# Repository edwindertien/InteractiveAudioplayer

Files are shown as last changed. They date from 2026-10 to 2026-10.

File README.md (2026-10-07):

# Interactive Audio Player
### Seven wearable players · Teensy 4.1 · 7.1 multichannel audio · NFC hand units · haptics

An embedded system for immersive, location-and-encounter based experiences. Each of up to
seven wearers carries a **hand unit** (NFC reader, distance sensor, vibration motor, LED strip).
Touching a hand unit to an **NFC tag** — another person's tag, a narrator tag, an overlay tag
or the start tag — changes what that wearer hears: the audio, a narration layer, overlays,
sound effects and a haptic channel that is felt through the body. The audio itself is a single
8-channel WAV file on an SD card inside each player.

This README is in two parts.

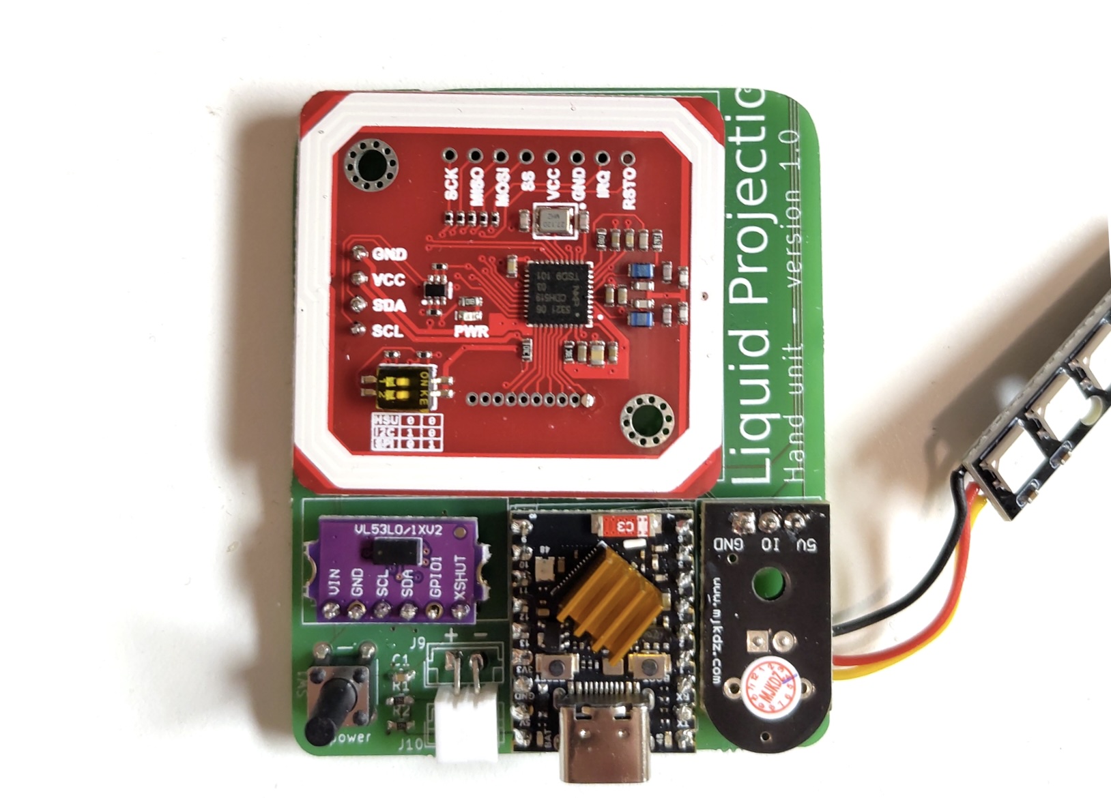
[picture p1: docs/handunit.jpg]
hand unit


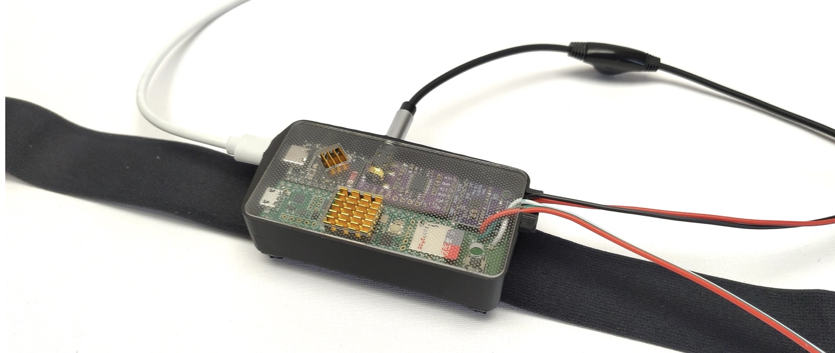
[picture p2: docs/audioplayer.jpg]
audio player


* **Part I — Operation manual:** preparing audio, the SD card and the configuration files,
  pairing the units, and running a show. Everything here needs no programming.
* **Part II — Building and programming:** hardware, setting up VS Code and PlatformIO, flashing
  the three devices, the project structure, and how the software works.

Background on design decisions, dead ends and open issues lives in [Context.md](Context.md).

> **Figures.** Every figure is a PNG; click it for the zoomable SVG. They are generated by
> `tools/make_docs.py` (see [section 17](#17-regenerating-the-figures)).

## Contents

**Part I — Operation manual**
1. [The system at a glance](#1-the-system-at-a-glance)
2. [The workflow in one picture](#2-the-workflow-in-one-picture)
3. [Preparing the audio](#3-preparing-the-audio)
4. [Preparing the SD card](#4-preparing-the-sd-card)
5. [Tags and the configuration files](#5-tags-and-the-configuration-files)
6. [Pairing hand units and body bridges](#6-pairing-hand-units-and-body-bridges)
7. [Running a show](#7-running-a-show)
8. [Changing files without removing the card (USB mode)](#8-changing-files-without-removing-the-card-usb-mode)
9. [Command reference](#9-command-reference)
10. [Troubleshooting](#10-troubleshooting)

**Part II — Building and programming**

11. [Hardware](#11-hardware)
12. [Setting up the development environment](#12-setting-up-the-development-environment)
13. [Building and flashing](#13-building-and-flashing)
14. [Project structure](#14-project-structure)
15. [How it works](#15-how-it-works)
16. [Tools reference](#16-tools-reference)
17. [Regenerating the figures](#17-regenerating-the-figures)

---

# Part I — Operation manual

## 1. The system at a glance

Each player is a set of three devices plus the wearer's tags:

| Device | What it is | What it does |
|---|---|---|
| **Hand unit** | ESP32-S3 SuperMini + PN532 NFC + VL53L0X distance sensor + vibration motor + 5-LED strip + LiPo | Reads tags, feels the distance to a hand, gives instant feedback (vibration, light) and reports to the body bridge |
| **Body bridge** | ESP32-S3 SuperMini | Receives the hand unit's wireless data (ESP-NOW) and passes it to the Teensy over a two-wire serial link; sends a heartbeat back |
| **Player** | Teensy 4.1 + SD card + PCM5102A (headphones) + MAX98357A (haptics) + LED ring | Plays the experience, decides what a tag means, drives headphones and the haptic transducer |

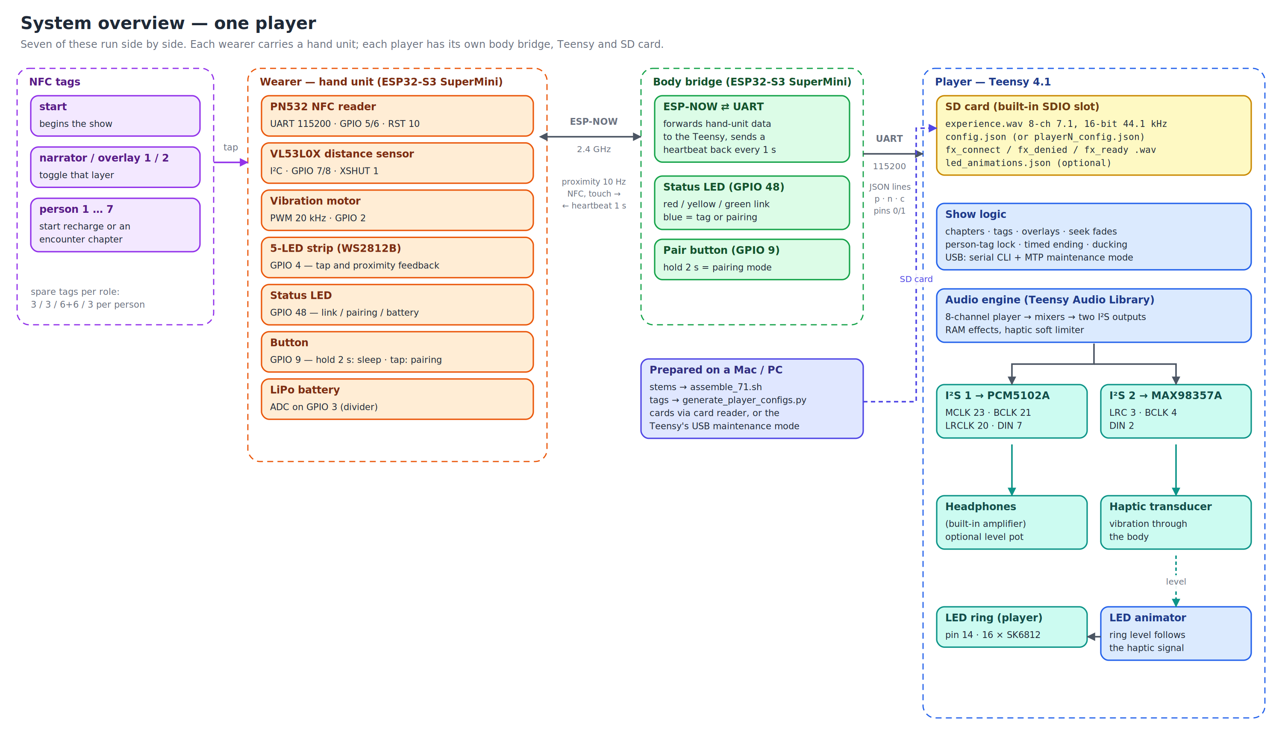
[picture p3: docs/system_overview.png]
System overview


*Seven players run side by side, each with its own hand unit, body bridge, Teensy and SD card.
The pairs are independent: a hand unit talks to exactly one body bridge.*

## 2. The workflow in one picture

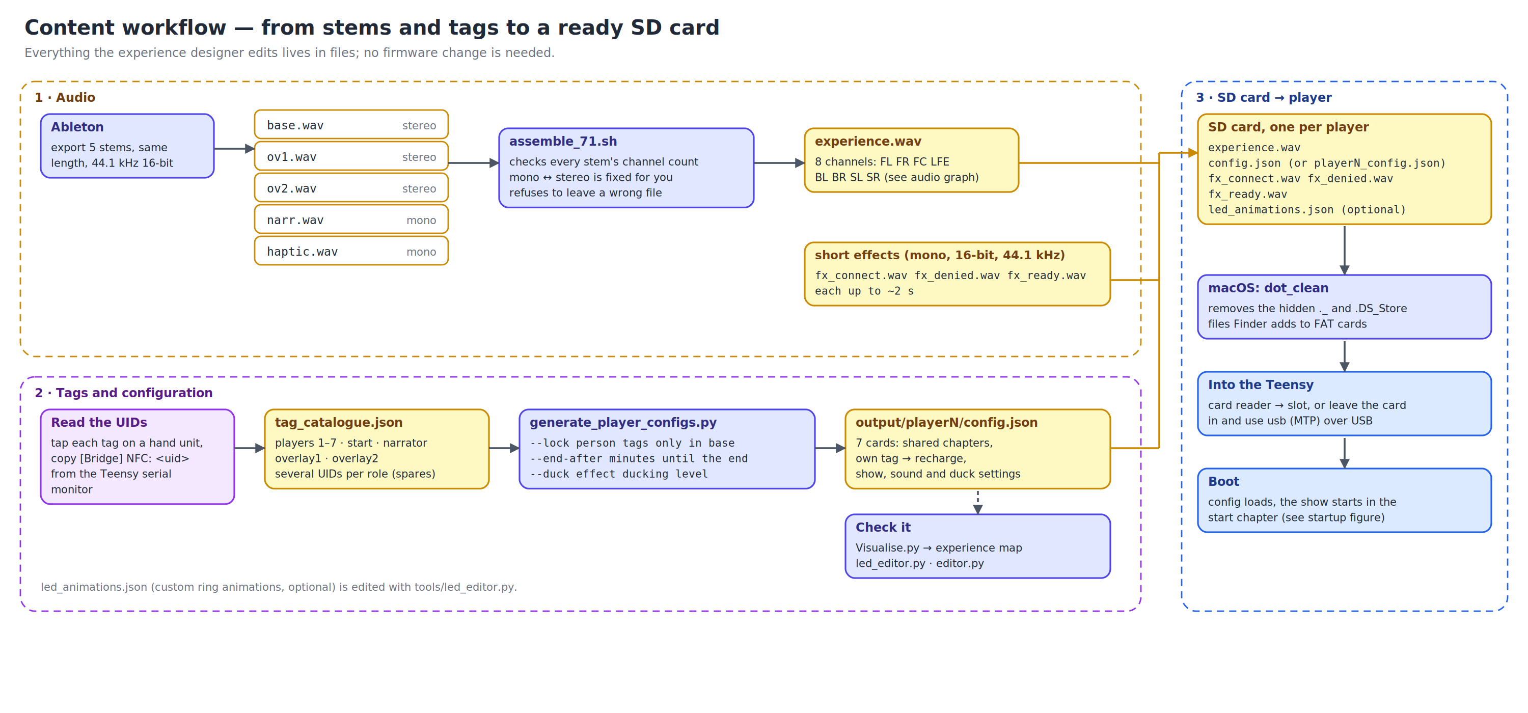
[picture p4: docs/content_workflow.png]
Content workflow


Everything the experience designer edits is a **file**. Nothing in this manual needs a firmware
change. The short version:

1. Export five stems from Ableton and run `assemble_71.sh` → `experience.wav`.  → [section 3](#3-preparing-the-audio)
2. Format the SD cards and copy the files; clean the hidden macOS files.  → [section 4](#4-preparing-the-sd-card)
3. Read the tag UIDs, fill in `tag_catalogue.json`, run `generate_player_configs.py` → seven `config.json`.  → [section 5](#5-tags-and-the-configuration-files)
4. Pair each hand unit with its body bridge.  → [section 6](#6-pairing-hand-units-and-body-bridges)
5. Power everything up and run the show.  → [section 7](#7-running-a-show)

**Tools you need on the Mac/PC:** Python 3, `ffmpeg` (`brew install ffmpeg`), and a serial
monitor (VS Code with PlatformIO, see [section 12](#12-setting-up-the-development-environment),
or any terminal program at 115200 baud).

---

## 3. Preparing the audio

### 3.1 Export the stems from Ableton

Export five files — all **the same length**, on the same tempo grid, **44100 Hz, 16-bit**:

| File | Channels | Content |
|---|---|---|
| `base.wav` | stereo | The main music bed |
| `narr.wav` | **mono** | Narration / operator cues |
| `ov1.wav` | stereo | Overlay stem 1 |
| `ov2.wav` | stereo | Overlay stem 2 |
| `haptic.wav` | **mono** | Low-frequency content that is felt, not heard (the LFE channel) |

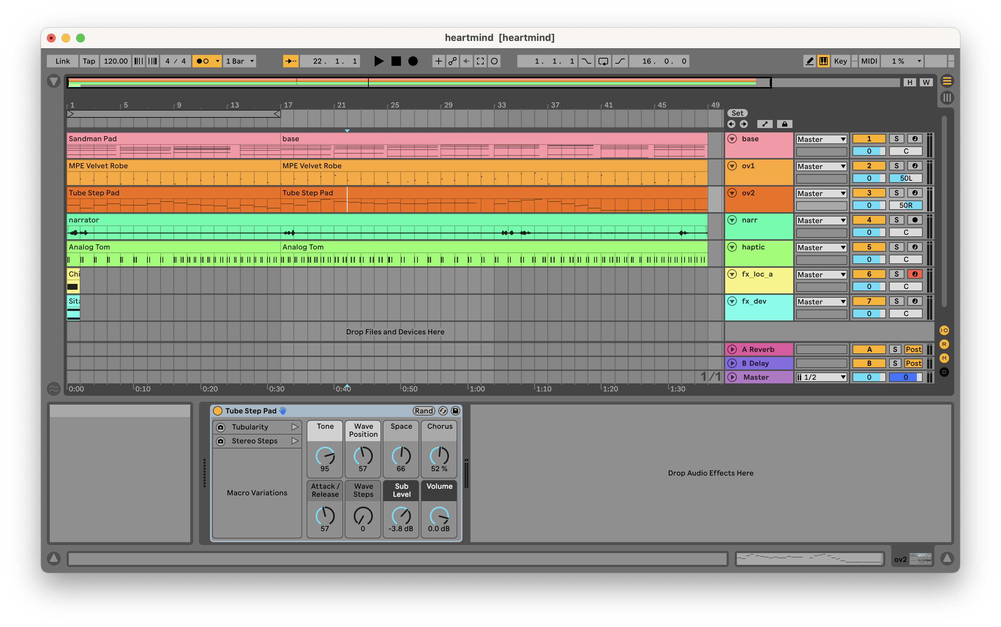
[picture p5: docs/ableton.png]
Ableton arrangement view showing the stem tracks


*The Ableton arrangement: base, narration, two overlays and the haptic stem exported separately.*

> **Mono export in Ableton:** *File → Export Audio/Video* → tick **Convert to Mono**.

### 3.2 Assemble the 8-channel file

```bash
chmod +x experience/assemble_71.sh
./experience/assemble_71.sh base.wav narr.wav ov1.wav ov2.wav haptic.wav experience.wav
```

The script checks every stem's channel count before merging, so a wrong export can no longer
silently shift every later channel:

* `narr.wav` / `haptic.wav` exported as **stereo** → reduced to mono (`(L+R)/2`; set
  `MONO_MODE=left` to take the left channel only). A dual-mono file keeps its exact level.
* `base.wav` / `ov1.wav` / `ov2.wav` exported as **mono** → duplicated to both channels.
* Anything with more than 2 channels, or a file that is not audio → refused with a message.
* The finished file must be **8 channels at 44100 Hz**; if not, it is deleted and the script
  fails. An existing `experience.wav` is left alone if the script fails before writing.
* **Different stem lengths:** the output is cut to the *shortest* stem. The script prints a
  warning with the shortest and longest length — fix the export, otherwise the end of the
  longer stems is silently lost.

Channel order of `experience.wav` (standard 7.1):

| Index | Name | Content | Goes to |
|---|---|---|---|
| 0 | FL | base L | headphones L (always on) |
| 1 | FR | base R | headphones R (always on) |
| 2 | FC | narration | both ears, fades in/out when toggled |
| 3 | LFE | haptic | MAX98357A → haptic transducer, and the player's LED ring |
| 4 | BL | overlay 1 L | headphones L, fades in/out when toggled |
| 5 | BR | overlay 1 R | headphones R, fades in/out when toggled |
| 6 | SL | overlay 2 L | headphones L, fades in/out when toggled |
| 7 | SR | overlay 2 R | headphones R, fades in/out when toggled |

A 7.5-minute experience is about **317 MB** (450 s × 44 100 × 2 bytes × 8 channels).

### 3.3 The sound effects

Three short effects give feedback for tag events. They are loaded into RAM at boot and played
without touching the SD card.

| File | Played when | Slot |
|---|---|---|
| `fx_connect.wav` | a person tag was accepted (a new chapter starts) | 4 |
| `fx_denied.wav` | a person tag was refused (lock on and not in base, or the show is ending) | 5 |
| `fx_ready.wav` | an encounter has ended and you are back in base, ready for the next | 6 |

**Format requirement: 16-bit PCM, mono, 44.1 kHz, up to about 2 seconds.** The player labels
every effect as mono 44.1 kHz and does not resample, so a stereo or 48 kHz file plays at the
wrong speed. The boot log prints one line per effect, e.g.
`slot 4: fx_connect.wav loaded (1ch 420ms … bytes RAM)` — `1ch` confirms a mono file.

Four older slots (`fx_dev.wav`, `fx_loc_a.wav`, `fx_loc_b.wav`, `fx_boot.wav`, slots 0–3) are
still loaded if present and can be triggered by `"do": "fx"` actions or `on_enter_fx`. If the
files are absent you will see four harmless `cannot open` lines at boot.

While any effect plays, the general audio is **ducked** (lowered) so the effect can be heard —
see `duck_level` in [section 5.4](#54-the-configuration-file-reference).

---

## 4. Preparing the SD card

Use a **SanDisk Ultra or Extreme (A1/A2, UHS-I)** card. A generic Class-4 card produced
audible glitches in testing. 16–32 GB is plenty. The Teensy's **built-in slot** (underside of
the board) is used, not a shield's slot.

### 4.1 What goes on the card

```
/ (SD card root)
├── experience.wav          the 8-channel audio (same file on every card)
├── config.json             this player's configuration (differs per card)
├── fx_connect.wav          effect: a person tag was accepted
├── fx_denied.wav           effect: a person tag was refused
├── fx_ready.wav            effect: back in base, ready for the next encounter
└── led_animations.json     optional: custom LED ring animations
```

`config.json` may also be called `playerN_config.json` (for example `player3_config.json`) so
the card is easy to recognise. The player opens **`/config.json`** if it exists; otherwise it
uses the **one** file in the card root whose name ends in `_config.json`. If there are several
such files it refuses to guess and loads nothing — keep exactly one. Hidden macOS `._…` files and
folders are ignored.

### 4.2 Formatting (macOS)

1. Insert the card, open **Disk Utility**, choose *View → Show All Devices*.
2. Select the **card itself** (the top-level device, not the volume below it).
3. Click **Erase** and set:
   * **Name:** something recognisable, e.g. `PLAYER3`
   * **Format:** **MS-DOS (FAT)** (this is FAT32)
   * **Scheme:** **Master Boot Record**
4. Erase. On Windows use the SD Association's *SD Memory Card Formatter* (FAT32).

### 4.3 Copying the files and cleaning up (macOS)

macOS silently writes hidden files to every FAT volume — `._filename` resource-fork files next to
each file you copy, plus `.DS_Store`, `.Spotlight-V100`, `.fseventsd` and `.Trashes`. They clutter
the directory the Teensy reads, so **always clean the card after copying**:

```bash
cp experience.wav            /Volumes/PLAYER3/
cp output/player3/config.json /Volumes/PLAYER3/
cp fx_connect.wav fx_denied.wav fx_ready.wav /Volumes/PLAYER3/

dot_clean /Volumes/PLAYER3/                      # merge/remove the ._ files
rm -rf /Volumes/PLAYER3/.Spotlight-V100 /Volumes/PLAYER3/.fseventsd /Volumes/PLAYER3/.Trashes
ls -la /Volumes/PLAYER3/                         # should list only your files
diskutil eject /Volumes/PLAYER3
```

Copying from the terminal with `cp` avoids most of the clutter; dragging in Finder creates the most.
**Run `dot_clean` again every time you change something on the card.**

### 4.4 Checking a card

Insert it, power the Teensy and open the serial monitor (115200 baud). A healthy boot shows,
in this order: `[SD] mounted OK`, `[Config] Loaded: 10 chapters, 11 tags (39 uids)…`, one line
per effect, `[Boot] Auto-starting -> 'start_arrival'`, `[Audio] Experience started`. The
complete startup order is in [section 15.5](#155-startup-sequences).

If the **onboard LED on the Teensy blinks fast forever**, the SD card could not be mounted
(wrong format, damaged card, or not inserted).

---

## 5. Tags and the configuration files

### 5.1 Tag roles

| Role | Tag type | What touching it does | Spares | Cooldown |
|---|---|---|---|---|
| **start** | `start` | jump to `base` **and start the show clock** (restarts the show if seen again) | 3 | 2 s |
| **person 1…7** | `person` | start a chapter: your **own** person's tag → `recharge`; the other six → `enc_play`, `enc_suspense`, `enc_loneliness`, `enc_nurture`, `enc_pressure`, `enc_shift` (ascending player number, skipping your own) | 3 per person | 4 s |
| **narrator** | `location` | toggle the narration layer | 3 | 1 s |
| **overlay 1** | `location` | toggle overlay 1 | 6 | 1 s |
| **overlay 2** | `location` | toggle overlay 2 | 6 | 1 s |

*Spares* are additional physical tags for the same role: any of them does the same thing and
they share one cooldown. You can program spares without touching any firmware.

> Overlays reset at every chapter change, because the generated chapters use
> `"overlay_mode": "fresh"`. Change a chapter to `"keep"` if an overlay should survive the change.

### 5.2 Reading a tag's UID

1. Open the Teensy's serial monitor at **115200 baud**.
2. Touch the tag to a paired hand unit.
3. Every detection is logged: `[Bridge] NFC: DE0CC698`. Copy the UID.
4. A tag that is not in the config additionally prints
   `[Bridge] Unknown tag: DE0CC698 -- add to config.json` when it is *confirmed*.

To check which role a UID already has: type `tag DE0CC698` in the Teensy serial monitor.

### 5.3 Generating the seven configs

All seven players share the same chapter timeline; only the `tags` section differs. Both the
timeline and the tag logic are generated by a script from one catalogue file.

1. Fill in **`configs/tag_catalogue.json`** — every physical tag, by role. Empty strings are spare
   slots that are not programmed yet (up to 8 tags per role):

   ```json
   {
     "players":  { "1": ["5040DABE", "", ""], "2": ["1033D9BE", "", ""], "...": [] },
     "start":    ["302FD9BE", "", ""],
     "narrator": ["805ADABE", "", ""],
     "overlay1": ["7034DABE", "", "", "", "", ""],
     "overlay2": ["", "", "", "", "", ""]
   }
   ```

2. Run the generator:

   ```bash
   python3 configs/generate_player_configs.py                 # testing build
   python3 configs/generate_player_configs.py --lock          # show build
   python3 configs/generate_player_configs.py --end-after 12 --duck 0.3
   ```

   | Option | Meaning | Default |
   |---|---|---|
   | `--lock` | person tags are only accepted while `base` is playing | off (switch at any time — for testing) |
   | `--end-after MIN` | minutes after the start tag until the ending begins; `0` = never | 10 |
   | `--duck LEVEL` | general-audio level while an effect plays, 0–1; `1` = no ducking | 0.4 |
   | `--catalogue`, `--out` | other input / output location | `configs/tag_catalogue.json`, `output/` |

3. The result is `output/player1/config.json` … `output/player7/config.json`. The generator
   prints how many tags each role still needs, refuses duplicate, malformed or over-limit UIDs
   (and writes nothing in that case), and warns about roles that have no tags yet.

4. **Re-run it and re-copy the configs to the cards whenever you change the catalogue.**

### 5.4 The configuration file reference

You normally never edit a generated config by hand, but you can: it is plain JSON, and changing
a card needs no reflash. Top level:

```json
{
  "device_id":      "PLAYER_1",
  "start_chapter":  "start_arrival",
  "led_brightness": 120,
  "idle":           { "led": { "animation": "breathe", "color": "0x000066", "intensity": 0.35, "speed": 0.2 } },

  "encounter_lock": false,
  "base_chapter":   "base",
  "sounds":         { "connect": 4, "denied": 5, "ready": 6 },
  "end_after_min":  10,
  "end_chapter":    "end_reflection",
  "duck_level":     0.4,

  "chapters": [ … ],
  "tags":     [ … ]
}
```

| Field | Meaning | If absent |
|---|---|---|
| `device_id` | name shown in the boot log | `UNIT_01` |
| `start_chapter` | chapter that plays from power-on (the waiting room) | `intro` |
| `led_brightness` | global LED brightness, 0–255 | 160 |
| `idle.led` | ring pattern when nothing is playing | — |
| `encounter_lock` | `true`: person tags only accepted in `base_chapter` | `false` |
| `base_chapter` | the hub chapter the lock refers to | `base` |
| `sounds` | RAM effect slot per event; `-1` = silent | all `-1` |
| `end_after_min` | minutes after the start tag until the ending begins (e.g. `0.5`); `0` = never | `0` |
| `end_chapter` | chapter that plays last; when it ends, sound and LEDs go off | `end_reflection` |
| `duck_level` | general audio is lowered to this fraction while an effect plays; `1` = off | `1` (off) |

#### Chapters

```json
{
  "id": "enc_play", "label": "Encounter — Play",
  "start_ms": 135000, "loop_end_ms": 180000,
  "loop": false, "returns_to": "base",
  "on_enter_fx": -1, "overlay_mode": "fresh",
  "overlays": { "ov1": false, "ov2": false, "narr": false },
  "led_background": { "animation": "level", "color": "0xCC4400", "intensity": 0.6, "speed": 0.3 },
  "led_enter":      { "animation": "flash", "color": "0xFFFFFF", "intensity": 0.6, "speed": 0.6, "duration_ms": 600 }
}
```

| Field | Description |
|---|---|
| `id` | unique name, used by tags, `start_chapter`, `returns_to`, `end_chapter` |
| `label` | human-readable name (serial debug and the map) |
| `start_ms` / `loop_end_ms` | the region of `experience.wav` this chapter plays |
| `loop` | `true`: loops between the two times · `false`: plays once |
| `returns_to` | for a non-looping chapter: the chapter to continue with when it ends; empty = go idle |
| `on_enter_fx` | RAM effect slot played on entry, `-1` = none |
| `overlay_mode` | `"fresh"`: apply `overlays` on entry · `"keep"`: inherit the current state |
| `overlays` | default state of `ov1`, `ov2`, `narr` (used when `fresh`) |
| `led_background` | the ring's persistent pattern in this chapter |
| `led_enter` | a one-shot flash when the chapter starts |

The generated timeline is ten 45-second chapters (7:30 in all):

| Chapter | Time | Plays | After it ends |
|---|---|---|---|
| `start_arrival` | 0:00 – 0:45 | loops | — (the waiting room) |
| `base` | 0:45 – 1:30 | loops | — (the hub) |
| `recharge` | 1:30 – 2:15 | once | `base` |
| `enc_play` | 2:15 – 3:00 | once | `base` |
| `enc_suspense` | 3:00 – 3:45 | once | `base` |
| `enc_loneliness` | 3:45 – 4:30 | once | `base` |
| `enc_nurture` | 4:30 – 5:15 | once | `base` |
| `enc_pressure` | 5:15 – 6:00 | once | `base` |
| `enc_shift` | 6:00 – 6:45 | once | `base` |
| `end_reflection` | 6:45 – 7:30 | once | sound and LEDs off |

To change the chapter times or LED colours for all seven cards, edit the `CHAPTERS` list in
`configs/generate_player_configs.py` and regenerate.

#### Tags and actions

```json
{
  "label": "Meet player 2 -> enc_play",
  "type": "person",
  "cooldown_ms": 4000,
  "uids": ["1033D9BE", "1033000A", "1033000B"],
  "actions": [ { "do": "chapter", "target": "enc_play" } ]
}
```

| Field | Description |
|---|---|
| `uid` and/or `uids` | one UID, or a list of spares (up to 8), upper-case hex; lower case is accepted and converted. A UID listed under two roles gives a warning; the first entry wins |
| `label` | description, shown in logs |
| `type` | `person`, `start`, `location` or the legacy `device`. Only `person` is affected by the lock and the ending; only `start` starts the clock |
| `cooldown_ms` | minimum time between two accepted touches of this role |
| `actions` | what to do (below) |

| `"do"` | Parameters | Effect |
|---|---|---|
| `"chapter"` | `"target": "id"` | jump to a chapter with a crossfade |
| `"overlay"` | `"target": "ov1"/"ov2"/"narr"`, `"value": "on"/"off"/"toggle"` | fade a layer in or out |
| `"fx"` | `"slot": 0-7` | play a RAM effect |
| `"led"` | `animation`, `color`, `intensity`, `speed`, `duration_ms` | a one-shot ring event |

A card holds at most **32 tag entries**; because spares share an entry, the full catalogue
(39 physical tags per card) needs only 11.

#### LED animations

Parameters: `color` = `"0xRRGGBB"` · `intensity` = 0–1 · `speed` = 0–1 · `duration_ms` (one-shots only).

| Name | Uses colour | Description |
|---|---|---|
| `level` | ✓ | **haptic sync** — the live envelope of the LFE channel |
| `heartbeat` | ✓ | **haptic sync** — a lub-dub shape |
| `breathe` | ✓ | smooth pulse between 25 % and 100 % |
| `solid` | ✓ | constant colour |
| `sparkle` | tint | dim base with random sparks |
| `fire` · `ocean` · `rainbow` | — | own palettes |
| `pulse_ring` | ✓ | ring expanding from the centre |
| `spin` | ✓ | an arc rotating around the ring |
| `flash` | ✓ | three quick flashes, then a dim hold |
| `confetti` | tint | random colour bursts |
| `comet` | ✓ | a dot racing with a trail |
| `off` | — | dark |

Custom animations are drawn with `tools/led_editor.py` and saved as `led_animations.json`
on the card; use the animation's `id` in any `animation` field. The animator checks custom ids
*before* the built-in names, so give custom animations distinct names.

### 5.5 Looking at a configuration

`experience/Visualise.py` draws a configuration: chapters on a timeline, overlay defaults, LED
colours, where every chapter goes when it ends, the start and end chapter, and which tag does what.

```bash
python3 experience/Visualise.py output/player1/config.json map.html --svg map.svg --png map.png
```

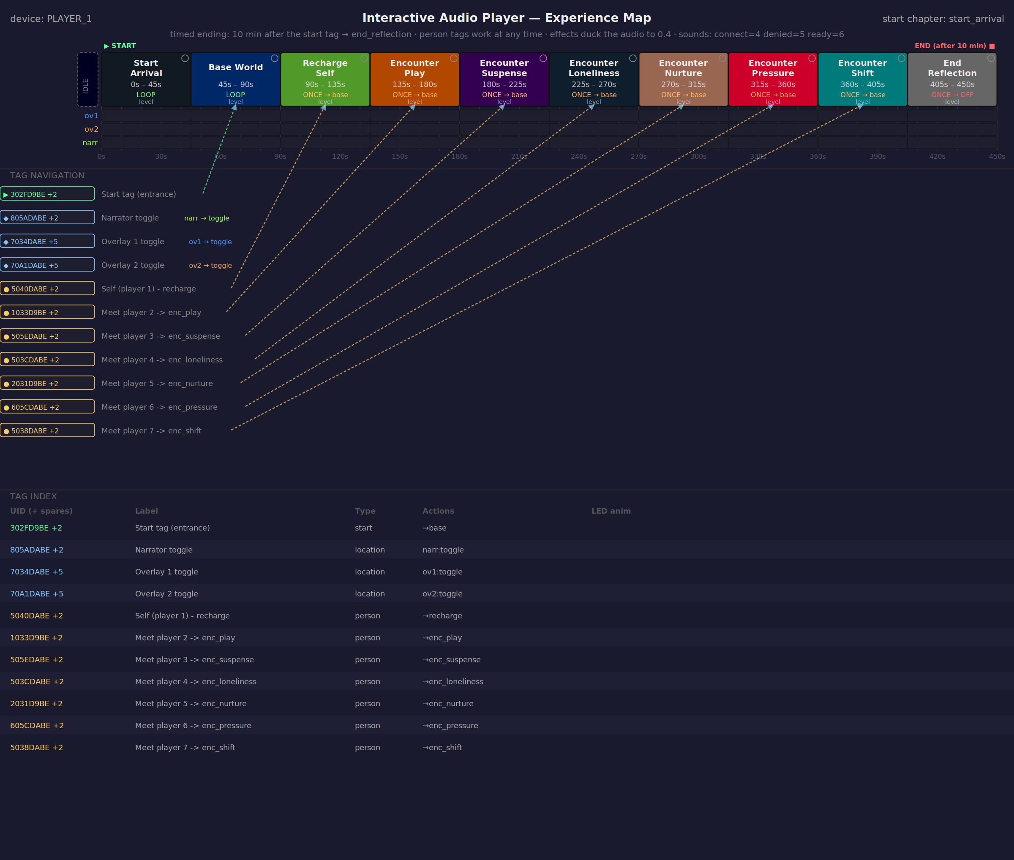
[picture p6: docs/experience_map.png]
Experience map of an example card


*Player 1's card. The tag rows show the first UID of each role and `+N` for its spares. Open
`docs/experience_map.html` for the same map in a browser.*

### 5.6 Editing tools and their limits

| Tool | Use it for | Limits |
|---|---|---|
| `configs/generate_player_configs.py` | **the normal way**: tags, timeline, show settings for all seven cards | chapter list is in the script |
| `tools/led_editor.py` | designing custom ring animations (`led_animations.json`) and previewing the built-ins | — |
| `tools/editor.py` | a web editor (http://localhost:8080) for one `config.json`: chapters, LEDs, overlays | shows only a single `uid` box and the old `location`/`device` types; it does **not** edit `uids` lists, `person`/`start` types or the newer top-level settings. It keeps them when it saves (it writes the whole object back), but edit those in a text editor |

Keep the generator's output as the master: if you hand-edit one card, remember that regenerating
overwrites it.

---

## 6. Pairing hand units and body bridges

A hand unit and a body bridge must be **paired** once; each stores the other's MAC address in
flash, so the pairing survives reboots and sleep. Pairing needs both units powered, close together,
and the hand unit **awake** — see the power notes in [section 7.1](#71-switching-on-and-off).

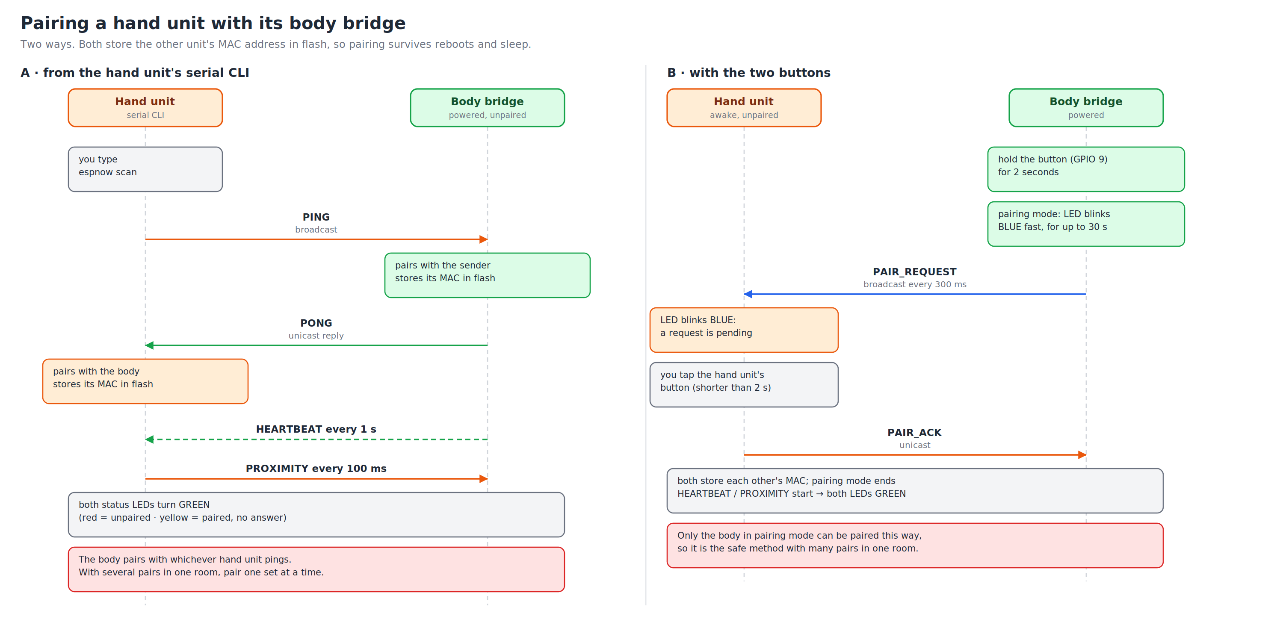
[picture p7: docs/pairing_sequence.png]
Pairing sequence


### Method A — from the hand unit's serial CLI (verified)

1. Power the body bridge. Connect the hand unit to the computer, wake it (press its button) and
   open its serial monitor (115200 baud).
2. Type `espnow scan`. The hand unit broadcasts a PING, the body bridge pairs with the sender and
   answers; the hand unit pairs on the answer.
3. Both status LEDs turn **green**. In the hand unit's monitor you see `Paired: <MAC>` and then a
   `rx type=0x12` line every second (the heartbeat).

The body bridge pairs with **whichever hand unit pings**. With several pairs in one room, pair one
set at a time (power the others off) or use method B.

### Method B — with the two buttons

1. On the **body bridge**, hold the button (GPIO 9) for 2 seconds. Its status LED blinks **blue**
   fast: pairing mode, for up to 30 seconds. It broadcasts a pairing request every 300 ms.
2. The hand unit's status LED starts blinking **blue**: a request is pending.
3. **Tap the hand unit's button** (shorter than 2 seconds — a longer press puts it to sleep).
4. Both LEDs turn **green** and pairing mode ends.

Only the body bridge in pairing mode can be paired this way, so it is the safe method for several
pairs in one room. *Status: implemented and part of the firmware; this procedure had not been
confirmed end to end when this manual was written — if it fails, use method A and see
[Context.md](Context.md).*

### Checking and clearing

| | Hand unit | Body bridge |
|---|---|---|
| Show the pairing | `espnow` | `status` |
| Forget the pairing | `espnow clear` | `clear` |
| Set a peer by hand | `espnow bind <MAC>` | — |
| This unit's MAC | printed at boot (`[ESPNOW] MAC: …`) | `mac` |

`espnow bind <MAC>` sets only the **hand unit's** side of the pairing. The body bridge ignores data from a hand unit it has not
paired with (by `espnow scan` or the buttons), so `bind` alone is not a way to pair. *(Read from the code; not tested.)*

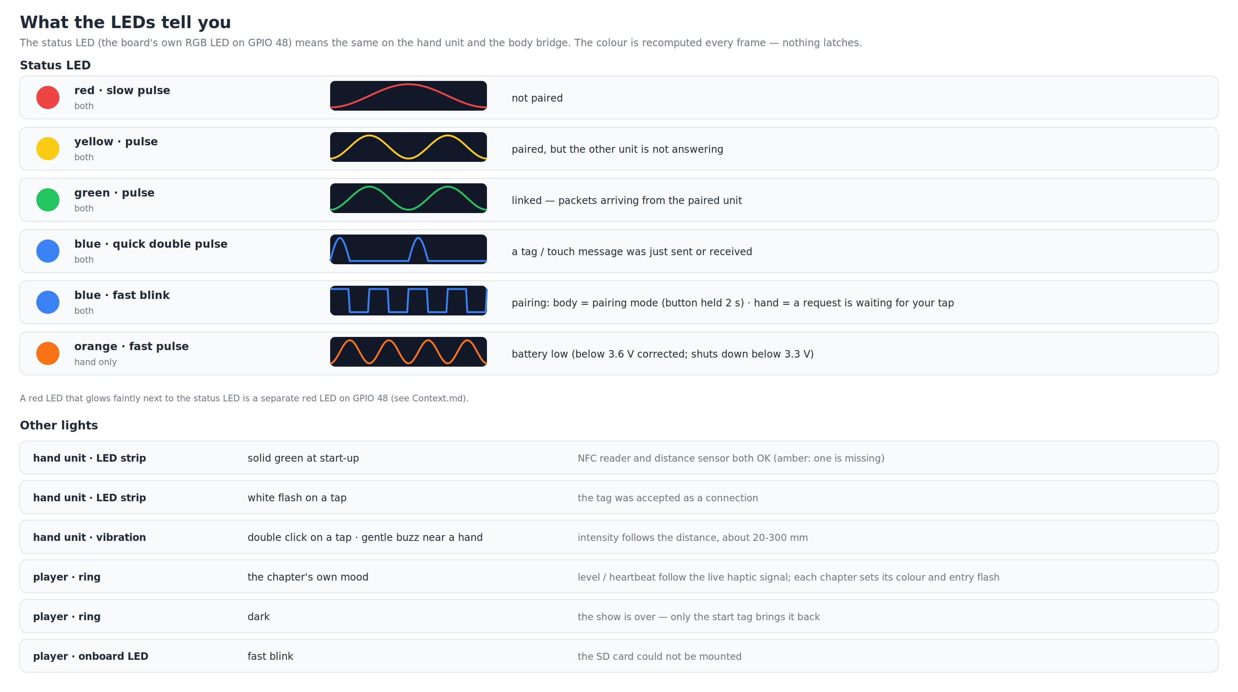
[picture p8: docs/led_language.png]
LED language


*What the status LEDs mean on the hand unit and the body bridge.*

Label each pair (a sticker with the player number on both) — the units are otherwise identical.

---

## 7. Running a show

### 7.1 Switching on and off

* **Hand unit.** Connecting the battery or pressing reset makes the unit go **straight back to
  sleep**; **press the button** to start it. Once it is running, **hold the button for 2 seconds** to
  put it to sleep (the status LED flashes orange to confirm); press it again to wake. At start-up
  the LED strip lights **green** (NFC reader and distance sensor both found) or **amber** (one is
  missing), with two short vibration pulses.
* **Body bridge.** Powered whenever its supply is on; it has no sleep mode.
* **Player (Teensy).** Starts playing the waiting room as soon as it is powered — no tag needed.

The battery is monitored every 10 s: **orange fast pulse** on the status LED below 3.6 V, automatic
sleep below 3.3 V. On USB the battery cannot be measured and the unit says so
(`USB powered … battery not measurable`). See [section 9.2](#92-hand-unit-serial-monitor-115200-baud) for calibration.

### 7.2 A show

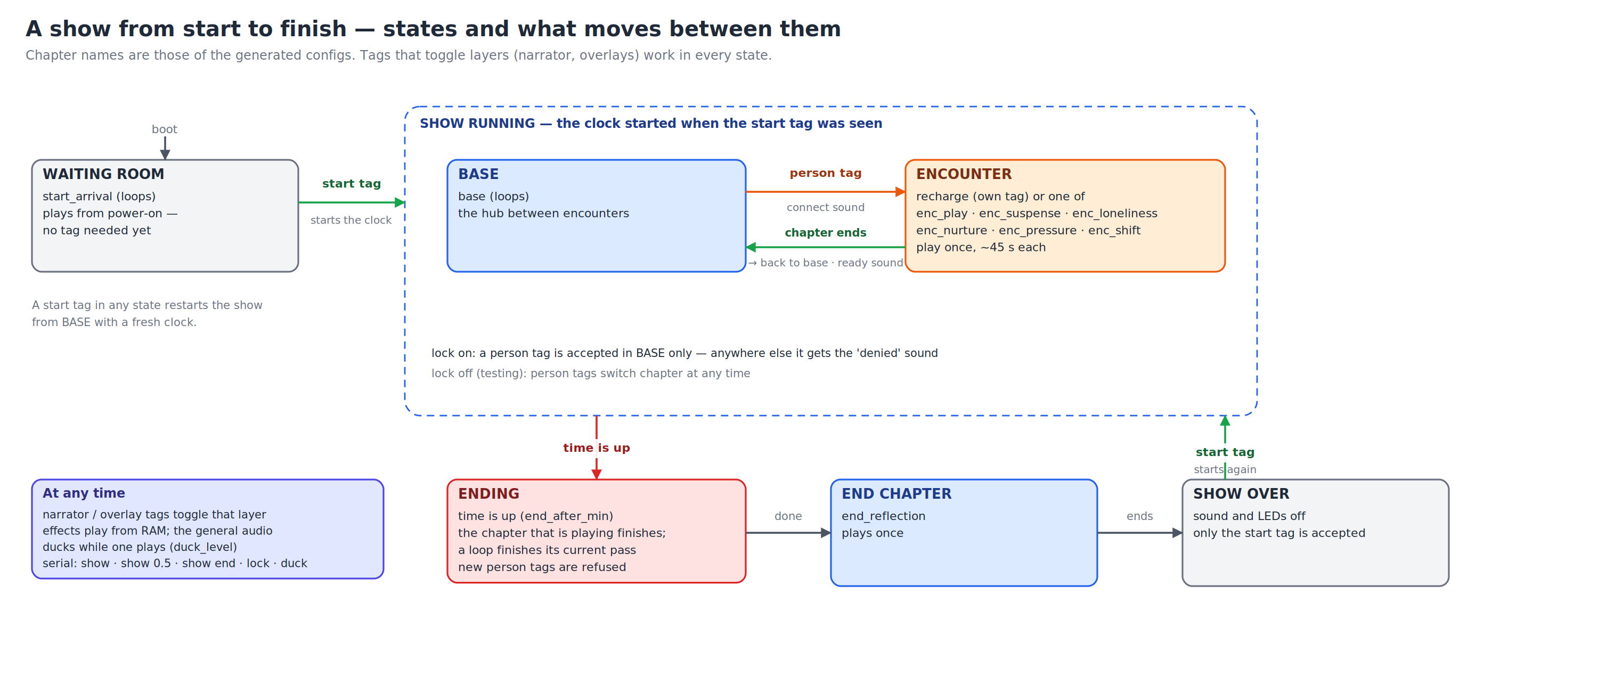
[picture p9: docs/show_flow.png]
A show from start to finish


1. **Waiting room.** `start_arrival` loops from power-on.
2. **Start tag.** The wearer touches the start tag: `base` starts and the show clock begins.
3. **Encounters.** Touching another person's tag starts that encounter chapter (about 45 s) with the
   *connect* sound. Touching your own tag starts `recharge`. When the chapter ends you are back in
   `base` with the *ready* sound. With `--lock` (show build) a person tag is only accepted in `base`;
   anywhere else it gets the *denied* sound. Without it (testing build) person tags switch at any time.
4. **Layers.** Narrator and overlay tags toggle that layer in every state. Effects play from RAM and the
   general audio ducks while one plays.
5. **The ending.** `end_after_min` after the start tag the show wraps up: the chapter that is playing
   finishes (a looping chapter such as `base` finishes its current pass), new person tags are refused,
   then `end_reflection` plays.
6. **Over.** When `end_reflection` ends, the player's **sound and LED ring go off**. Hand units and body
   bridges keep running. Only the **start tag** is accepted now; it begins a new show from `base`.
   Rebooting the player also restarts everything.

Testing without waiting: `show 0.5` on the Teensy sets the ending to 30 seconds, `show end`
forces it now, `show start` does what the start tag does, `show` prints the state.

### 7.3 Before the doors open — checklist

- [ ] Every card has `experience.wav`, one `config.json`, the three effects; `dot_clean` was run
- [ ] Show build of the configs (`--lock`, the right `--end-after`)
- [ ] Hand units charged; each paired (green status LED) and labelled with its player number
- [ ] The Teensy log shows `[Config] Loaded …`, three effects loaded, no `Unknown tag` for any tag you hand out
- [ ] Each tag works: touch it, see the right chapter/overlay change in the Teensy log
- [ ] Headphones plugged in, volume pot where you want it, haptic transducer felt
- [ ] A last full run with `show 1` to hear the ending and the switch-off

---

## 8. Changing files without removing the card (USB mode)

The SD card sits under the Teensy and is awkward to remove. **USB maintenance mode** shares the card
with the computer over the Teensy's USB cable while the board stays in its case.

1. Connect the Teensy by USB and open the serial monitor (115200 baud).
2. Type **`usb`**. Playback stops, the LED ring spins **cyan**, and the card is shared over **MTP** as
   `SD Card`.
3. Open an **MTP client** on the computer. macOS has no built-in MTP support; use a third-party client
   (OpenMTP is one). Copy `config.json`, `experience.wav` or effects across.
4. Type **`reboot`**. The player restarts and reloads everything.

While in USB mode the player ignores tags and every command except `reboot` — the card belongs to the
computer. Large files (`experience.wav` is ~300 MB) take a while. If you also used Finder on the card,
run `dot_clean` once it is back in a reader.

---

## 9. Command reference

All three devices have a serial console at **115200 baud**. Commands are typed in the
monitor and confirmed with Enter.

### 9.1 Teensy player

| Command | Effect |
|---|---|
| `chapters` | list the chapters: times, loop or once, effect, LED, where they go next |
| `tags` | list the tag entries: first UID, number of UIDs, type, label, actions |
| `tag <uid>` | which role does this UID have? |
| `go <id>` | jump to a chapter (starts the audio if it is not running) |
| `seek <ms>` | seek to a raw time |
| `narr` · `ov1` · `ov2` | toggle that layer |
| `fx <n>` | play RAM effect slot *n* (`fx 4`, `fx 5`, `fx 6` test the three feedback sounds) |
| `bridge` | state of the link to the body bridge: alive, age of the last message, distance, touch |
| `show` | the show state: waiting, running (minutes elapsed), ending, over |
| `show <minutes>` | set the time until the ending (`show 0.5`); `show 0` = never. Not saved |
| `show start` / `show end` | do what the start tag does / force the ending now |
| `lock [on\|off]` | person tags only accepted in `base` / at any time. Not saved |
| `duck [0-1]` | show or set the ducking level (`duck 0.3`; `1` = off). Not saved |
| `haptic` · `haptic reset` | haptic settings and the loudest haptic peak seen · clear that peak |
| `hdrive <k>` | haptic soft-limiter drive, 0 = bypass … 8 (the default is 0.5) |
| `hgain <g>` | haptic mixer gain 0–4 (above 1 the mixer hard-clips — use `hdrive` for loudness) |
| `usb` | enter USB maintenance mode ([section 8](#8-changing-files-without-removing-the-card-usb-mode)) |
| `reboot` | restart the player |

Values set from the console are not saved; put the final value in the configuration (or the
`#define` at the top of `main.cpp`).

### 9.2 Hand unit (serial monitor, 115200 baud)

| Command | Effect |
|---|---|
| `help` | the command list |
| `status` · `debug` | all sensor readings · dump all state |
| `stream` | toggle a live distance stream |
| `scan` | I²C scan |
| `rainbow` · `solid <r> <g> <b>` · `bright <0-255>` · `off` · `idle` | LED test modes |
| `motor <pulses>` | trigger a vibration burst |
| `nfc` | re-run NFC init and poll for 3 s |
| `sleep` | go to deep sleep |
| `espnow` · `espnow scan` · `espnow bind <MAC>` · `espnow clear` · `espnow test` | pairing and link ([section 6](#6-pairing-hand-units-and-body-bridges)) |
| `battery` | battery level, rail voltage, divider-pin voltage, offset |
| `battery cal <batV> <pinV>` | set this unit's offset from two multimeter readings taken **on battery**: the voltage at the battery terminals and at GPIO 3, e.g. `battery cal 3.80 1.74` |
| `battery offset <mV>` · `battery clear` | set the offset directly · back to the default |
| `tof` | distance-sensor diagnostics: settings, counters, status codes seen |
| `tof raw` | toggle: print every measurement with its status, signal rate and SPAD count |
| `tof rate <mcps>` · `tof budget <ms>` · `tof period <ms>` · `tof long on\|off` | sensor tuning |
| `tof min <mm>` · `tof max <mm>` | the window of readings that count |
| `tof defaults` · `tof save` · `tof clear` · `tof reset` | defaults · store/erase this unit's settings in flash · clear counters |

**Battery:** the voltage divider on this board hangs on the board's 5 V rail behind a Schottky diode,
so on battery the reading is the cell voltage minus about 0.3 V. The firmware adds a per-unit offset
(default 320 mV) and treats any rail above 4.3 V as USB power ("battery not measurable").

### 9.3 Body bridge

| Command | Effect |
|---|---|
| `status` | pairing, last packet, counters for the paired hand, uptime, foreign traffic |
| `mac` | this unit's MAC address |
| `stream` | toggle a continuous proximity stream |
| `clear` | forget the paired hand unit |
| `help` · `?` | the list |

---

## 10. Troubleshooting

| Symptom | Likely cause | What to do |
|---|---|---|
| Teensy's onboard LED blinks fast forever | SD card not mounted | reformat FAT32 ([4.2](#42-formatting-macos)); check the card is seated |
| `[Config] ERROR: cannot open /config.json` | no `config.json`, or it is named something else | name it `config.json`, or keep exactly one `*_config.json` ([4.1](#41-what-goes-on-the-card)) |
| `[Config] ERROR: … files match *_config.json` | several `*_config.json` on the card | remove all but one |
| No headphone sound, haptics fine | PCM5102A muted: its `H3L` (XSMT) jumper is not bridged to **HIGH** | bridge `H3L` to H; `H1L`, `H2L`, `H4L` to L |
| No haptics, headphones fine | MAX98357A in shutdown: its SD pin must be tied to VIN | check the wiring ([11.3](#113-the-audio-boards)) |
| No audio and `[Audio] ERROR: experience.wav not found` | file missing or misnamed | check the card; run `dot_clean` |
| Stuttering / clicking audio | slow card, or hidden macOS files | SanDisk A1/A2 card; `dot_clean` |
| Hand unit "does nothing" after connecting power | it goes to sleep after a reset | press the button once |
| Start-up LEDs are **amber**, or `nfc` finds no reader | the PN532 is not in UART mode, is miswired, or its reset line is wrong | DIP switches SEL0 = SEL1 = LOW; wiring GPIO 5 / 6 / 10 ([11.2](#112-pinouts)); the init sequence is in [Context.md](Context.md) |
| Status LED **red** | not paired | pair ([6](#6-pairing-hand-units-and-body-bridges)) |
| Status LED **yellow** | paired, but the other unit is not answering | is the other unit on? in range? same pair? |
| LED colours swapped (red shows green) | a **v0.0.2** SuperMini board (RGB order); the standard board is GRB | use the standard board, or build with `-DSTATUS_LED_ORDER=RGB` |
| Touching a tag does nothing | the UID is not in the config (`Unknown tag` in the log); or the tag's cooldown has not elapsed; or the show is over / ending / locked | check the log: it says why (`ignored`, `refused`, `cooling down`) |
| After the show nothing responds | the show is over | touch the **start tag**, or reboot the player |
| A person tag gets the *denied* sound | the lock is on and you are not in `base`, or the show is ending | finish the chapter first; `lock off` for testing |
| Effects are inaudible | the general audio is too loud | set `duck_level` lower ([5.4](#54-the-configuration-file-reference)); try `duck 0.3` live |
| An effect plays too slowly / too long | file is stereo or not 44.1 kHz | re-export mono 16-bit 44.1 kHz |
| `assemble_71.sh` reports a channel count problem | a stem has the wrong number of channels | re-export; the message names the file |
| Output shorter than the stems | stems have different lengths; the output is cut to the shortest | re-export all stems with the same length |
| Hand-unit battery shows 4.8 V | the unit is on USB: the rail is USB power | run on battery; calibrate with `battery cal` |
| Orange low-battery pulse at a real 3.8 V | missing diode correction | `battery cal <batV> <pinV>` |
| Distance sensor only reacts when very close | weak return signal, or the signal-rate limit | run `tof raw` and read the status codes and signal rate; compare with a good unit ([Context.md](Context.md)) |
| Build error `'FS' has not been declared` / `redefinition of 'class MTPStorage'` (Teensy) | FastLED 3.10.2/3.10.3 with the MTP USB type, or the external MTP library added | keep FastLED at 3.10.1; do not add the MTP_Teensy library ([12.3](#123-library-and-platform-pins)) |
| ESP32 build error about ESP-NOW callback signatures | wrong Arduino core (3.x) | pin `platformio/espressif32@6.13.0` ([12.3](#123-library-and-platform-pins)) |

---

# Part II — Building and programming

## 11. Hardware

### 11.1 Parts

| Part | Notes |
|---|---|
| Teensy 4.1 | 600 MHz Cortex-M7; built-in SDIO SD slot; USB serial + MTP |
| PCM5102A DAC module | headphone audio on I²S 1; solder-jumper settings below |
| MAX98357A amplifier module | haptic transducer on I²S 2 |
| Headphones with built-in amplifier | an analog potentiometer reduces the level |
| 16-LED ring (SK6812 / WS2812) | on the player, pin 14 |
| 2 × ESP32-S3 SuperMini | one for the hand unit, one for the body bridge. Use the **standard** boards, not v0.0.2 (different LED colour order and USB wiring) |
| PN532 NFC module | hand unit; DIP switches **SEL0 = LOW, SEL1 = LOW** (UART / HSU mode) |
| VL53L0X time-of-flight module | hand unit; distance to a hand |
| Vibration motor | hand unit; switched by an N-channel MOSFET from a PWM pin |
| 5-LED WS2812B strip | hand unit; an 8-LED strip cut down to 5 (the player has its own 16-LED ring) |
| LiPo battery (1S, 3.0–4.2 V) | hand unit; charged through the SuperMini's TP4054 |
| Push buttons | hand unit (GPIO 9), body bridge (GPIO 9) |
| SanDisk Ultra / Extreme A1 or A2 SD card | one per player |

### 11.2 Pinouts

**Teensy 4.1**

| Function | Pins |
|---|---|
| I²S 1 → PCM5102A | MCLK 23 · BCLK 21 · LRCLK 20 · DIN 7 |
| I²S 2 → MAX98357A | LRC 3 · BCLK 4 · DIN 2 |
| Body-bridge UART (Serial1, 115200) | pin 0 (RX1) ← bridge GPIO 43 (TX) · pin 1 (TX1) → bridge GPIO 44 (RX) · common GND |
| LED ring (16 × SK6812) | pin 14, 5 V and GND (an external 5 V supply is recommended) |
| SD card | built-in SDIO slot |
| Onboard LED | pin 13: fast blink = SD mount failed |

**Hand unit — ESP32-S3 SuperMini**

| Function | GPIO |
|---|---|
| LED strip (WS2812B, 5 LEDs, GRB) | 4 |
| Vibration motor (PWM 20 kHz, 8 bit) | 2 |
| VL53L0X: SDA / SCL / XSHUT | 7 / 8 / 1 |
| PN532 (UART 115200): TX / RX / RST | 6 / 5 / 10 |
| Status LED (onboard RGB) | 48 |
| Button (to GND, internal pull-up) | 9 |
| Battery divider (1:2, equal resistors) | 3 |

**Battery divider.** Two equal resistors (100 kΩ each according to `Config.h`; a comment in `PowerManager.h` says 220 kΩ — measure
your board), mid-point to GPIO 3. The original design notes show a 100 nF capacitor from GPIO 3 to ground. The top of the divider is on
the SuperMini's **5 V rail**, not directly on the cell — see [Context.md](Context.md) and [section 9.2](#92-hand-unit-serial-monitor-115200-baud).

**Hand-unit LED strip.** The hand unit's ring was replaced by a strip of **5 WS2812B LEDs**, an 8-LED strip cut down to size. Cut it at the
strip's marked cut line (between two LEDs) and keep the end with the data-in arrow towards the ESP32 — as with any WS2812 strip, only the
first LED's data-in is wired (to GPIO 4, with 5 V and GND). Then set `LED_COUNT` in `ESP32handUnit/src/Config.h` to **5** and reflash.
The firmware depends on the count only through `LED_COUNT` (the array, the driver setup, and the spacing of the idle wave and of the
`rainbow` test, which is `256 / LED_COUNT`). The 16-LED ring described for the **player** (Teensy pin 14) is a different part and is unchanged.

**Body bridge — ESP32-S3 SuperMini**

| Function | GPIO |
|---|---|
| Teensy UART (Serial1, 115200): TX / RX | 43 / 44 |
| Status LED (onboard RGB) | 48 |
| Pair button (to GND, internal pull-up) | 9 |

### 11.3 The audio boards

* **PCM5102A:** its four solder jumpers set the filter, de-emphasis, soft-mute and format. Bridge
  `H1L` (FLT) to L, `H2L` (DEMP) to L, **`H3L` (XSMT) to H**, `H4L` (FMT, I²S) to L. The factory
  default leaves `H3L` low, which keeps the output muted. The module's `SCK` pin is grounded
  (its internal PLL generates the clock).
* **MAX98357A:** tie **SD to VIN** (it has an internal pull-down, so a floating SD pin means
  shutdown). GAIN floating gives 9 dB; GAIN to GND 12 dB; GAIN through 100 kΩ to GND 15 dB (per the
  datasheet).
* The haptic signal is mono and is sent to both I²S 2 channels.

### 11.4 PCBs

Two boards were designed for this project. Schematics and board layouts are exported as PNG (shown
here) and PDF. *The files in `docs/` are placeholders until the real exports are dropped in under the
same names.*

**Player PCB** — Teensy 4.1 carrier with the PCM5102A, the MAX98357A, the LED-ring connector and the
bridge UART.

| Schematic | Board layout |
|---|---|
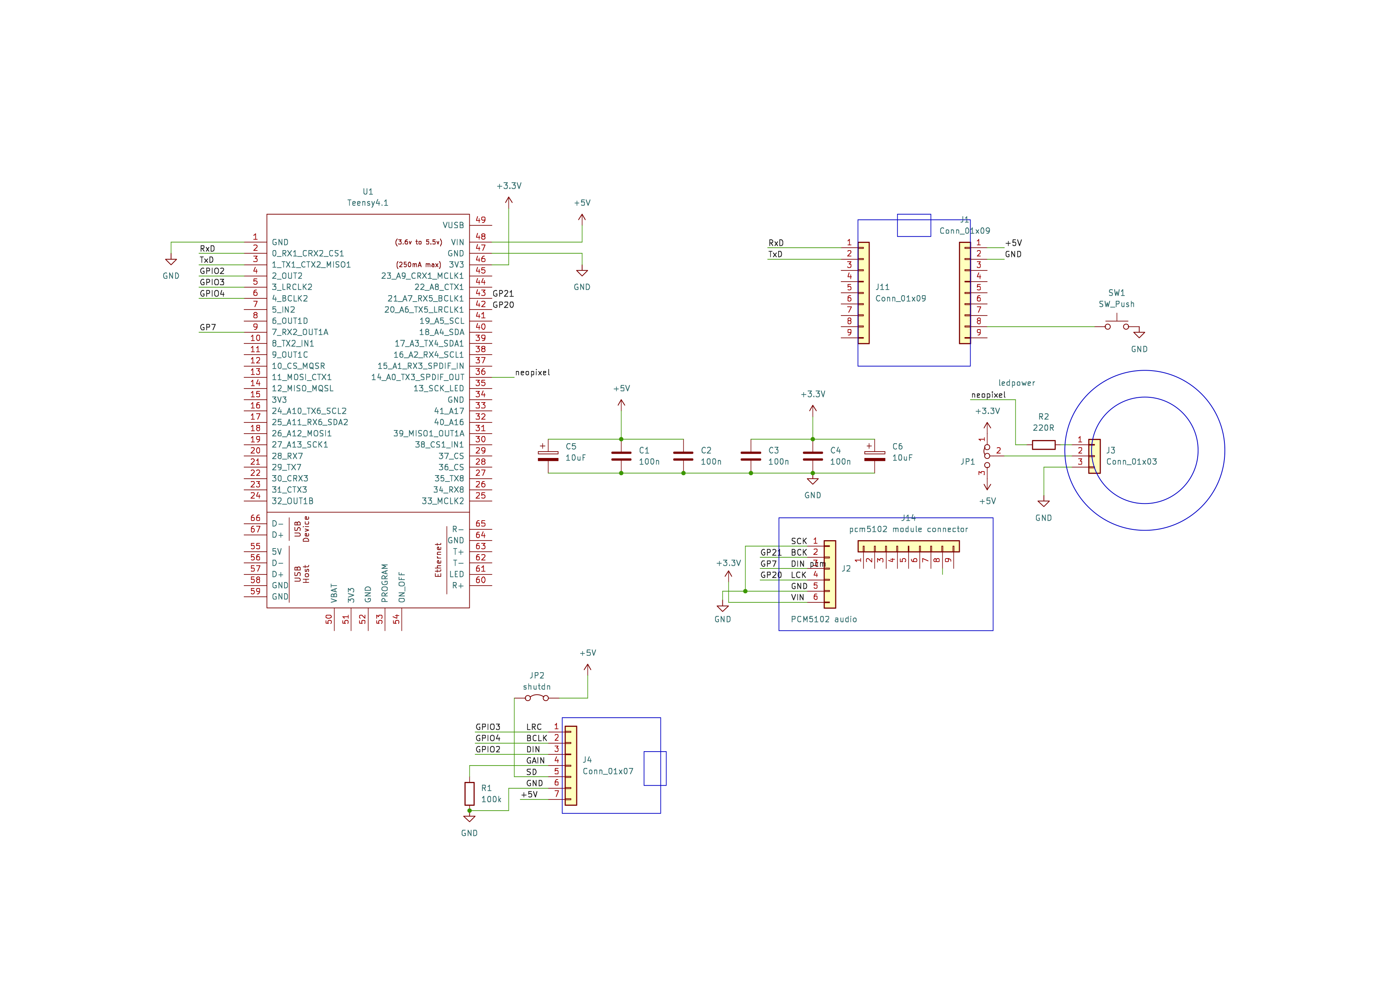
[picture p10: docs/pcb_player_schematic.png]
Player schematic
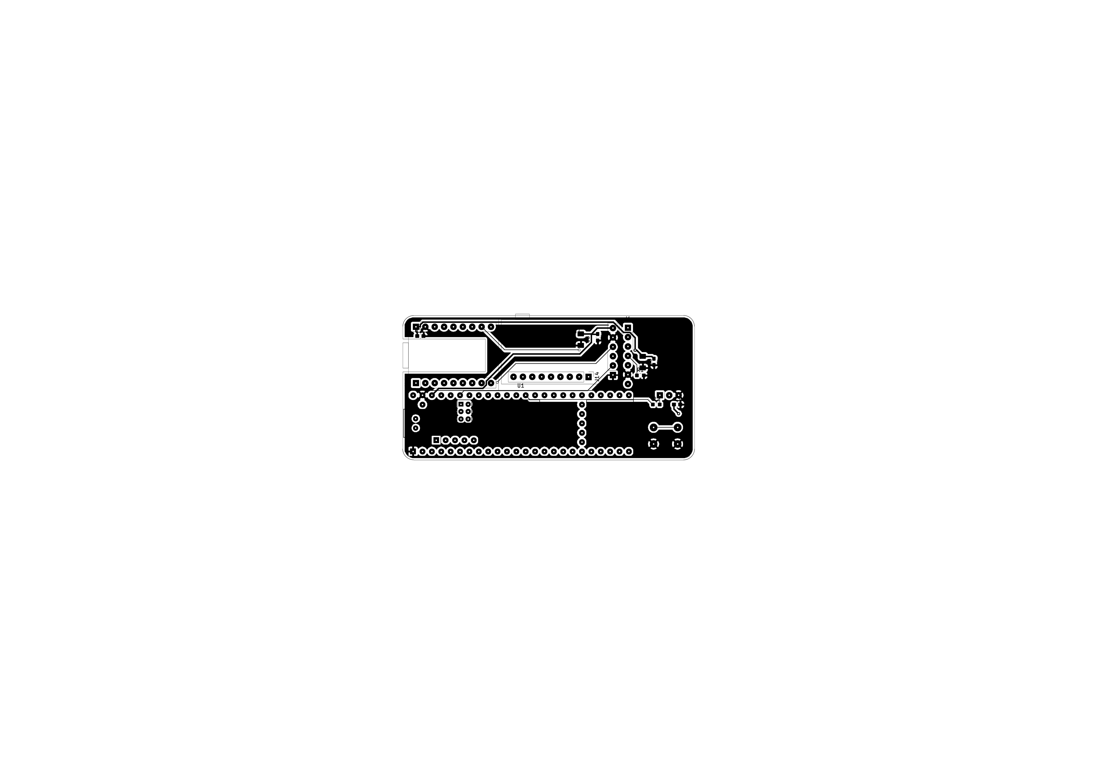
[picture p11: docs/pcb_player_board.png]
Player board
|  |  |
| [PDF](docs/pcb_player_schematic.pdf) | [PDF](docs/pcb_player_board.pdf) |

**Hand unit PCB** — ESP32-S3 SuperMini, PN532, VL53L0X, motor driver, LED strip and battery.

| Schematic | Board layout |
|---|---|
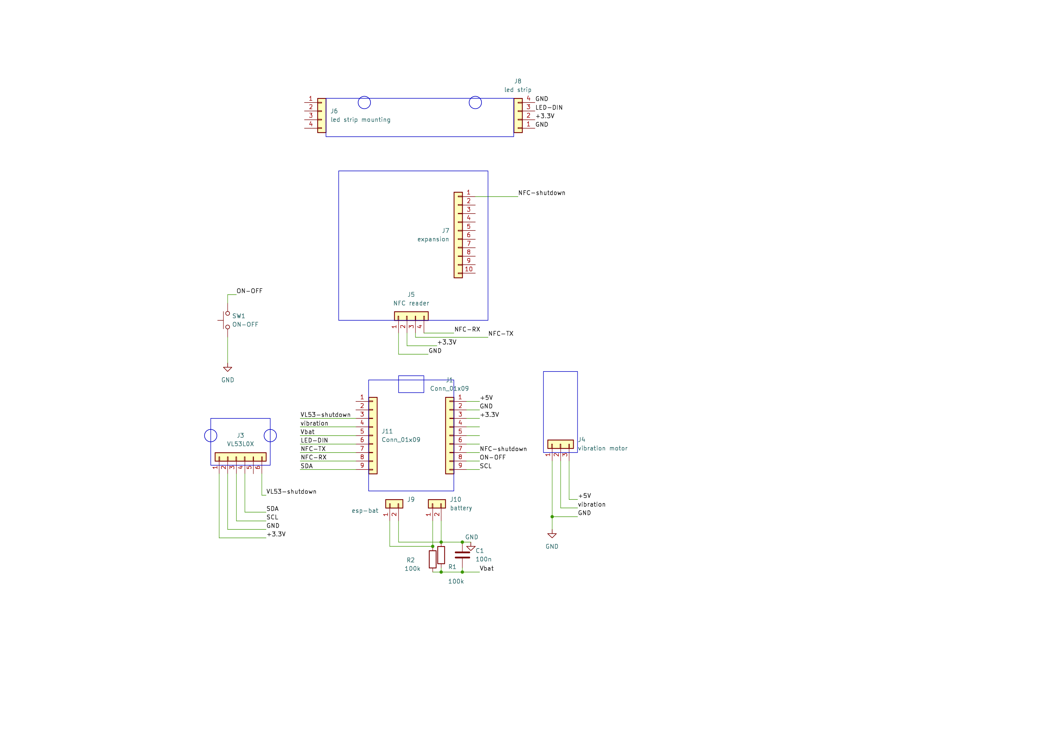
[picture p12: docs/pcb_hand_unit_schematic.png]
Hand unit schematic
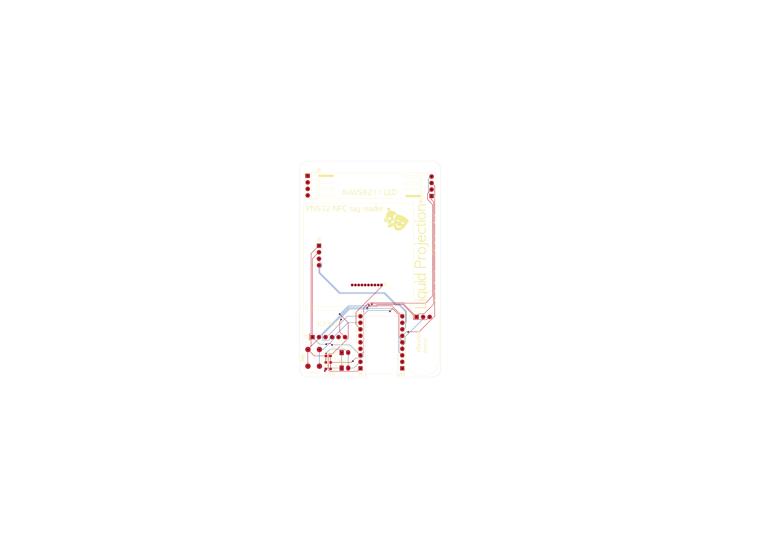
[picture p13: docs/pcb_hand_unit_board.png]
Hand unit board
|  |  |
| [PDF](docs/pcb_hand_unit_schematic.pdf) | [PDF](docs/pcb_hand_unit_board.pdf) |

---

## 12. Setting up the development environment

### 12.1 Install

1. **VS Code** — <https://code.visualstudio.com>.
2. In VS Code, install the **PlatformIO IDE** extension (it installs its own Python and the `pio`
   command). Restart VS Code when asked.
3. **Python 3** and **ffmpeg** for the tools: `brew install python ffmpeg` on macOS. The Python tools were
   tested with Python 3.9 (the version macOS ships), 3.11 and 3.12; check yours with `python3 --version`.
4. For the documentation figures only: `pip install cairosvg pillow`.
5. Clone the repository and open each device's folder in VS Code (below).

The repository holds **three PlatformIO projects**; open each as its own workspace (or add them
as a multi-root workspace):

| Folder | Device | Environment |
|---|---|---|
| repository root (`platformio.ini`) | Teensy player | `teensy41` |
| `ESP32handUnit/` | hand unit | `hand_unit` |
| `ESP32bodyBridge/` | body bridge | `body_bridge` |

PlatformIO downloads the platforms and libraries on the first build.

### 12.2 Serial ports

On macOS the boards appear as `/dev/cu.usbmodem…`. List them with `pio device list`. With several
boards connected, select the port explicitly (`--port` for the monitor, `--upload-port` for uploads).
The Teensy's port changes when its USB type changes (it is *Serial + MTP* here).

### 12.3 Library and platform pins

These versions were tested together. **Do not float them** — the toolchain moved underneath this
project several times (details in [Context.md](Context.md)).

| Project | Pin | Why |
|---|---|---|
| ESP32 (both) | `platform = platformio/espressif32@6.13.0` | the official platform; Arduino core 2.0.17. Core 3.x changes the ESP-NOW callback signatures and the LEDC (PWM) API; the community **pioarduino** platform was abandoned (its bundled esptool 5.4.0 crashed on upload) |
| ESP32 (both) | `board = esp32-s3-devkitc-1`, flags `-DARDUINO_USB_CDC_ON_BOOT=1 -DCORE_DEBUG_LEVEL=0` | the SuperMini's USB serial; quiet logs |
| ESP32 hand unit | `fastled/FastLED @ ^3.6.0`, `pololu/VL53L0X @ ^1.3.1`, Seeed `PN532` (git) | |
| Teensy | `platform = teensy`, `board = teensy41` (core Teensyduino 1.60) | the core already contains MTP |
| Teensy | `-DAUDIO_BLOCK_SAMPLES=128`, `-DUSB_MTPDISK_SERIAL` | the Audio Library's fixed block size; USB serial **plus** MTP |
| Teensy | `fastled/FastLED @ 3.10.1` | 3.10.2 / 3.10.3 compile an SD-card file that breaks the MTP headers on case-insensitive filesystems |
| Teensy | `bblanchon/ArduinoJson @ ^7.0.0` | config and bridge parsing |
| Teensy | do **not** add the `MTP_Teensy` library | Teensyduino 1.60 bundles it; adding it redefines the same classes |

To confirm an ESP32 build uses the right platform, look for these lines in the build output:

```
PLATFORM: Espressif 32 (6.13.0) > Espressif ESP32-S3-DevKitC-1-N8 …
 - framework-arduinoespressif32 @ 3.20017.241212+sha.dcc1105b      (= Arduino core 2.0.17)
```

---

## 13. Building and flashing

```bash
# Teensy player (repository root)
pio run                       # build
pio run -t upload             # build + flash (the Teensy Loader opens)
pio device monitor -b 115200

# Hand unit / body bridge
cd ESP32handUnit   && pio run -t upload && pio device monitor -b 115200
cd ESP32bodyBridge && pio run -t upload && pio device monitor -b 115200

pio run -t clean              # clean build
```

* **Teensy:** if the Teensy Loader waits for the board, press the small program button on the Teensy.
* **ESP32-S3 SuperMini:** if an upload cannot find the board, put it in download mode — **hold BOOT,
  tap RESET, release BOOT** — and upload again. A new board usually needs this for its first flash.
* **Wrong LED colours** on a board: it is probably a v0.0.2 variant; add
  `-DSTATUS_LED_ORDER=RGB` to that project's `build_flags`, or use a standard board.
* The hand unit's configuration constants (pins, timings, thresholds, `POWER_MANAGEMENT`,
  `NFC_UART`) are in `ESP32handUnit/src/Config.h`; the body bridge's in `ESP32bodyBridge/src/Config.h`.
  The Teensy's tunables (`HAPTIC_DRIVE_DEFAULT`, `DUCK_ATTACK_MS`, …) are `#define`s at the top of
  `src/main.cpp`.

---

## 14. Project structure

```
.
├── README.md  Context.md
├── platformio.ini                  Teensy project
├── src/                            Teensy firmware
│   ├── main.cpp                    setup / loop / state machine / CLI
│   ├── AudioPlaySdWavMulti.h       custom 8-channel WAV player with deferred seek
│   ├── EspBridge.h                 UART JSON line reader (body bridge link)
│   ├── ConfigLoader.h              config.json → typed structs (multi-UID tags, show settings)
│   ├── LedAnimator.h               non-blocking ring animations
│   ├── RamPlayer.h                 short effects held in RAM
│   └── UsbMaintenance.h            USB MTP maintenance mode
├── ESP32handUnit/                  hand-unit firmware (own platformio.ini)
│   └── src/
│       ├── main.cpp                setup() + loop()
│       ├── Config.h                pins and parameters
│       ├── Motor.h                 esp_timer-driven bursts + proximity vibration
│       ├── Proximity.h             VL53L0X, non-blocking, `tof` diagnostics
│       ├── TouchManager.h          connection state machine (IDLE / RELEASED)
│       ├── LedRing.h               ring animations
│       ├── NfcTask.h               PN532 over UART: a FreeRTOS task on core 0 + a queue
│       ├── EspNow.h                ESP-NOW pairing and send functions
│       ├── Statusled.h             GPIO 48 status indicator
│       ├── PowerManager.h          deep sleep, button, battery
│       └── Cli.h                   serial command handler
├── ESP32bodyBridge/                body-bridge firmware (own platformio.ini)
│   └── src/  main.cpp Config.h EspNow.h PairButton.h Statusled.h Cli.h
├── configs/
│   ├── tag_catalogue.json          every physical tag, by role
│   ├── generate_player_configs.py  catalogue + chapter timeline → playerN config.json
│   └── …                           (generated output goes to output/)
├── experience/
│   ├── assemble_71.sh              stems → 8-channel experience.wav
│   └── Visualise.py                config → experience map (HTML / SVG / PNG)
├── tools/
│   ├── editor.py                   web config editor
│   ├── led_editor.py               LED animation editor
│   └── make_docs.py                regenerates the figures in docs/
├── led_animations.json             example custom animation
└── docs/                           figures (SVG + PNG), PCB schematics and boards
```

---

## 15. How it works

### 15.1 The audio engine

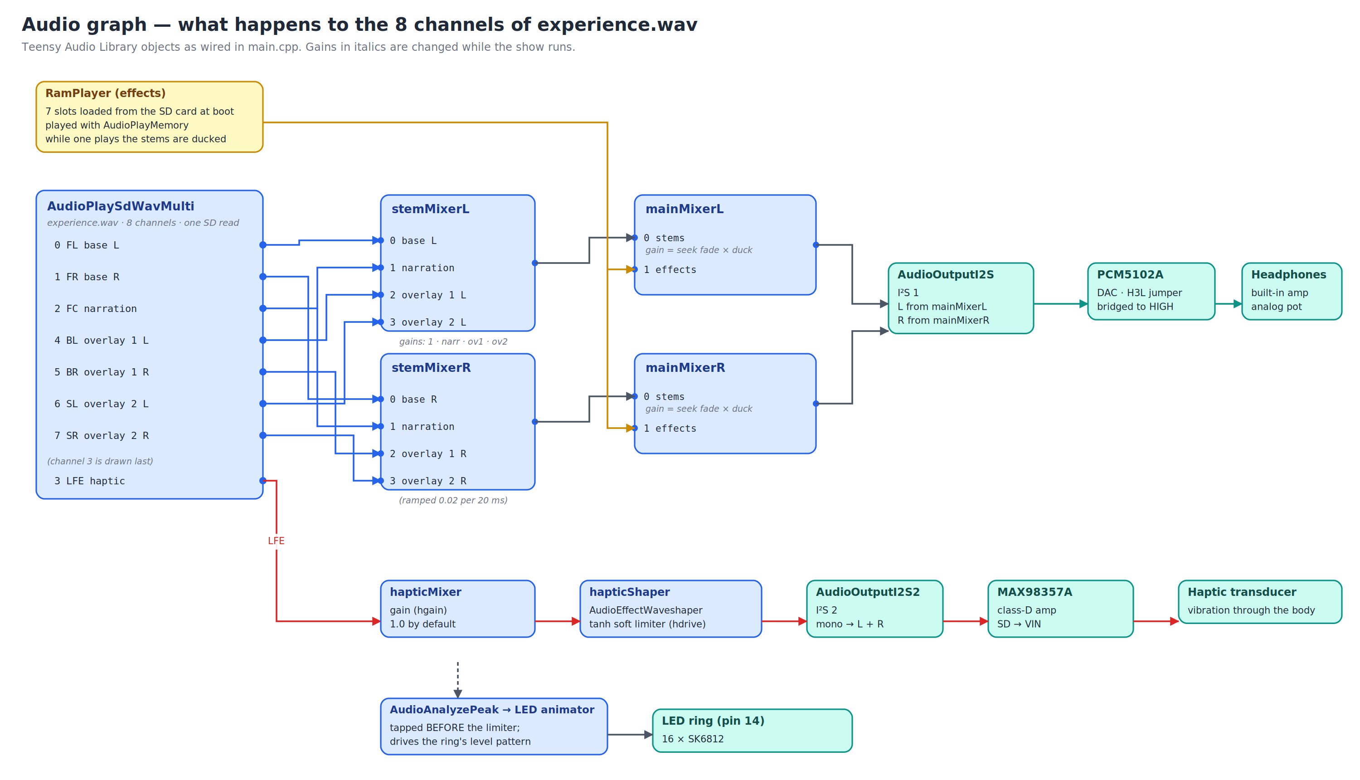
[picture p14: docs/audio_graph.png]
Audio graph


* **One file, one SD read.** Reading several WAV files at once made the SD bus serialise and the CPU
  spike; a single 8-channel interleaved file costs about 4 % CPU. The custom player
  (`AudioPlaySdWavMulti`) also does its seeks **inside the audio interrupt** (a pending-seek flag),
  because a seek from `loop()` raced with the interrupt and silently stopped the player.
* **Chapter changes** crossfade: the stems fade out (0.05 per 20 ms ≈ 0.4 s), the player seeks, they fade
  back in. Overlays and narration fade at 0.02 per 20 ms (≈ 1 s).
* **Ducking.** While a RAM effect plays, `mainMixer` channel 0 is multiplied by a ducking envelope —
  down in 40 ms, back up in 400 ms — on top of the seek fade.
* **Haptics.** The LFE channel goes through a **soft limiter** (a `tanh` waveshaper; `hdrive` sets its
  strength) into the MAX98357A. The LED ring's `level` pattern is tapped *before* the limiter.
* **Headphones.** Mixer output goes straight to the PCM5102A; there is no master gain stage (the
  headphones have their own amplifier).

### 15.2 The show logic

The experience map

A tag arrives from the body bridge as a *confirmed connection* (`"t":"c"`). `main.cpp` looks the UID up
(`ConfigLoader::findTagIndex`, which searches every spare), checks the per-tag cooldown, and then:

1. **Show over?** Only a `start` tag is accepted.
2. **Person tag?** Refused while the show is ending, or when the lock is on and the current chapter is
   not the base chapter (→ *denied* sound). Otherwise accepted (→ *connect* sound after its actions).
3. Runs the tag's **actions** (chapter jump with crossfade, overlay change, effect, LED event).
4. A `start` tag also **starts the show clock** (`beginShow()`).

The loop checks the clock every pass: when `end_after_min` has elapsed it sets the *ending* flag; a
looping chapter is released (switched to play-once so it stops at its loop end). When a chapter that plays
once ends: the end chapter → `endShow()` (player stopped, ring `off`); otherwise, during the ending →
the end chapter; otherwise `returns_to` (with the *ready* sound when it is `base`); otherwise idle.

### 15.3 The wireless link and the protocols

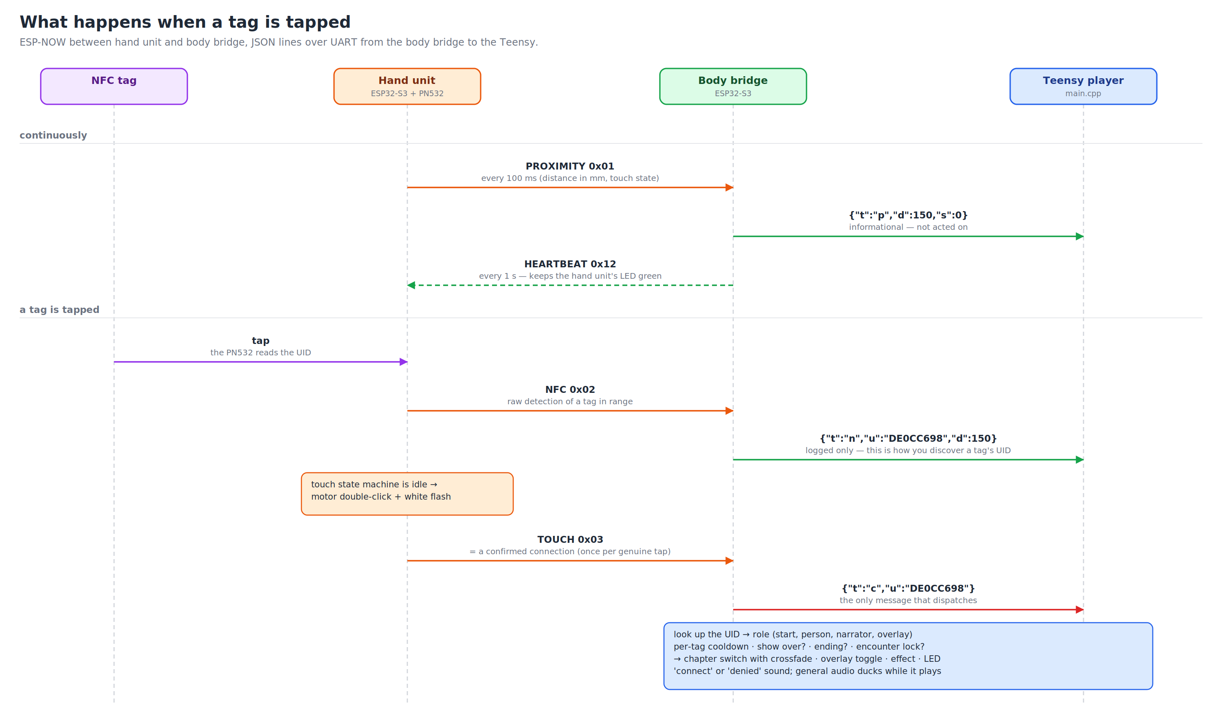
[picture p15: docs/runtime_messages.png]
What happens when a tag is tapped


**ESP-NOW** (hand unit ⇄ body bridge, 2.4 GHz, unicast between the paired units):

| Type | Code | Direction | Meaning |
|---|---|---|---|
| `MSG_PROXIMITY` | `0x01` | hand → body | distance + touch state, every 100 ms |
| `MSG_NFC` | `0x02` | hand → body | raw tag detection |
| `MSG_TOUCH` | `0x03` | hand → body | confirmed connection |
| `MSG_PING` / `MSG_PONG` | `0x10` / `0x11` | hand ↔ body | `espnow scan` pairing |
| `MSG_HEARTBEAT` | `0x12` | body → hand | every 1 s |
| `MSG_PAIR_REQUEST` | `0x20` | body → all (broadcast) | button pairing mode |
| `MSG_PAIR_ACK` | `0x21` | hand → body | the hand unit's tap |

The body bridge accepts data **only from the paired hand**; everything else is counted as "foreign" and
ignored. A link is considered up while packets keep arriving (2 s on the body, 3.5 s on the hand).

**Packets.** All ESP-NOW payloads are packed structs:

| Struct | Layout | Used by |
|---|---|---|
| `HandPacket` | `type` (1 byte) · `distMm` (2 bytes) · `touchState` (1 byte) · `nfcUid` (20-byte text) = 24 bytes | `MSG_PROXIMITY` (distance, touch state) · `MSG_NFC` (+ UID) · `MSG_TOUCH` (touch state 1 + UID) |
| `PingPacket` | `type` (1 byte) · `deviceId` (16-byte text) = 17 bytes | `MSG_PING` / `MSG_PONG` |
| heartbeat | `type` only (1 byte) | `MSG_HEARTBEAT` |

The pairing is stored in flash by each unit: the hand unit under the preferences namespace `handunit`, the body bridge under
`bodybridge`, key `handMac` (6 bytes).

**Body bridge → Teensy**, newline-terminated JSON at 115200 baud:

```json
{"t":"p","d":150,"s":0}                  proximity (informational)
{"t":"n","u":"DE0CC698","d":150}         raw NFC detection (logged; shows the UID)
{"t":"c","u":"DE0CC698"}                 confirmed connection — the only one that dispatches
```

The hand unit's own touch state machine debounces and enforces a silence period after a connection, so
`c` fires once per genuine tap; the per-tag cooldown on the Teensy is a second safety net.

### 15.4 Pairing

See the figure in [section 6](#6-pairing-hand-units-and-body-bridges). Both methods store the partner's MAC
in flash (`Preferences`). Pairing by `espnow scan` is by broadcast; by buttons it is by an explicit
request/acknowledge.

### 15.5 Startup sequences

**Teensy player**

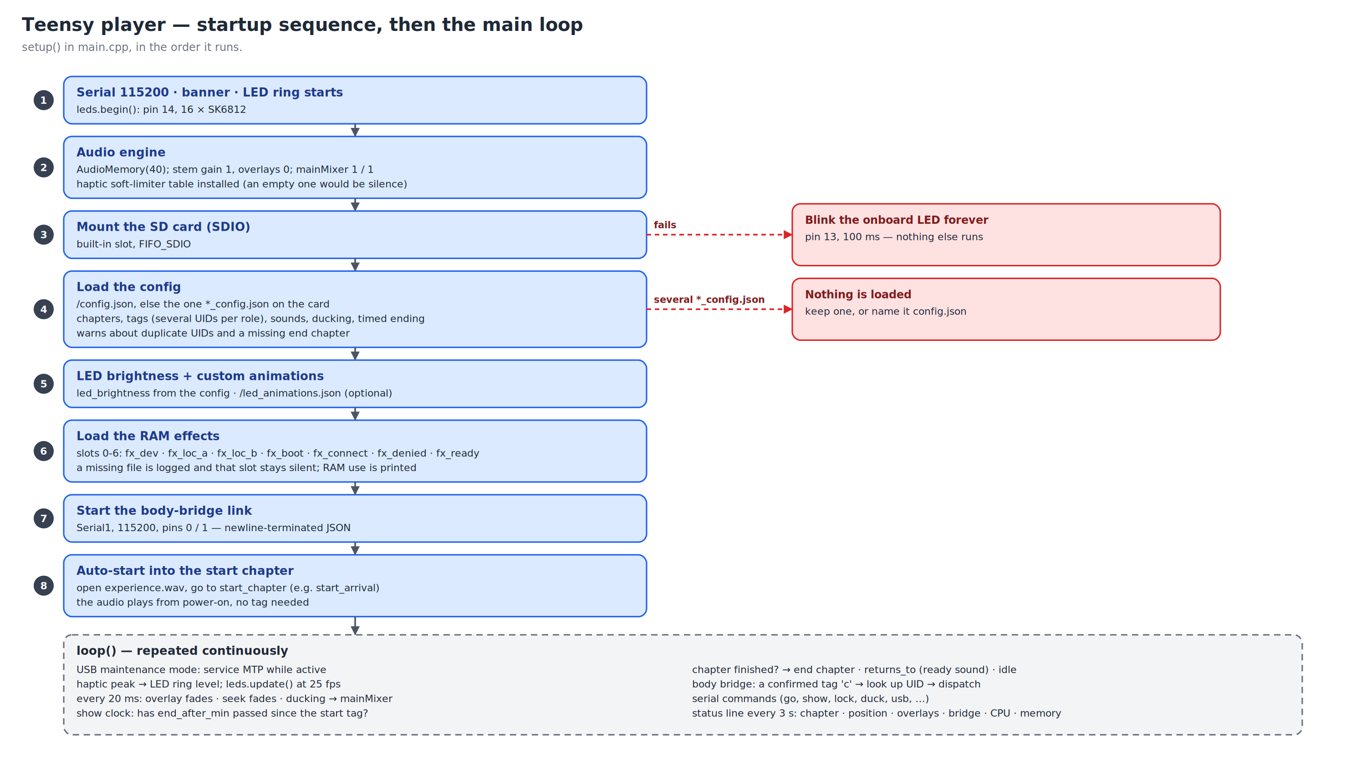
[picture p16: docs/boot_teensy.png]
Teensy startup


**Hand unit**

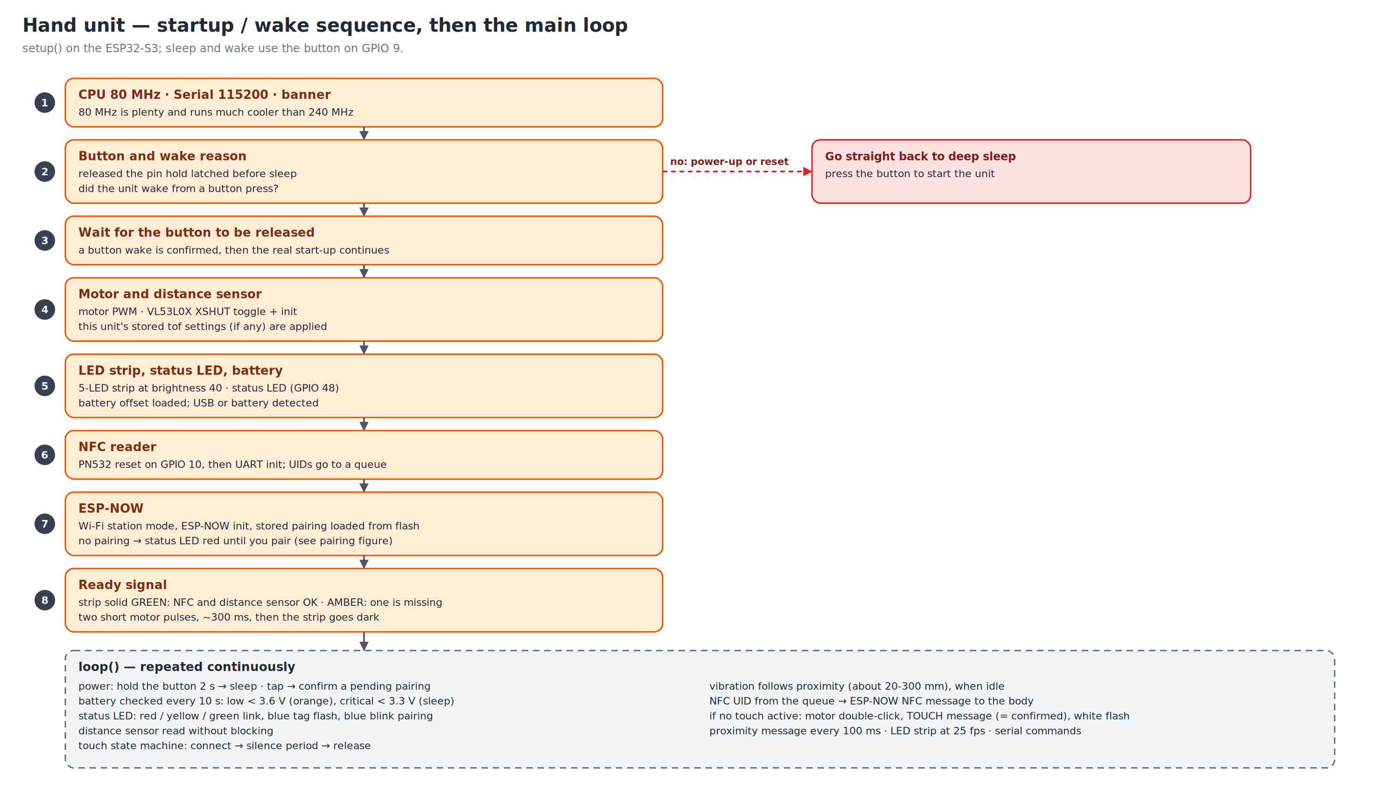
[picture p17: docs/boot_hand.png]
Hand unit startup


**Body bridge**

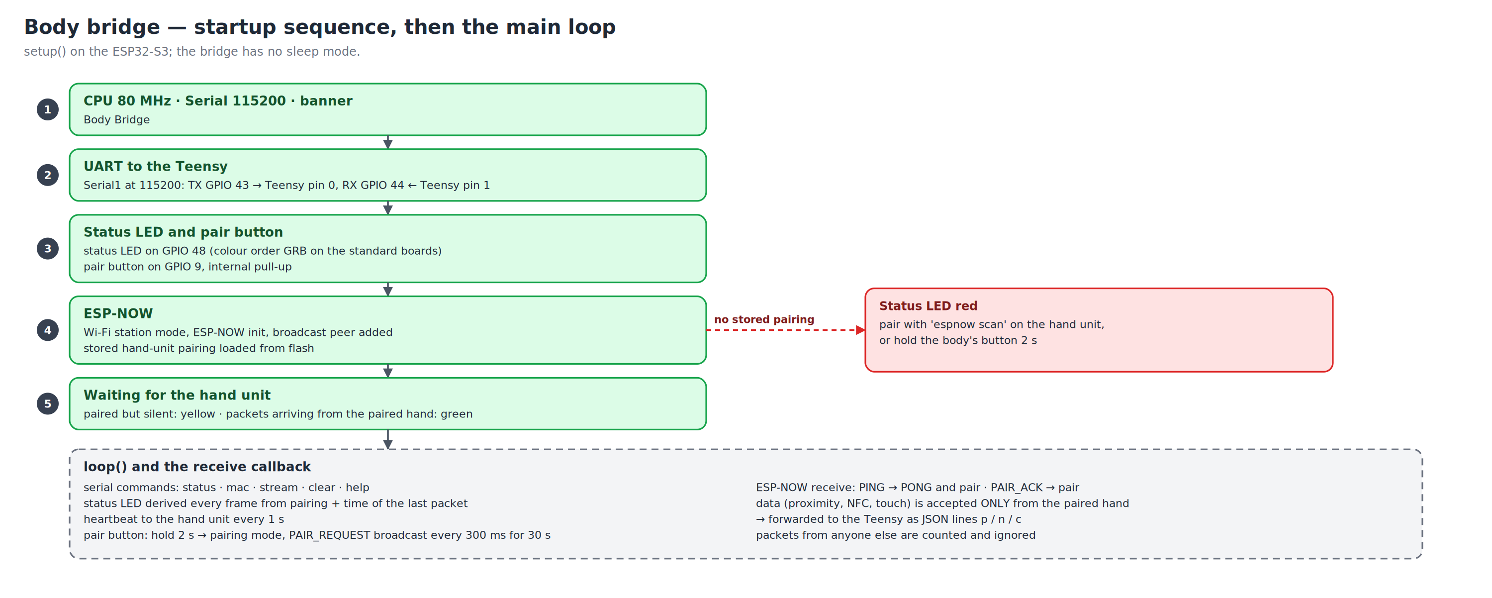
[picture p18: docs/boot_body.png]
Body bridge startup


### 15.6 Power management (hand unit)

The unit runs at 80 MHz (240 MHz ran hot). A reset or power-up goes to deep sleep; the button (GPIO 9) wakes
it. Before sleeping the motor, LEDs and radio are stopped, and the PN532 reset and button lines are held so
they do not float. In sleep the PN532 is held in reset (GPIO 10 low, latched) and the VL53L0X in hardware standby (XSHUT low, latched). The original
design notes estimate the sleep current at about 20 µA (ESP32) + 5 µA (PN532) + 5 µA (VL53L0X); those are estimates from the
development notes, not measurements made for this documentation, and the onboard WS2812 and the battery divider add their own drain.
`NFC_SLEEP_MS = 0` keeps the PN532 always on: letting it power down between polls would save about 75 mA but needs a wake-up preamble
after every sleep, so it is deferred. The battery monitor is explained in [section 9.2](#92-hand-unit-serial-monitor-115200-baud).

### 15.7 The distance sensor

The VL53L0X is read without blocking. A reading counts when it lies between `tof min` (default 50 mm — below
that is crosstalk) and `tof max` (2000 mm) and the sensor accepted it. Vibration follows proximity between
about 20 and 300 mm. `tof raw` shows, per measurement, the device status code, the return signal rate, the
ambient rate and the SPAD count, which is how a weak unit is diagnosed.

### 15.8 Hand unit: touch, vibration and light

| Situation | LED strip | Vibration |
|---|---|---|
| Start-up | solid **green** (NFC and distance sensor found) or **amber** (one missing), for 300 ms | two pulses (duty 160, 60 ms on / 40 ms off) |
| Idle, nothing nearby | **teal**, a travelling sine wave, one full cycle spread over the strip; a cycle takes 3.84 s (an integer `sin8` lookup — see Context.md for why) | off |
| A hand approaches (valid reading between `PROX_NEAR_MM` 20 and `PROX_FAR_MM` 300 mm) | colour shifts from teal (0, 140, 200) towards warm red (220, 40, 0) with proximity | ramps up **quadratically**: `t² × MOTOR_MAX`, where *t* is 1 at 20 mm and 0 at 300 mm (`MOTOR_MAX` 200 of 255) |
| A tag is read while no touch is active | **white flash**, 80 ms (the loop pauses for those 80 ms) | **double click**: 2 pulses, duty 230, 40 ms on / 30 ms off |
| Silence period after a connection (`SILENCE_MS`, 3 s) | stays teal, no colour shift | off, whatever the distance; further tags are ignored (`[Touch] Ignored — still in silence`) |
| Release | back to idle only when **both** the silence has elapsed **and** the sensor no longer sees a valid distance (`[Touch] Ready — new connection possible`) | — |

### 15.9 Hand unit: tasks and cores

* **Core 0:** `nfcTask`, a FreeRTOS task (stack 4096, priority 1). It polls the PN532 over UART with a 50 ms timeout and posts UIDs to a queue.
* **Core 1:** the Arduino `loop()` — distance sensor, LED ring, motor, ESP-NOW, serial commands and the touch state machine.
* **`esp_timer`:** times the motor bursts independently of both cores, so a burst is precise even while an NFC poll blocks.
* **One I²C bus** (`Wire`, GPIO 7/8) carries the VL53L0X only; the PN532 is on UART1 (GPIO 5 RX, 6 TX), which avoids I²C conflicts.
* All modules are header-only files included from `main.cpp`.

### 15.10 Hand unit: tunables

In `ESP32handUnit/src/Config.h` unless noted. Change them in the source and reflash.

| Define | Default | Meaning |
|---|---|---|
| `POWER_MANAGEMENT` | `1` | `0` = always on (debugging), `1` = full sleep / wake |
| `NFC_SLEEP_MS` | `0` | PN532 power-down between polls: `0` = always on, `200` ≈ 8 mA average (deferred, see 15.6) |
| `SILENCE_MS` (`TouchManager.h`) | `3000` | motor silence and blocked new connections after a connection |
| `PROX_FAR_MM` / `PROX_NEAR_MM` | `300` / `20` | vibration starts at the far value and reaches its maximum at the near value |
| `MOTOR_FREQ` / `MOTOR_MAX` | `20000` / `200` | PWM frequency (20 kHz is inaudible) / maximum duty, 0–255 |
| `LED_COUNT` | `5` | LEDs on the hand unit's strip — must equal the real count (the source default was `16`, for the old ring) |
| `USE_LONG_PRESS` | `1` | `1` = hold the button `POWER_HOLD_MS` (2000) to sleep, `0` = two taps within `DOUBLE_PRESS_MS` (500) |
| `VBAT_LOW_MV` / `VBAT_CRIT_MV` | `3600` / `3300` | low-battery pulse / automatic sleep, on the **corrected** cell voltage |
| `VBAT_OFFSET_MV` / `VBAT_USB_MV` (`PowerManager.h`) | `320` / `4300` | diode correction added to the rail reading / above this the rail is USB |

---

## 16. Tools reference

| Tool | Run | Purpose |
|---|---|---|
| `experience/assemble_71.sh` | `./assemble_71.sh base.wav narr.wav ov1.wav ov2.wav haptic.wav experience.wav` | stems → 8-channel WAV (with channel checks) |
| `configs/generate_player_configs.py` | `python3 configs/generate_player_configs.py [--lock] [--end-after MIN] [--duck L]` | the seven player configs |
| `experience/Visualise.py` | `python3 experience/Visualise.py cfg.json out.html [--svg f.svg] [--png f.png]` | draw a configuration |
| `tools/editor.py` | `python3 tools/editor.py path/to/config.json` | web editor on http://localhost:8080 |
| `tools/led_editor.py` | `python3 tools/led_editor.py /Volumes/PLAYER3/` | LED animation editor |
| `tools/make_docs.py` | `python3 tools/make_docs.py` | the figures and placeholders in `docs/` |

---

## 17. Regenerating the figures

```bash
pip install cairosvg pillow
python3 tools/make_docs.py                 # everything
python3 tools/make_docs.py audio_graph     # only figures whose name contains this
```

The script writes each figure as `docs/<name>.svg` and `.png`. The experience map is produced by
`experience/Visualise.py` from an example card built with `configs/generate_player_configs.py`, so it follows
the current config schema. The PCB placeholders are created only if the files do not exist — real exports
under the same names are never overwritten. If you change the firmware or the protocol, update the matching
function in `make_docs.py` (they are plain Python drawing code, one function per figure).

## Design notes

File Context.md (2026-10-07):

# Engineering Context & Lessons Learned

What didn't work, why, and what was chosen instead — plus how the system got to its current
shape, what has been verified on hardware, and what is still open. Useful for future
development, porting and debugging. The user-facing manual is [README.md](README.md).

Legend: ❌ tried and abandoned · ✅ works and is kept · ⚠️ open / unresolved · 📜 historical (superseded)

## Contents

1. [Where the design stands](#1-where-the-design-stands)
2. [Audio](#2-audio)
3. [SD card, files and USB maintenance mode](#3-sd-card-files-and-usb-maintenance-mode)
4. [Configuration and show logic](#4-configuration-and-show-logic)
5. [LED](#5-led)
6. [ESP32 firmware and toolchain](#6-esp32-firmware-and-toolchain)
7. [How changes were verified](#7-how-changes-were-verified)
8. [Platform considerations](#8-platform-considerations)
9. [Open issues and next steps](#9-open-issues-and-next-steps)
10. [Housekeeping](#10-housekeeping)

---

## 1. Where the design stands

* **Player:** Teensy 4.1. Headphone audio from a PCM5102A on I²S 1, haptics from a MAX98357A on I²S 2.
  One 8-channel WAV on the built-in SD slot; short effects in RAM; one LED ring that follows the haptic
  signal. USB gives a serial console and an MTP maintenance mode.
* **Wearer:** an ESP32-S3 hand unit (PN532 NFC, VL53L0X distance, vibration motor, a 5-LED strip, LiPo).
* **Link:** hand unit ⇄ body bridge (ESP32-S3) over ESP-NOW; body bridge → Teensy over UART as JSON lines.
* **Experience:** ten 45-second chapters; tags have roles (start, person, narrator, overlay) with spares;
  a timed ending wraps the show up and switches the player off.
* **Content pipeline:** stems → `assemble_71.sh` → `experience.wav`; tag UIDs → `tag_catalogue.json` →
  `generate_player_configs.py` → seven `config.json`.

The figures in `docs/` (system overview, audio graph, show flow, startup sequences, …) are the quickest
way into the structure; see the README.

---

## 2. Audio

### ✅ One interleaved 7.1 file instead of several players

**Tried:** three `AudioPlaySdWav` objects at once (base + 2 overlays), one WAV each.

**Happened:** CPU rose from ~1 % to ~30 % per extra player (37 % with two overlays). `AudioProcessorUsage()`
counts time inside the audio interrupt *including SD wait states*; with concurrent readers the SDIO bus
serialises the reads and the wait shows up as CPU. Enough players caused glitches and crashes.

**Root cause:** at the time (Teensyduino 1.60) the Teensy 4.1 SDIO driver does not do concurrent reads
efficiently — each `AudioPlaySdWav::update()` blocks until its read completes.

**Solution:** a single 7.1 interleaved WAV read by `AudioPlaySdWavMulti`: one SD read per interrupt feeds
all eight channels. CPU is ~4 %.

### ✅ Keep `AUDIO_BLOCK_SAMPLES = 128`

Doubling it to 256 (to halve SD read frequency) made the audio severely degraded — bit-crushed, almost
unrecognisable. The I²S driver and the audio library are calibrated for 128-sample blocks. Treat it as fixed.

### ✅ Seeks happen inside the audio interrupt

**Tried:** calling `multiPlayer.seekMs()` from `loop()` in the seek crossfade state machine.

**Happened:** after several tag interactions the player silently stopped (`pos:0`, `CPU:0.0%`, `mem:0`);
effects from RAM still worked.

**Root cause:** a race. `seekMs()` called `_file.seek()` from `loop()` while `update()` in the interrupt also
used `_file`.

**Solution:** *deferred seek*. `seekMs()` only sets `_seekPending` / `_seekTargetMs` (`volatile`); the real
`_file.seek()` happens in `update()`, single-threaded. A second bug in the same area: when a once-chapter
ended naturally (`_playing = false`) a later seek request was dropped because `update()` returned before
checking the flag. The pending seek is now processed first, and a seek sets `_playing = true`.

### ✅ Edge-detect `isPlaying()` (no restart loop)

`isPlaying()` is false for a few milliseconds after a file ends while the last buffer drains. A naive
`if (!player.isPlaying()) player.play(FILE)` in `loop()` called `play()` thousands of times, corrupting state
and opening the file repeatedly (a loud click on every loop restart). Track the previous state and act on the
falling edge only.

### ✅ `AudioPlayMemory` header format

Effects played as a ~1 ms click regardless of length when the header carried a block count. `update()`
decrements `length` by `AUDIO_BLOCK_SAMPLES` per tick and stops below 128, so `length` is in **samples**.
Header: `(0x81 << 24) | (numSamples & 0x00FFFFFF)`; bits 31–24 = type (0x81 = 16-bit PCM 44.1 kHz), two
`uint16_t` words in little-endian order.

**Consequence for effect files:** `RamPlayer` always writes type 0x81 (mono, 44.1 kHz) and does not resample.
A stereo file plays at half pitch and double length; a 48 kHz file plays slowly. Effects must be 16-bit mono
44.1 kHz, and are clamped to 180 000 bytes (~2 s).

### 📜 Haptic output through PWM, DAC and MQS

The first haptic output was a PWM hack; it is **replaced by a MAX98357A on I²S 2**. Kept as history:

* `AudioOutputAnalog` — the Teensy 4.1 has **no DAC**; on 4.x that class is PWM. `AudioOutputPWM` is the right class.
* `AudioOutputPWM` on pins 3 + 4 with a 1 kΩ + 270 kΩ resistor network and an RC filter: only the LSB pin
  reliably fired its DMA; pin 3 did not. The library had to be patched to `begin(2, 4)` (and `begin()` is
  private). Output sounded bit-crushed — fine for a haptic transducer, not for audio.
* `AudioOutputMQS` — fixed pins 10 and 12 collide with the SPI pins the (since removed) Audio Shield used.
* PWM output was also sensitive to `FastLED.show()` timing — see [LED](#5-led).

### ✅ Dual I²S: PCM5102A (headphones) + MAX98357A (haptics)

The Audio Shield (SGTL5000) was replaced by two small modules; no codec object or I²C is needed.

* **PCM5102A** — I²S 1: MCLK 23, BCLK 21, LRCLK 20, DIN 7; SCK grounded. The module's four solder jumpers
  matter: the factory default bridges `H3L` (XSMT, soft-mute) to **LOW = muted**. Bridge it to **HIGH**.
  `H4L` (FMT) must stay LOW (I²S). `H1L` (FLT) and `H2L` (DEMP) to L. The symptom of a wrong `H3L` is *no
  sound at all* with a perfectly healthy software chain.
* **MAX98357A** — I²S 2 (`AudioOutputI2S2`): LRC 3, BCLK 4, DIN 2. Tie **SD to VIN**; the pin has an
  internal pull-down, so a floating SD means shutdown. GAIN floating = 9 dB. The mono haptic signal is
  duplicated to both channels.

### ✅ Haptic soft limiter (waveshaper)

The haptic output felt softer after the move from the PWM path + amp. Instead of raising the mixer gain
(which hard-clips at 16 bit) a soft limiter sits between `hapticMixer` and the I²S 2 output.

* `AudioEffectWaveshaper` with the curve `y = tanh(k·x) / tanh(k)`: full scale in is full scale out, quiet
  parts get louder (small-signal gain `k / tanh(k)`; k = 2.5 gives +8.1 dB), peaks round off.
  `hdrive 0` is a straight line (bypass). Default `HAPTIC_DRIVE_DEFAULT = 0.5` — the value that was chosen
  by ear on the hardware.
* **An `AudioEffectWaveshaper` with no table outputs silence.** `setup()` must install a table before audio
  is expected.
* **`shape()` frees and reallocates the table the audio interrupt reads**, so a change at runtime has to be
  wrapped in `AudioNoInterrupts()` / `AudioInterrupts()`.
* The library requires a table length of 2ⁿ + 1; 1025 points are used.
* The LED ring's `level` pattern is tapped from the mixer **before** the limiter, so changing `hdrive`
  does not change the light.

### ✅ Ducking: effects over the general audio

Effects played from RAM were hard to hear over the stems. While an effect plays, the stems are lowered.

* The ducking envelope multiplies **`mainMixer` channel 0** (stems), next to the seek fade:
  `gain = stemGain × duck`, written every 20 ms tick. (Previously channel 0 was written only during fades.)
  It is a separate factor so the seek crossfade is undisturbed.
* Attack 40 ms, release 400 ms (`DUCK_ATTACK_MS`, `DUCK_RELEASE_MS`); detection is `ramFx.isPlaying()`, so
  every effect — feedback sounds, chapter-entry and tag-triggered ones — ducks automatically.
* `duck_level` (config) or `duck <0-1>` (CLI). `1` = off, which is exactly the old behaviour.
* The haptic path is not ducked.

### ❌ A headphone gain stage (tried, reverted)

**Asked:** more headphone volume. **Built:** a second soft limiter pair after `mainMixer` with a tunable gain
(`hp <gain>`), plus a peak monitor. It was placed *after* the mixer because the seek fades overwrite
`mainMixer`'s own gain on every chapter change, so a master volume there would be lost.

**Measured** (1 kHz sine through the real transfer curve): at +3.5 dB the output stays clean (0.01 % THD) up
to a peak of −5.5 dBFS, then rises (≈ 7 % at −2 dBFS, ≈ 15 % at 0 dBFS); at +6 dB it is clean up to −8 dBFS.

**Outcome:** reverted — the headphones turned out to have a built-in amplifier. If more level is ever needed,
the cleaner route is a hotter, properly limited master of the stems; a static soft limiter cannot do what a
look-ahead limiter does.

---

## 3. SD card, files and USB maintenance mode

### ✅ macOS hidden files on FAT32

Finder writes `._filename` next to every copied file, plus `.DS_Store`, `.Spotlight-V100`, `.fseventsd`.
They fill the FAT directory table, slow lookups and can confuse the SD library. Always run
`dot_clean /Volumes/CARD/` after copying (or copy with `cp`). The config loader also ignores any name that
starts with a dot, so a `._player2_config.json` is never mistaken for a config.

### ✅ Slow SD cards

A generic Class-4 card gave irregular vinyl-like clicks even with one player. Class 4 (4 MB/s minimum) is not
enough for real-time streaming plus directory lookups. Use SanDisk Ultra or Extreme (A1/A2, UHS-I) — random-read
IOPS matter, not only sequential speed.

### ✅ WAVE_FORMAT_EXTENSIBLE (65534) must be accepted

ffmpeg writes multi-channel WAVs with format tag 65534, not 1. The parser accepts both (the samples are
16-bit signed PCM either way).

### ✅ `amerge`, not `join`

`join` is meant for upmixing and may mix inputs (haptic content bled into the overlays). `amerge=inputs=N`
interleaves strictly in the order given.

### ✅ `assemble_71.sh` is defensive

Two stereo files where mono was expected used to produce a **10-channel** file that still reported "Done".
The script now probes each stem, converts mono ↔ stereo where that is safe, refuses more than 2 channels,
verifies the result is 8 channels at 44.1 kHz and deletes it otherwise, and never touches an existing output
if it fails before writing. Two details worth knowing:

* **`amerge` cuts the output to the shortest input.** A 452 s stem next to 450 s stems silently loses 2 s.
  The script now warns when lengths differ by more than 0.1 s.
* It runs under macOS's default **bash 3.2**: no `${var,,}`, associative arrays or `mapfile`.

### ✅ The config file can be named `*_config.json`

The loader opens `/config.json`; if that does not exist it uses the single `*_config.json` in the card root
(case-insensitive; folders and dot-files ignored). Several candidates → it refuses to guess. This lets a
card be labelled `player3_config.json`.

### ✅ USB maintenance mode (MTP)

The SD card is hard to remove from the Teensy. The `usb` command stops playback (closing `experience.wav` — the
only file the player keeps open), starts MTP and shares the card; `reboot` leaves the mode and reloads the config.

* USB type `USB_MTPDISK_SERIAL` gives a real CDC serial port **and** MTP. PlatformIO's Teensy platform 5.1.0
  knows this flag (so it does not also add `-DUSB_SERIAL`).
* ❌ **Do not add KurtE's `MTP_Teensy` library.** The **Teensyduino 1.60 core already contains MTP**
  (`cores/teensy4/MTP_Teensy.h`, pulled in by `Arduino.h`). The library redefines `MTPStorage` and `MTP_class`
  → "redefinition" errors. The earlier release notes ("you also need the MTP_Teensy library") describe the
  1.57 era.
* ❌ **FastLED 3.10.2 / 3.10.3 break the build with the MTP USB type.** Their SD-card source includes the core's
  `fs.h` *before* `Arduino.h`; with MTP enabled, `fs.h → Arduino.h → MTP headers → needs FS`, which is not yet
  declared. It only triggers on a case-insensitive filesystem (FastLED probes `<fs.h>`, the core's file is
  `FS.h`), i.e. macOS. Reproduced with the real core headers: fs.h-first + MTP gives exactly the error seen;
  Arduino.h-first, or MTP off, compiles. **Pinned to FastLED 3.10.1**, which never compiles that file.
  (Forcing `-include Arduino.h` also fixes it in the reproduction but would hit every C and assembler file.)
* The MTP class has no `end()`, so leaving the mode is a reboot.
* PJRC labels MTP as experimental and notes that simultaneous access by the PC and the Teensy is limited — hence
  the dedicated mode that stops playback first. macOS has no native MTP support.

---

## 4. Configuration and show logic

### ✅ NFC and the tap ring moved off the Teensy

The local reader (`NfcReader.h`) and its 24-LED tap ring are gone. Tags are read by the wearer's ESP32-S3 hand
unit and forwarded (ESP-NOW → body bridge → UART JSON, `EspBridge.h`). Feedback — LED flash, vibration
double-click — happens on the hand unit, at the point of contact. This also removed the second I²C consumer
from the Teensy and freed pins.

**Dispatch semantics.** The hand unit sends `p` (proximity, 10 Hz, informational), `n` (raw detection, logged
for UID discovery only) and `c` (confirmed connection). Only `c` dispatches. The hand unit's touch state machine
already debounces and enforces a post-connection silence, so `c` fires once per genuine tap; the Teensy's
per-tag `cooldown_ms` is a second, optional safety net. `EspBridge.h` parses lines with ArduinoJson (already a
dependency); a torn line returns an error instead of being misread.

### ✅ LED config schema simplified; `led_brightness` fixed

Chapters once had three LED parameter sets (`led_background`, `led_enter` for the removed tap ring, `led_beat`).
They became two: `led_background` (the one ring's persistent pattern, usually `level` or `heartbeat`) and
`led_enter` (a one-shot on entry). A tag's `"do": "led"` action still works. In passing, a bug was fixed:
`led_brightness` was parsed but never applied — `leds.setGlobalBrightness(cfg.ledBrightness)` is now called
after the config loads.

### ✅ Several UIDs per tag role (spares)

The catalogue calls for **39 physical tags per card** (3 per person × 7, 3 start, 3 narrator, 6 + 6 overlay), but
the loader holds 32 tag entries. A tag entry can now list several UIDs (`"uids"`, up to 8), so a card needs
11 entries; the old single `"uid"` still works and the two merge. UIDs are stored upper-case; the same UID
under two roles gives a warning and the first entry wins.

`tag_catalogue.json` is the single source for every UID; `generate_player_configs.py` validates it (4- or
7-byte hex, no duplicates across roles, at most 8 per role, no unknown keys) and writes nothing if anything is
wrong. Empty strings are unprogrammed spare slots.

### ✅ Tag types, the person-tag lock and the sound roles

`type` is `person`, `start`, `location` or the legacy `device` (descriptive before; now it drives behaviour).

* **`person`** tags start a chapter. With `encounter_lock` they are accepted only while the base chapter plays;
  otherwise they are refused with the *denied* sound. The generator's default is the testing behaviour (switch
  at any time); `--lock` builds the show version. Narrator, overlay and start tags are never locked.
* **Three feedback sounds**, slots configured under `sounds`: *connect* (a person tag accepted), *denied* (refused),
  *ready* (an encounter ended and it returned to base). A slot of `-1` is silent.

### ✅ Start tag and the timed ending

The **start** tag begins the show clock. `end_after_min` later the show wraps up. Design choices:

* **Finish the current chapter first.** A once-chapter simply plays on. A *looping* chapter (`base`) has no end
  of its own, so it is **released**: `setPlayOnce(start, loopEnd)` with the chapter's own times flips the player's
  stop-at-end flag mid-play, and it stops cleanly at its loop end. The finish detection treats a released loop
  like a once-chapter.
* **No new encounters while ending** (person tags are refused with the *denied* sound); otherwise taps could
  extend the show indefinitely. Narrator and overlay tags still work.
* **End chapter, then "show over".** When `end_reflection` finishes (however it was reached) the player stops,
  overlays are cleared and the LED ring is set to `off`. Only the start tag is accepted; it restarts the show
  from `base` with a fresh clock. A start tag during the ending also restarts. No "ready" sound when going to the
  end chapter.
* **A missing end chapter** (typo) would otherwise retry every loop iteration; instead the show ends cleanly
  without it, and the boot log warns.
* The clock runs from the **start tag**, not from boot (tested: a unit booted 20 minutes earlier still gets its
  full 10 minutes).
* Scope: it switches off the **Teensy's** sound and ring. Hand units and body bridges keep running.

---

## 5. LED

### ✅ `FastLED.show()` must be rate-limited

Un-throttled `show()` calls from `loop()` made the PWM haptic output stutter in time with LED frames (the PWM DMA
was more sensitive than I²S, which has a hardware FIFO). Hard cap at 25 fps (`LED_FRAME_MS = 40`) and `yield()`
after each `show()`. The haptic output is now on I²S 2, but the throttle was kept.

### ✅ Very low intensities look like "off"

`breathe` at `intensity: 0.12` fell below the LED's visual threshold for ~10 s per cycle. Fixes: a 25 % floor in
the breathe range (`0.25 + t × 0.75`), an absolute floor in the colour helper (`0.05 + b × 0.95`), idle intensity 0.35.

### ✅ Don't reset an animation's phase when only its parameters change

Calling `setBackground()` on every chapter entry restarted the running animation (a visible brightness jump).
Phase and step now reset only when the animation *type* changes.

### ℹ️ `led_animations.json`

Custom animations are loaded at boot and checked **before** the built-in names. The shipped file defines one
(`clockwise_chase`) that no config references; it costs a small SD read and some reserved RAM. It can be deleted
from the cards safely (the boot log says custom animations are unavailable).

---

## 6. ESP32 firmware and toolchain

### ✅ Pin the ESP32 platform: `platformio/espressif32@6.13.0`

The toolchain moved under this project several times in a few months:

1. **Arduino-ESP32 core 3.0 (ESP-IDF 5.x)** is a major version. It changed the **ESP-NOW callback signatures**
   (receive *and* send, not in lockstep — one intermediate pioarduino release had the new receive signature and
   the old send signature) and replaced the **LEDC (PWM) API** (`ledcSetup/ledcAttachPin` → `ledcAttach`). Both are
   in Espressif's 2.x→3.0 migration guide. The code carries compile-time switches (`ESPNOW_OLD_API`, a
   `MOTOR_LEDC_NEW_API` auto-detect) for both generations.
2. PlatformIO's *official* platform lagged on 3.x support, which is why the community **pioarduino** fork exists.
   Adopting it brought its own problems: a bundled **esptool 5.4.0 that crashed on upload**, a stray `pioarduino`
   PyPI package conflicting with `platformio` in the same venv, and PIO Home showing the wrong branding (fixed
   by reinstalling the `platformio` package). pioarduino was dropped.
3. `platformio/espressif32@6.13.0` (the **official** platform) compiles and flashes. Its numbering is PlatformIO's,
   not Arduino's: the build log shows `framework-arduinoespressif32 @ 3.20017.241212` = **Arduino core 2.0.17**
   (ESP-IDF 4.4), with esptool 4.11.
4. ❌ **An unpinned `platform = espressif32` does not reproduce an old environment.** "Latest" moves with the
   registry; in practice PlatformIO re-used the cached 6.13.0, so removing the pin changed nothing.

Version-tied lessons: rule out toolchain changes by reading the build log's `PLATFORM:` and `framework-…` lines
before theorising about firmware.

### ✅ ESP32-S3 SuperMini variants: use the standard board, not v0.0.2

Two board versions are in circulation. The **v0.0.2** (supposedly corrected USB OTG) behaves differently — notably a
different **status-LED colour order**. The default in the firmware is **GRB** (standard board); a v0.0.2 needs
`-DSTATUS_LED_ORDER=RGB`. Mixed boards on the bench explained a long stretch of wrong LED colours (red/green swapped)
and was suspected in the next item.

### ✅ One-directional ESP-NOW failure — gone with standard boards (mechanism not isolated)

**Symptom:** hand → body worked (broadcast and unicast reached the body), body → hand failed: every body unicast
logged `send callback: FAIL`, even at boot to a stale stored peer. PONGs and heartbeats never reached the hand unit,
so it stayed unpaired.

**Ruled out (no change):** platform version, CPU frequency (80 vs 240 MHz), `peer.channel = 0` vs the Wi-Fi
channel, forcing a common channel with `esp_wifi_set_channel`, removing the explicit `WiFi.setSleep(false)`,
and un-pinning the platform (it resolved to the same cached 6.13.0). The `git` history of the project showed the
original working code was simply `WiFi.mode(WIFI_STA); WiFi.disconnect();` then `esp_now_init()`.

**What changed it:** swapping boards — a **v0.0.2 board had ended up on the test bench** next to standard ones. Once the
test units were standard boards, pairing with `espnow scan`, PONG, heartbeat and tag messages all worked in both
directions.

**Honest status:** the exact failing mechanism was not isolated. A web search turned up reports that some
SuperMini boards ship with the ceramic antenna mounted backwards (the feed trace lands on the unconnected pad), which
would fit a transmit-only failure, but that was never confirmed on these boards. If it ever returns, inspect the
antenna orientation and test with a different board before touching software.

### ✅ ESP-NOW behaviours to remember

* Unicast needs a peer; broadcasts work without one. The hand unit falls back to broadcast for NFC/touch while it
  considers itself unpaired.
* **A body bridge must reject data until it is paired**, and only from its paired MAC. It once accepted tag and
  proximity packets from any hand unit while "not paired" (the filter was `handPaired && mismatch`, which is a no-op
  when unpaired); the check is now `!handPaired || mismatch`. `lastRxMs` (link liveness) is only updated by the
  paired hand, otherwise foreign traffic would keep the LED green.
* Pairing: `espnow scan` (PING broadcast → PONG, both store the MAC) and a button method (body long-press 2 s →
  PAIR_REQUEST broadcast every 300 ms for 30 s → the hand's tap → PAIR_ACK).

### ✅ PN532 over UART (Seeed library): the initialisation that works

Pins: ESP32 TX **GPIO 6** → PN532 RXD, ESP32 RX **GPIO 5** ← PN532 TXD, RST **GPIO 10** (GPIO 21 is not populated on the SuperMini).
DIP switches SEL0 = SEL1 = LOW.

```cpp
#define NFC_INTERFACE_HSU
#include <PN532_HSU.h>
#include <PN532_HSU.cpp>   // include the .cpp directly — build flags do not reliably reach library sources
#include <PN532.h>

HardwareSerial MySerial(1);
PN532_HSU pn532hsu(MySerial);   // NO rx/tx arguments in the constructor
PN532     nfc(pn532hsu);

gpio_hold_dis((gpio_num_t)NFC_RST_PIN);        // release the sleep hold first
gpio_hold_dis((gpio_num_t)NFC_TX_PIN);
pinMode(NFC_RST_PIN, OUTPUT); digitalWrite(NFC_RST_PIN, LOW);   // 100 ms, without delay()
pinMode(NFC_RST_PIN, INPUT);                   // high-Z: the module's own pull-up brings RST high
// wait ~50 ms for the PN532 to boot
MySerial.begin(NFC_BAUD, SERIAL_8N1, NFC_RX_PIN, NFC_TX_PIN);
nfc.begin();                                   // AFTER MySerial.begin — it keeps our pins
uint32_t ver = nfc.getFirmwareVersion();
```

* **Why `INPUT` and not `digitalWrite(HIGH)`:** after deep sleep with the hold on RST, releasing the hold and then `pinMode(OUTPUT)` +
  `digitalWrite(HIGH)` sometimes fails (an output-latch race). High-Z lets the module's pull-up do it reliably.
* **Why include `PN532_HSU.cpp`:** the Seeed library wraps its implementation in `#ifdef NFC_INTERFACE_HSU`, and a `-D` build flag does
  not reliably reach the library's own `.cpp`.
* **Why `nfc.begin()` last:** `PN532_HSU::begin()` calls `_serial->begin(115200)` with no pins, which on ESP32 means "keep the current
  pins". Set the pins with `MySerial.begin(...)` first, then `nfc.begin()`.
* The re-init used by the `nfc` command and by recovery (`nfcReinit()`) simply pulses RST low then high with `digitalWrite`; the
  high-Z release is the boot path after a sleep.
* **Not needed:** the 16 × `0x55` wake-up preamble, as long as RST is wired — after a clean reset pulse the PN532 boots into a known state.
* **`NFC_SLEEP_MS > 0`** (PN532 power-down between polls) would save about 75 mA but needs that preamble after every sleep; a flag
  (`inPowerDown`) in `nfcTask` would avoid sending it to an awake chip. Deferred; it is 0 (always on) for reliability.

### ✅ No double-precision maths next to the NFC task

A ring animation that used `sinf()` with `TWO_PI` (a **double** constant) made the NFC task on core 0 fail: the ESP32-S3's FPU is
single-precision only, so the double arithmetic ran in software and disturbed task scheduling. Replacing the per-LED `sinf()` by
FastLED's `sin8()` (an integer lookup table) fixed it:

```cpp
uint8_t s = sin8(phaseBase + i * (256 / LED_COUNT));
```

### ✅ Order matters: clear the LEDs before stopping Wi-Fi

`FastLED.show()` uses the RMT peripheral, and `esp_wifi_stop()` resets RMT. Always blank and show the LEDs *before* stopping Wi-Fi when
going to sleep, never after.

### ✅ Motor: 20 kHz, and bursts beat proximity

25 kHz does not work on this board; 20 kHz is inaudible and works. Bursts are timed by an `esp_timer` ISR, independent of `loop()` and of
NFC polling. `motorProxSet()` (continuous proximity vibration) is ignored while a burst is active.

### ✅ ESP-NOW "send success" is not delivery

The `onSent` callback with `ESP_NOW_SEND_SUCCESS` only says the frame was *transmitted*, not received. True link state comes from the
body bridge's heartbeat (every 1 s): the hand unit's status LED is green while heartbeats arrive and reverts to yellow after
`LINK_TIMEOUT` (**3.5 s** in the current code; the old notes said 2 s).

### ✅ Battery ADC: use `analogReadMilliVolts()`

It applies the eFuse-calibrated reference. At 11 dB attenuation the ADC saturates near 3.1 V, not 3.3 V, so the raw formula
`analogRead() × 3300 / 4095` overestimates by about 7 %. (An older note says the reading was still ~10 % high even then; that was before
the real cause — the divider is on the 5 V rail — was found.)

### ✅ One I²C bus

The VL53L0X uses the global `Wire` (the Pololu library cannot be pointed at another bus); the PN532 is on UART precisely to avoid I²C
contention. An earlier attempt with two buses (`Wire` + `Wire1`) made the PN532 unreliable on `Wire1` under concurrent access.

### ✅ Heat reduction (hand unit and body bridge)

The ESP32-S3 ran hot at the default 240 MHz. Applied to both devices: `setCpuFrequencyMhz(80)` as the first line of `setup()`, and
`vTaskDelay(pdMS_TO_TICKS(1))` as the last line of `loop()` so the idle task can light-sleep the CPU. The peripherals (UART, I²C, RMT,
LEDC, `esp_timer`, ADC) use their own clocks and are unaffected; 10 ESP-NOW packets a second is trivial at 80 MHz.

**Wi-Fi modem sleep — do not copy the old advice.** The first notes said to add `WiFi.setSleep(true)` after `WiFi.disconnect()`. The
code that shipped had `WiFi.setSleep(false)` with a leftover comment still saying "modem sleeps", i.e. it had been reversed at some
point; the current file sets nothing at all. Re-enabling modem sleep needs a heartbeat-reliability test first.

### ✅ Hand-unit LED: a strip of 5, not a ring

The hand unit's ring (16 LEDs in the source default, 8 in the first notes) was replaced by a strip of 5 WS2812B LEDs cut from an 8-LED strip.
The firmware depends on the count only through `LED_COUNT`: the array, `addLeds`, `fill_solid`, the idle wave spacing `256 / LED_COUNT`
and the rainbow test. With 5 LEDs the spacing is 51 phase units, so the strip shows one full cycle of the travelling wave. Nothing else
is hard-coded. The player's 16-LED ring (Teensy pin 14) is unchanged. `LED_COUNT` has to be set to 5 in `Config.h` and reflashed — the
README's tunables table says so.

### ✅ Hand-unit power management

* A reset or power-up goes to deep sleep; the button (GPIO 9, ext1 wake) starts it. A tap < 2 s is a "short press"
  (confirms a pending pairing); ≥ 2 s sleeps.
* Pins that must hold their level through sleep (button, PN532 reset / TX, VL53L0X XSHUT) are latched with
  `gpio_hold_en`, and every hold must be released with `gpio_hold_dis` after wake before `pinMode`/`digitalWrite`
  work again.
* The PN532 needs its reset line (GPIO 10) to recover a stuck TX line; `NFC_SLEEP_MS = 0` keeps it always on.
* The CPU runs at 80 MHz — 240 MHz ran hot.

### ✅ Battery measurement: the divider is on the 5 V rail

**Symptom:** the hand unit logged `[BAT] 4772 … 4882 mV` — above anything a 1S LiPo reaches (4.2 V) — and the log
only exists on USB.

**Cause:** the divider on GPIO 3 hangs on the board's **5 V rail**, which is the USB 5 V when plugged in, or the cell
voltage **minus a Schottky diode** (about 0.3 V) when on battery. Measured on one unit: cell 3.80 V, pin 1.74 V →
rail 3.48 V → offset 320 mV.

**Fix in firmware:** estimated cell voltage = rail + a per-unit offset (default 320 mV, `battery cal <batV> <pinV>`,
stored in flash); a rail above 4.3 V means USB, reported as "battery not measurable" and never triggers LOW or
CRITICAL. Thresholds (3600 mV low, 3300 mV critical → sleep) apply to the corrected cell voltage. Caveats: a fixed
offset is good to about ±0.1 V because the diode drop varies with load; there is no charge indication on USB.

**The proper hardware fix** is to move the divider's top to the BAT+ pad (true cell on USB and battery). The hand-unit design notes show
a **100 nF capacitor from GPIO 3 to ground** — check that it is really fitted: a 50–110 kΩ divider reads a little low on the ESP32's ADC
without it (not checked against Espressif's guidance). The notes and `Config.h` say 100 kΩ + 100 kΩ, a comment in `PowerManager.h` says
220 kΩ — measure your board.

### ⚠️ VL53L0X: one unit still not working properly

**Symptom:** some hand units reacted only at very short range.

**Library facts (Pololu VL53L0X):** `init()` follows ST's sequence (factory reference SPADs, tuning table, VHV and phase
calibration) but not offset or crosstalk calibration (the library says reference-SPAD management is done by ST and
"should work well enough unless a cover glass is added"). The default signal-rate limit is 0.25 MCPS; this project used
0.5, and ignores readings under 50 mm as crosstalk.

**Diagnostics added** (`tof …`): per measurement the device status code (ST's names: 4 MSRC no target, 6 range phase
check, 9 phase consistency, 11 range complete, …), the return signal rate, the ambient rate and the SPAD count; the
window, rate limit, timing budget, period and long-range mode are tunable and storable per unit.

**What the data showed** (empty room, then a hand waved at 10–15 cm):

| | good unit | bad unit |
|---|---|---|
| ambient rate | ≈ 0.4 MCPS | 12–15 MCPS (about 30×) |
| idle SPAD count | 194 | 181 |
| return signal with a hand | 20–28 MCPS peaks, 10–12 valid readings per wave | ≤ 4.7 MCPS, almost no valid readings |
| empty room | clean | a few false "valid" readings (0 mm, 154–591 mm) |

The ambient rate and SPAD count are measurements, not settings; no register value is known that fixes them. The bad
module was replaced; **one unit is still not working completely** (to do). Next checks: reboot several times and note
the ambient each time, swap modules between a good and a bad unit, test with the ring off and the motor idle.

### ⚠️ GPIO 48: a second (red) LED shares the pin with the RGB LED

On the SuperMini schematic the onboard WS2812 (`LE1`) *and* a separate red LED (`LED1`, via a 1 kΩ `R1` to GND) are
on GPIO 48. On two of seven hand units the red LED glows faintly when the unit should be off. All seven run the same
sleep code (which never drives or holds GPIO 48 — the pin floats), so the cause is probably the board: the schematic
shows an **optional 10 kΩ pull-up `WSR1` (marked NC)** from 3 V3 to the data line, and a fitted one would push roughly
0.1 mA through the red LED. **Test not yet done:** hold the chip in reset and see if the glow stays (hardware) or goes
(firmware pin state). Fixes: remove `WSR1` / `LED1` / `R1`; driving the pin low and holding it during sleep also works
but wastes ~0.3 mA through a fitted pull-up.

---

## 7. How changes were verified

This project is developed with an AI assistant in an environment that **cannot flash hardware or compile for the
Teensy/ESP32 targets**. Verification therefore has two tiers, and this document records which is which.

* **On hardware (by the user):** reported working.
* **Simulated:** the real source text is compiled on a host against mocks — the config loader with the real ArduinoJson
  and every generated card; the real `ramp`/finish-detection/tag-dispatch/CLI code sliced out of `main.cpp`; the
  waveshaper tables run through the Audio library's own `shape()`/`update()` code on all 65 536 sample values. Several
  suites were also checked with deliberate breakage ("mutation checks") to prove the tests can fail — one test
  harness passed vacuously on its first version and was rewritten.

| Feature | Status |
|---|---|
| ESP-NOW pairing by `espnow scan`, heartbeat, tag dispatch | confirmed on hardware |
| Haptic soft limiter (drive 0.5) | confirmed on hardware |
| Timed ending, show over, restart by start tag | confirmed on hardware ("works in one go") |
| `tof` diagnostics | used on hardware (readings captured) |
| USB maintenance mode (MTP) | builds and flashes; use not reported |
| Spare tags (`uids`), tag catalogue and generator | simulated against all seven generated cards; not reported |
| Person-tag lock, three feedback sounds | simulated; not reported |
| Ducking | simulated; not reported |
| Battery correction + `battery cal` | simulated; not reported |
| Config name `*_config.json` | simulated; not reported |
| `assemble_71.sh` channel handling | tested with synthetic stems incl. the 10-channel accident; not reported |
| **Button pairing** (body long press + hand tap) | implemented; **not confirmed end to end** |

---

## 8. Platform considerations

### Raspberry Pi Pico 2W — evaluated, not chosen

* No Teensy Audio Library equivalent — no `AudioMixer4`, `AudioPlaySdWav`, patch-bay model; everything would be rewritten.
* `BackgroundAudio` (the best Pico audio library) cannot read from SD inside the audio interrupt — it needs main-loop
  feeding, which makes the SD-read-per-interrupt design impossible.
* No audio-shield equivalent — an external I²S DAC is needed.
* 520 KB RAM versus 1 MB — tighter for RAM effects.

The Teensy 4.1 (600 MHz Cortex-M7, 1 MB RAM, mature Audio Library) is much better suited. If a Pico 2W were ever
needed, its built-in Wi-Fi would allow device-to-device sync over UDP — a cleaner basis for a duet mechanic than NFC
proximity.

---

## 9. Open issues and next steps

| # | Item | State |
|---|---|---|
| 1 | One hand unit's VL53L0X still misbehaves | ⚠️ open — see section 6 ("VL53L0X: one unit still not working properly") |
| 2 | Faint red LED glow on GPIO 48 on two hand units | ⚠️ open — reset test not yet run |
| 3 | Button pairing confirmed end to end | ⚠️ open |
| 4 | Move the hand unit's battery divider to BAT+ (and confirm the 100 nF capacitor is fitted) | optional hardware fix; firmware correction is in |
| 5 | Calibrate `battery cal` on every hand unit (needs a multimeter and an unplugged unit) | to do |
| 6 | Real PCB schematic / board exports into `docs/` (placeholders are in place) | to do |
| 7 | Generate show builds (`--lock`, final `--end-after`), program the spare tags | to do before a show |
| 8 | `tools/editor.py` does not know `uids`, the new tag types or the show settings | known limitation; the generator is the master |

---

## 10. Housekeeping

* `configs/gnerate_player_configs.py` (typo in the name) is a stale duplicate of `generate_player_configs.py` — delete it.
* `ESP32handUnit/Readme.md` and `context.md` have been merged into this README (sections 11, 15.6, 15.8–15.10, troubleshooting) and this
  file (section 6) and can be deleted. What was **not** carried over because it is outdated: the 8-LED ring (the source default was 16, and the units now carry a 5-LED strip), `PROX_NEAR_MM 40`
  (now 20), the old status-LED colour table (replaced by the current language), the 2 s heartbeat timeout, `WiFi.setSleep(true)`, the
  note that the body-bridge → Teensy UART was only stubbed (it is implemented), and the early development sequence. Its UWB / Bitcraze
  remark belongs to a different project.
* `tools/card_log.csv` contains only a header line (`timestamp,uid_hex,tag_type`) — probably left over from the removed
  local reader; delete it if nothing uses it.
* `docs/experiencemap.png` is the old figure; the README now uses `docs/experience_map.*`, generated by
  `tools/make_docs.py`.
* The figures are code: change the protocol or the firmware flow, then update the matching function in
  `tools/make_docs.py` and re-run it. Real PCB exports under the placeholder names are never overwritten.

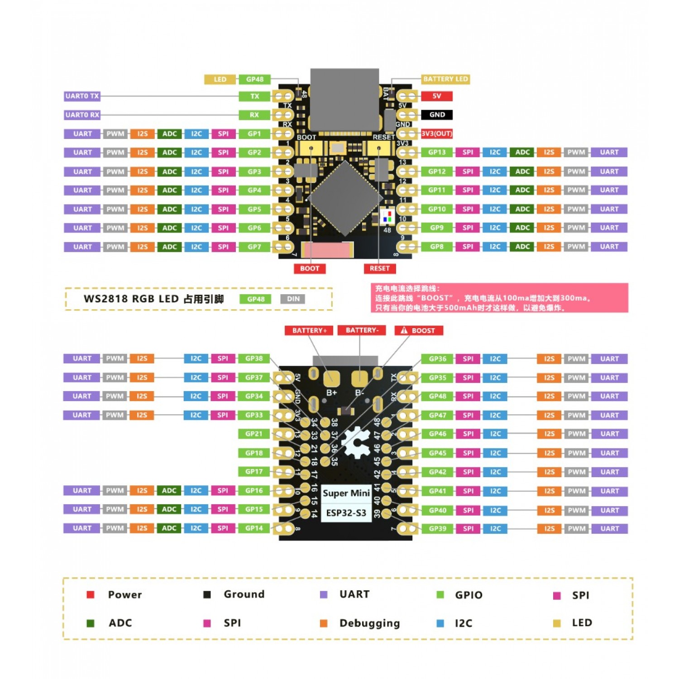
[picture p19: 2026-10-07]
docs/esp32-s3-supermini.jpg

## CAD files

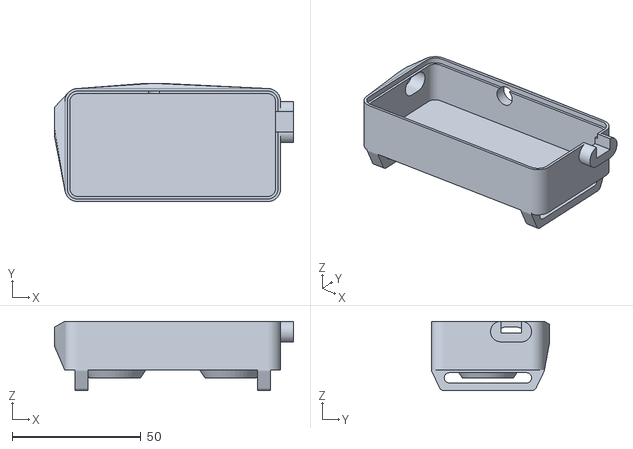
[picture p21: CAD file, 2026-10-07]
design/box.stl
93.0 x 46.0 x 27.0

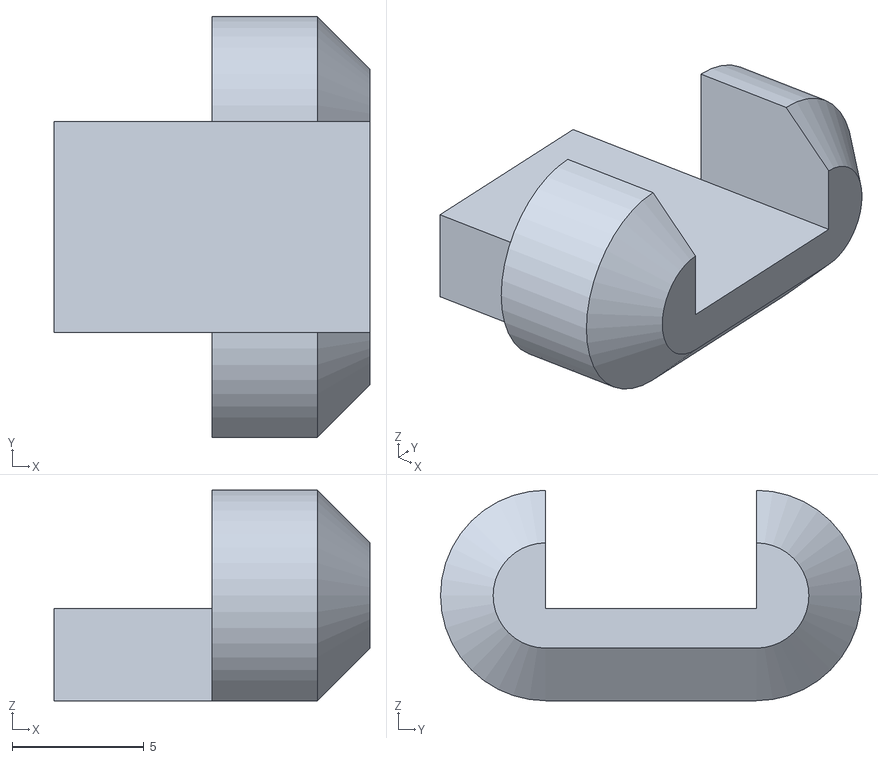
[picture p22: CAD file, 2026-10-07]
design/block.stl
12.0 x 16.0 x 8.00

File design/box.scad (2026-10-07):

$fn=40;
//translate([0,0,22])lid();
//projection()lid();
//box();

difference(){
rotate([0,90,0])hull(){cylinder(d=8,h=4);translate([0,8,0])cylinder(d=8,h=4);translate([0,0,4])cylinder(d=4,h=2);translate([0,8,4])cylinder(d=4,h=2);};

translate([0,0,-0.5])cube([12,8,5]);
}
translate([-6,0,-4])cube([7,8,3.5]);


module lid(){
                hull(){
        translate([74,0,17])cylinder(d=8,h=2);
        translate([74,34,17])cylinder(d=8,h=2);
        translate([0,34,17])cylinder(d=8,h=2);
        translate([0,0,17])cylinder(d=8,h=2);
    }
}

module bracket(){
difference(){
    hull(){
        translate([-2,6,0])cylinder(d=2,h=5);
        translate([40,6,0])cylinder(d=2,h=5);
        translate([36,0,0])cylinder(d=4,h=5);
        translate([2,0,0])cylinder(d=4,h=5);
    }
    hull(){
        translate([4,3,-0.01])cylinder(d=4,h=55);
        translate([34,3,-0.010])cylinder(d=4,h=55);
    }
}}
        


module box(){
    translate([-1,-2,-6])rotate([90,0,90])bracket();
translate([70,-2,-6])rotate([90,0,90])bracket();

difference(){
    union(){hull(){
        translate([74,0,0])cylinder(d=10,h=19);
        translate([74,34,0])cylinder(d=10,h=19);
        translate([0,34,0])cylinder(d=10,h=19);
        translate([0,0,0])cylinder(d=10,h=19);
         translate([-9,24,13])rotate([0,90,0])hull(){cylinder(d=7.5,h=30);translate([0,4,0])cylinder(d=7.5,h=30);};
         translate([29.7,30,14.3])rotate([-90,0,0])cylinder(d=7,h=11);
 
         }
           translate([78,22,15])rotate([0,90,0])hull(){cylinder(d=8,h=6);translate([0,8,0])cylinder(d=8,h=6);};
         
     }
        hull(){
        translate([74,0,2])cylinder(d=6,h=18);
        translate([74,34,2])cylinder(d=6,h=18);
        translate([0,34,2])cylinder(d=6,h=18);
        translate([0,0,2])cylinder(d=6,h=18);
    }
            hull(){
        translate([74,0,17])cylinder(d=8,h=3);
        translate([74,34,17])cylinder(d=8,h=3);
        translate([0,34,17])cylinder(d=8,h=3);
        translate([0,0,17])cylinder(d=8,h=3);
    }
    
    translate([-12,24,13])rotate([0,90,0])hull(){cylinder(d=7.5,h=30);translate([0,4,0])cylinder(d=7.5,h=30);};
    
    translate([29.7,30,14.3])rotate([-90,0,0])cylinder(d=7,h=20);
    
    translate([70,22,14.5])cube([20,8,5]);
}


translate([14.5,17,-3])difference(){
    cylinder(d1=20,d2=24,h=3);
    cylinder(d1=16,d2=13,h=3);
}

translate([14.5+45,17,-3])difference(){
    cylinder(d1=20,d2=24,h=3);
    cylinder(d1=16,d2=13,h=3);
}
}

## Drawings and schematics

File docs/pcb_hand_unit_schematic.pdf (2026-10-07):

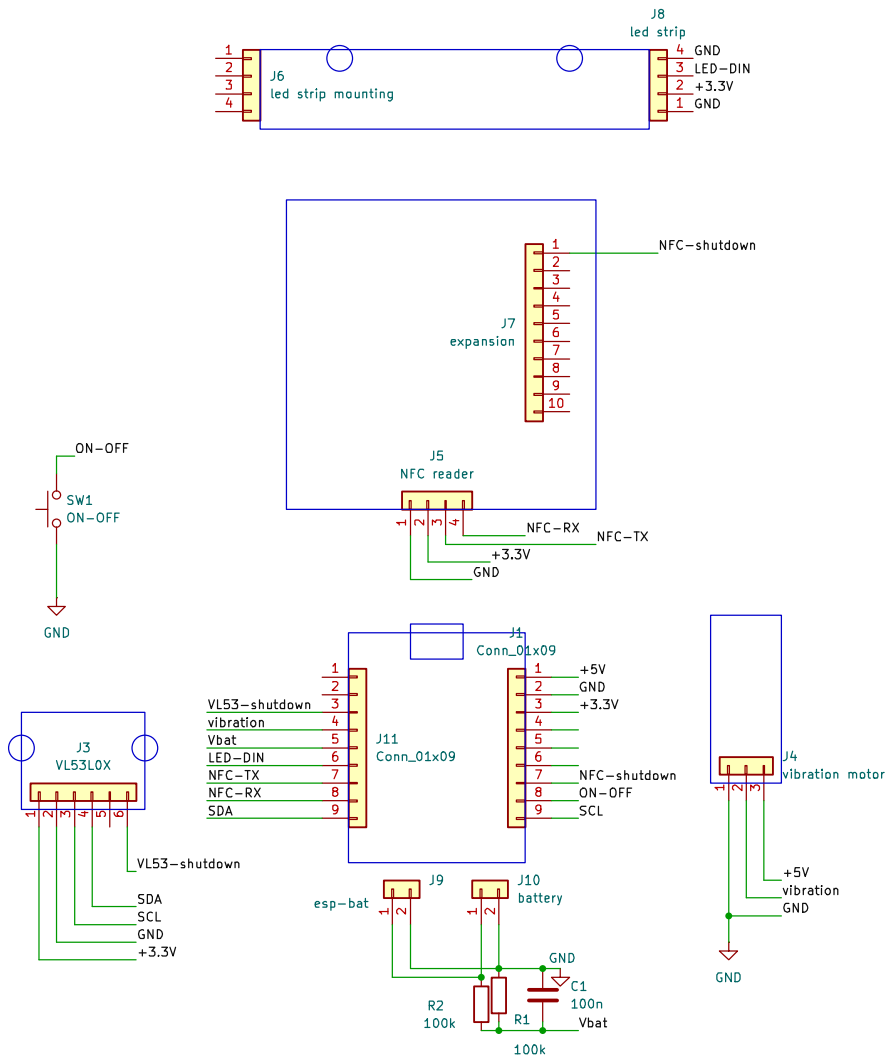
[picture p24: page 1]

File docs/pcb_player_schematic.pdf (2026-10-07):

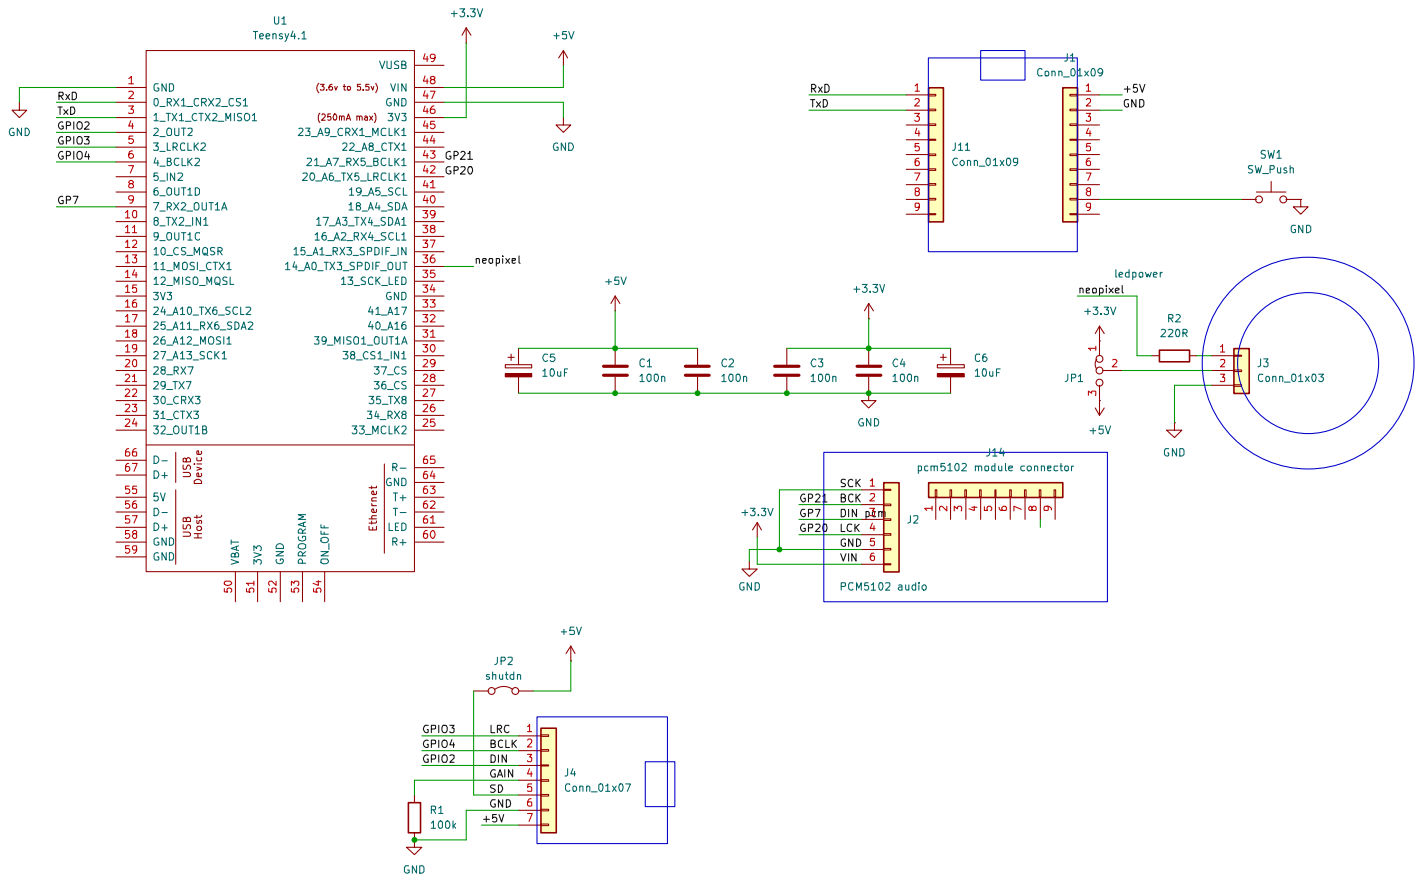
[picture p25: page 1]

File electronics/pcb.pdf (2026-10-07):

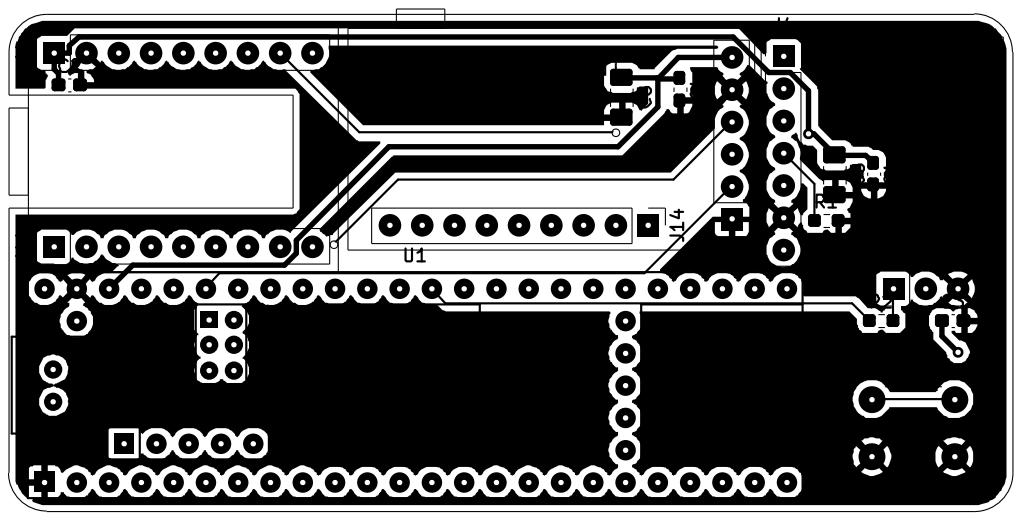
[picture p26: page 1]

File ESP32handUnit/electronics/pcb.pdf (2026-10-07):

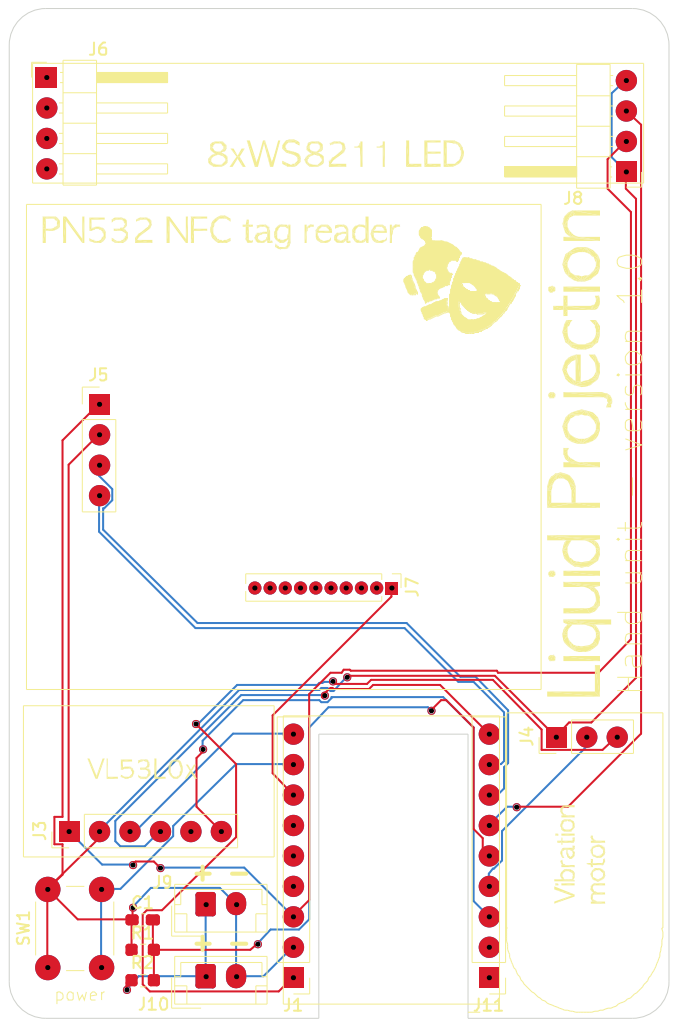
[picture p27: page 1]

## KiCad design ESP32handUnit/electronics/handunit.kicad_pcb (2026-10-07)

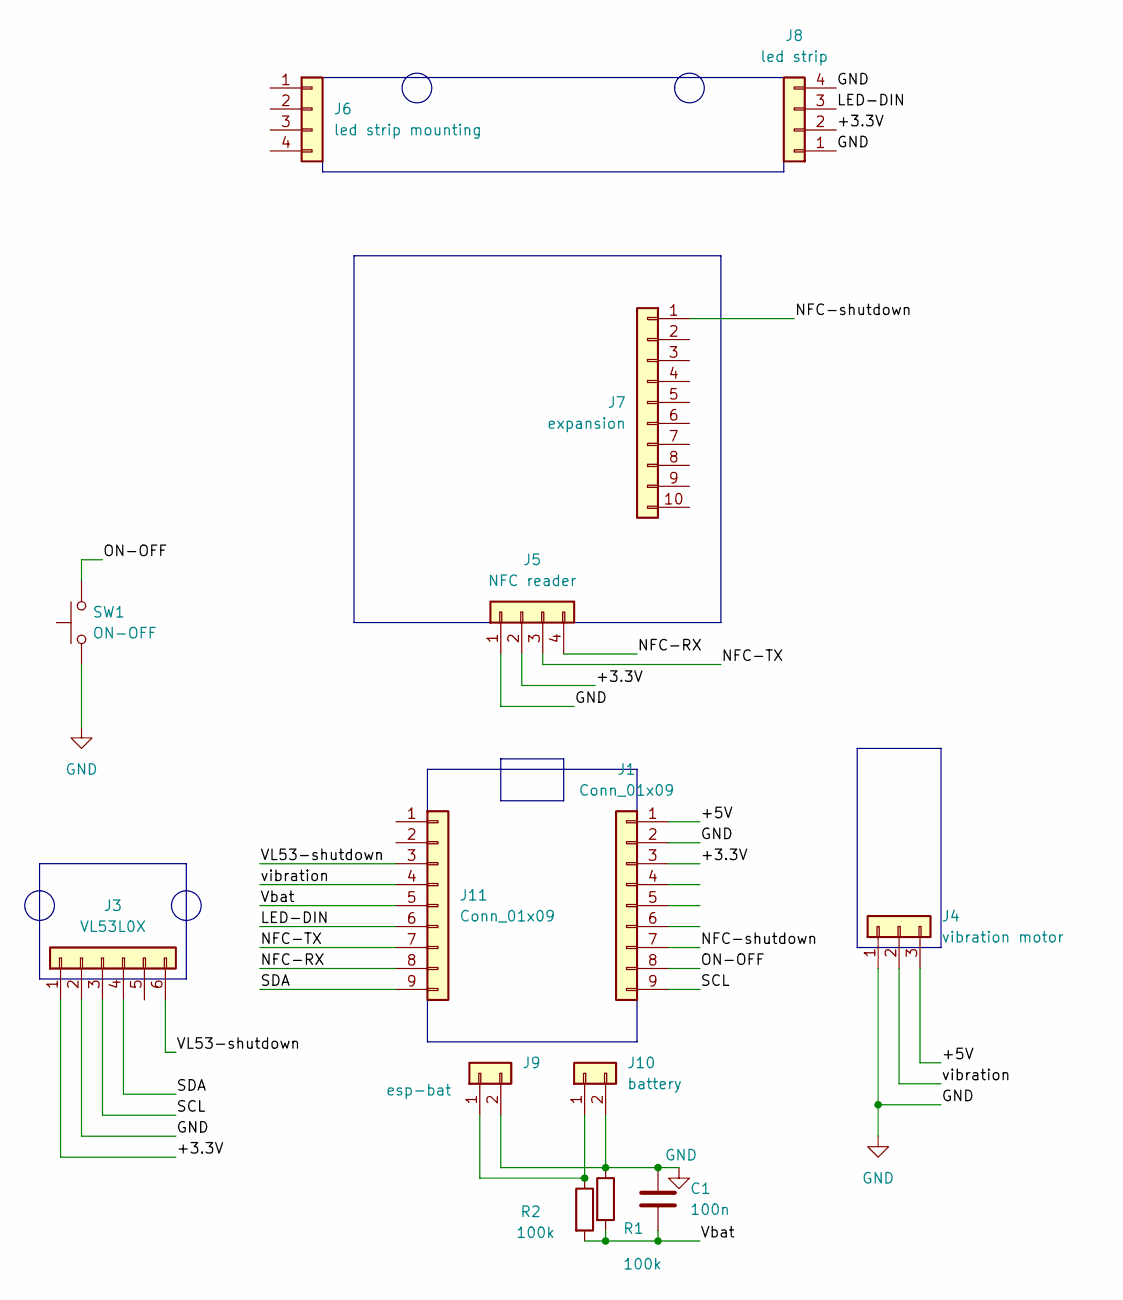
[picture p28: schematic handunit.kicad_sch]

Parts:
C1: 100n; C_0603_1608Metric_Pad1.08x0.95mm_HandSolder
J1, J11: Conn_01x09; PinHeader_1x09_P2.54mm_Vertical
J3: VL53L0X; PinHeader_1x06_P2.54mm_Vertical
J4: vibration motor; PinHeader_1x03_P2.54mm_Vertical
J5: NFC reader; PinHeader_1x04_P2.54mm_Vertical
J6: led strip mounting; PinHeader_1x04_P2.54mm_Horizontal
J7: expansion; PinHeader_1x10_P1.27mm_Vertical
J8: led strip; PinHeader_1x04_P2.54mm_Horizontal
J9: esp-bat; JST_EH_B2B-EH-A_1x02_P2.50mm_Vertical
J10: battery; JST_EH_B2B-EH-A_1x02_P2.50mm_Vertical
R1, R2: 100k; R_0603_1608Metric_Pad0.98x0.95mm_HandSolder
SW1: ON-OFF; SW_PUSH_6mm

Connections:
/+3.3V: J1.3, J3.1, J5.2, J8.2
/+5V: J1.1, J4.3
/LED-DIN: J8.3, J11.6
/NFC-RX: J5.4, J11.8
/NFC-TX: J5.3, J11.7
/NFC-shutdown: J1.7, J7.1 (Pin_1_1)
/ON-OFF: J1.8, SW1.2
/SCL: J1.9, J3.3
/SDA: J3.4, J11.9
/VL53-shutdown: J3.6, J11.3
/Vbat: C1.2, J11.5, R1.2, R2.2
/vibration: J4.2, J11.4
GND: C1.1, J1.2, J3.2, J4.1, J5.1, J8.1, J8.4, J9.2, J10.2, R1.1, SW1.1
unnamed: J9.1, J10.1, R2.1

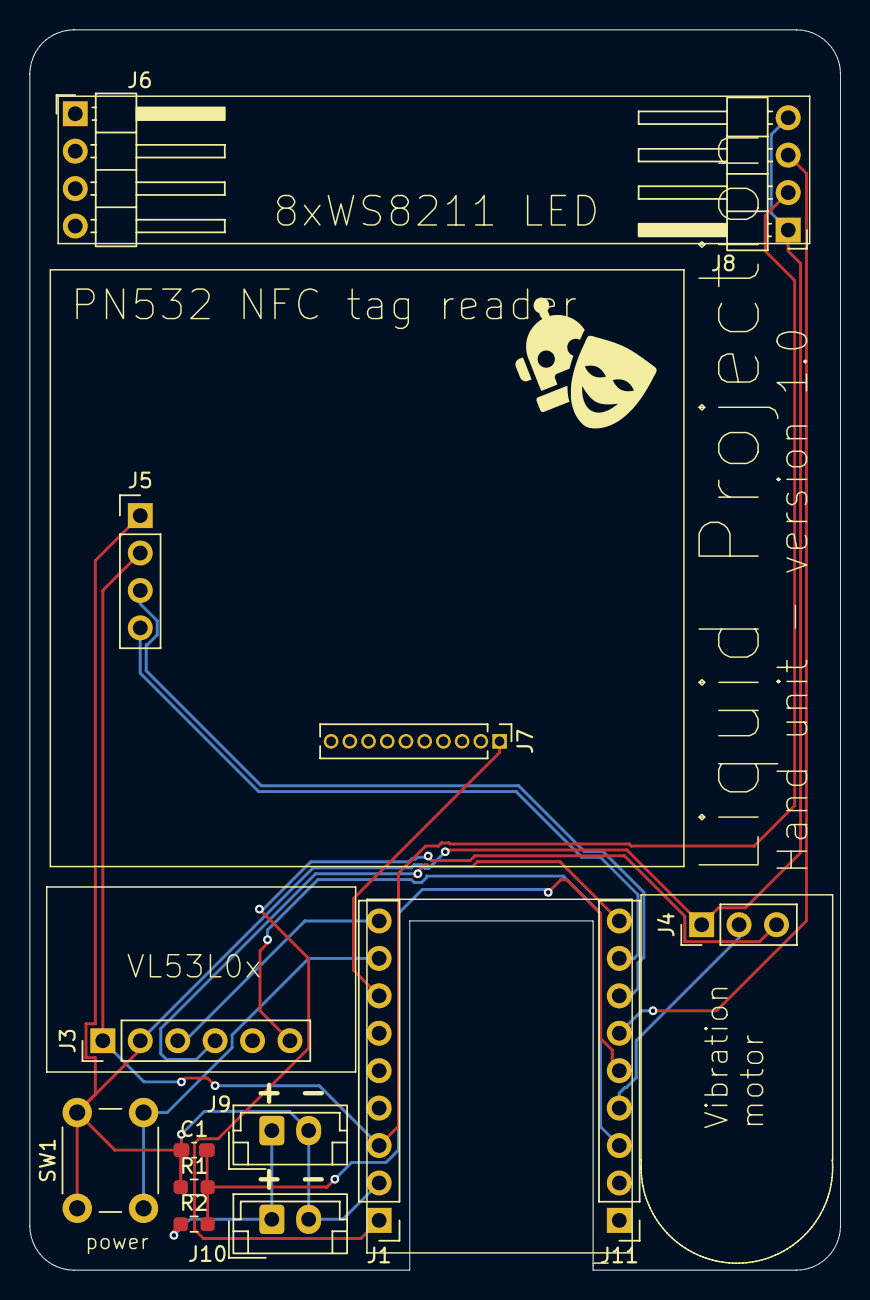
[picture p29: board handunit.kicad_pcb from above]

Board: 2 copper layers, 55.0 x 84.2 mm, 15 parts (0 on the bottom side), 14 nets.

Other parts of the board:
G: LOGO; logo

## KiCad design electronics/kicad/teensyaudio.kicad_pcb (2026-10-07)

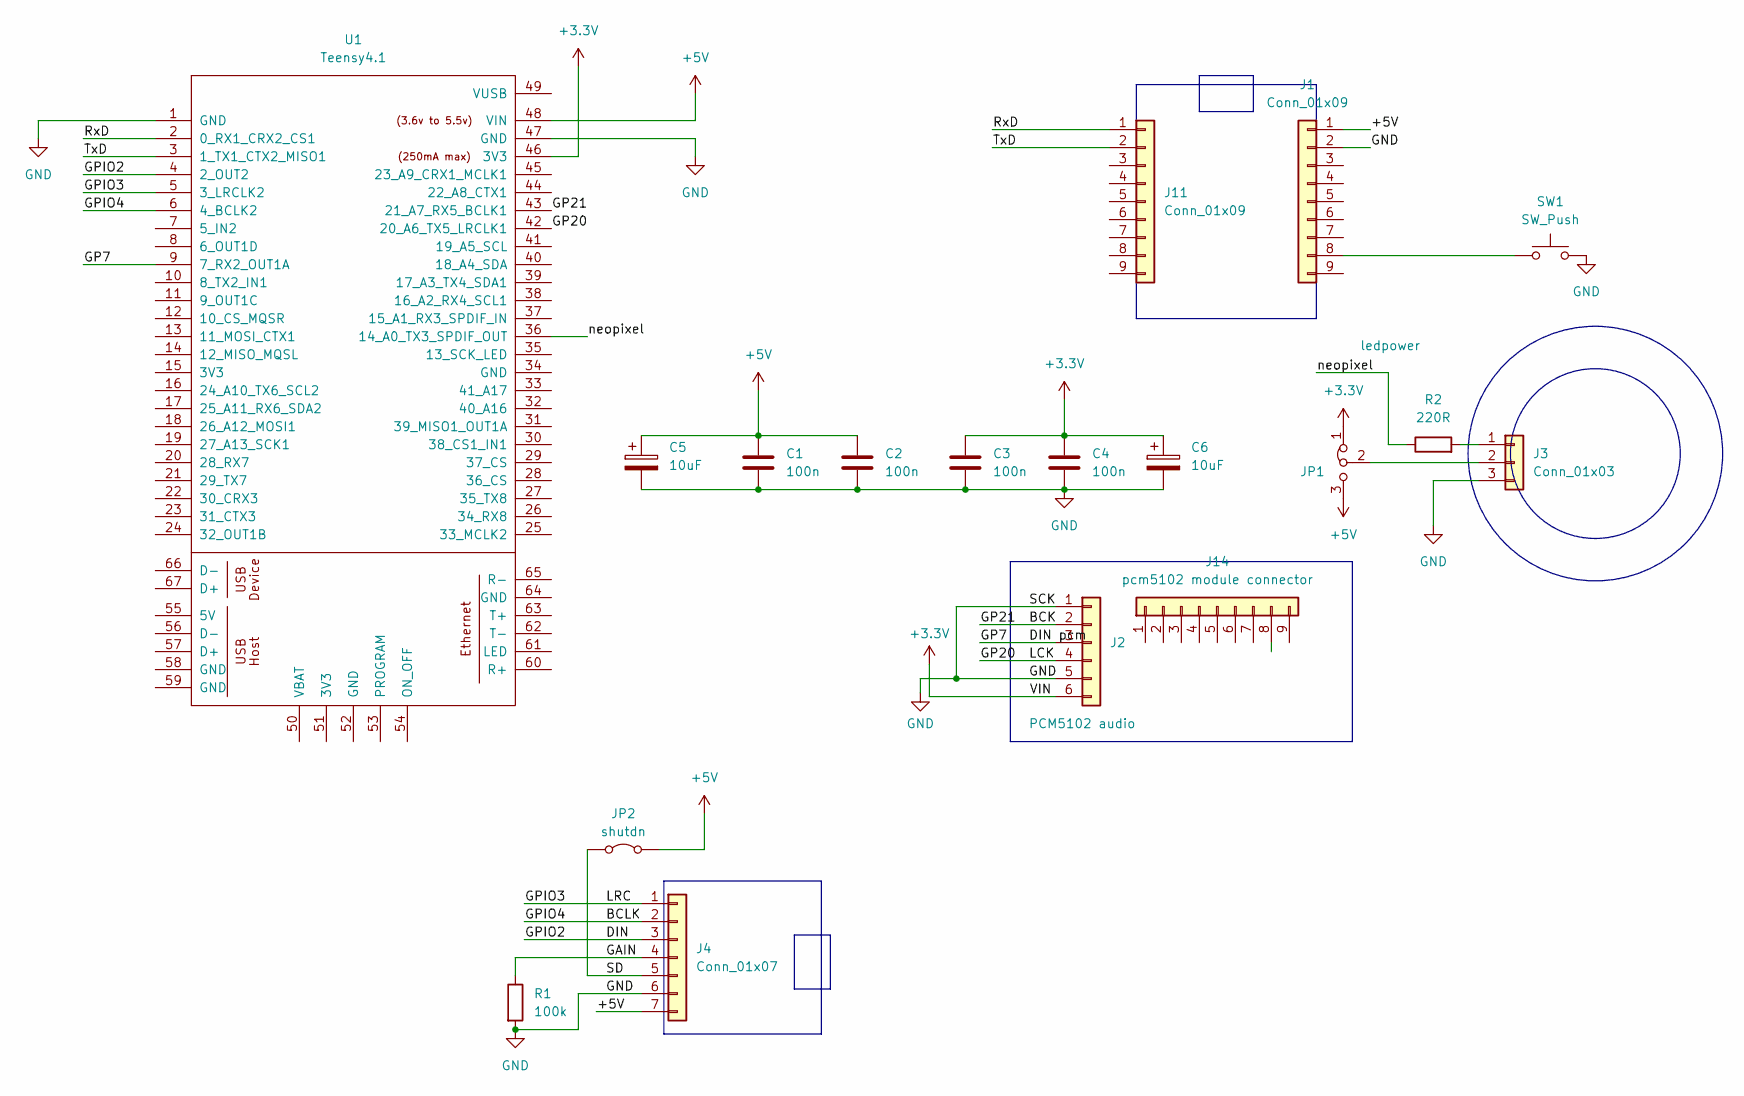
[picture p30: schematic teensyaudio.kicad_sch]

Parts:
C1, C2, C3, C4: 100n; C_0603_1608Metric_Pad1.08x0.95mm_HandSolder
C5, C6: 10uF; C_1206_3216Metric_Pad1.33x1.80mm_HandSolder
J1, J11: Conn_01x09; PinHeader_1x09_P2.54mm_Vertical
J2: PCM5102 audio; PinHeader_1x06_P2.54mm_Vertical
J3: Conn_01x03; PinHeader_1x03_P2.54mm_Vertical
J4: Conn_01x07; PinHeader_1x07_P2.54mm_Vertical
J14: pcm5102 module connector; PinHeader_1x09_P2.54mm_Vertical
JP1: ledpower; SolderJumper-3_P1.3mm_Bridged12_RoundedPad1.0x1.5mm
JP2: shutdn; SolderJumper-2_P1.3mm_Bridged_RoundedPad1.0x1.5mm
R1: 100k; R_0603_1608Metric_Pad0.98x0.95mm_HandSolder
R2: 220R; R_0603_1608Metric_Pad0.98x0.95mm_HandSolder
SW1: SW_Push; SW_PUSH_6mm
U1: Teensy4.1; Teensy41

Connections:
+3.3V: C3.1, C4.1, C6.1, J2.6, JP1.1 (A), U1.46 (3V3)
+5V: C1.1, C2.1, C5.1, J1.1, J4.7, JP1.3 (B), JP2.2 (B), U1.48 (VIN)
/BCK: J2.2, U1.43 (21_A7_RX5_BCLK1)
/BCLK: J4.2, U1.6 (4_BCLK2)
/DIN: J4.3, U1.4 (2_OUT2)
/DIN pcm: J2.3, U1.9 (7_RX2_OUT1A)
/GAIN: J4.4, R1.1
/GP20: J2.4, U1.42 (20_A6_TX5_LRCLK1)
/GPIO3: J4.1, U1.5 (3_LRCLK2)
/RxD: J11.1, U1.2 (0_RX1_CRX2_CS1)
/SD: J4.5, JP2.1 (A)
/TxD: J11.2, U1.3 (1_TX1_CTX2_MISO1)
/neopixel: R2.1, U1.36 (14_A0_TX3_SPDIF_OUT)
GND: C1.2, C2.2, C3.2, C4.2, C5.2, C6.2, J1.2, J2.1, J2.5, J3.3, J4.6, R1.2, SW1.2, U1.1 (GND), U1.47 (GND)
unnamed: J1.8, SW1.1
unnamed: J3.1, R2.2
unnamed: J3.2, JP1.2 (C)

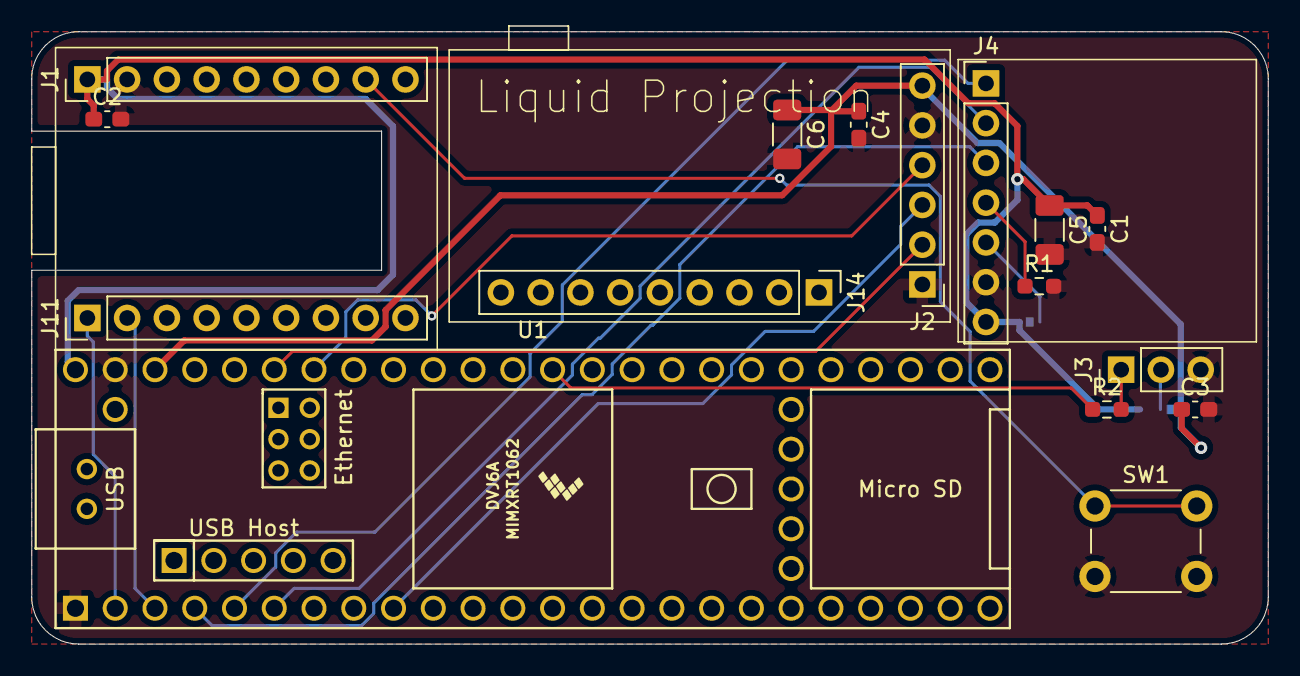
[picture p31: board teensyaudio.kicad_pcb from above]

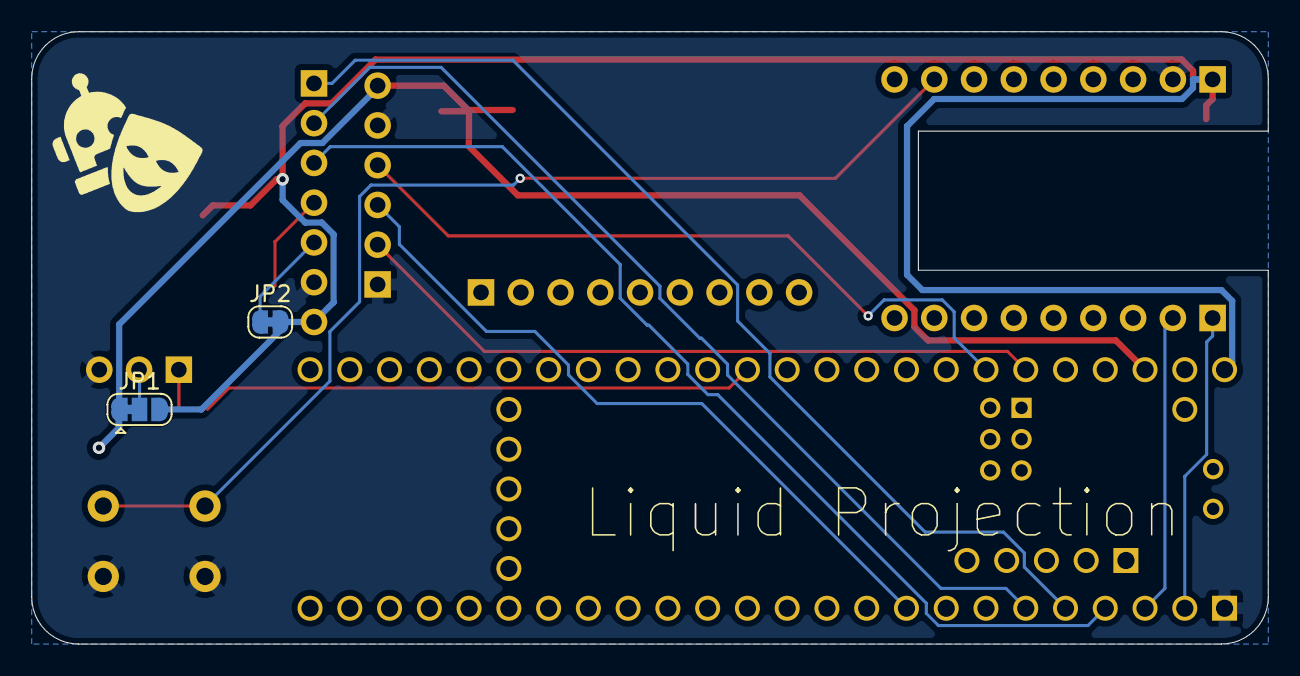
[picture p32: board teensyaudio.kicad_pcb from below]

Board: 2 copper layers, 79.0 x 39.1 mm, 19 parts (3 on the bottom side), 17 nets.

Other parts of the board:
G: LOGO; logo

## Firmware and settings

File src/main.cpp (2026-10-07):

#include <Arduino.h>
#include <Audio.h>
#include <SD.h>
#include "EspBridge.h"
#include "AudioPlaySdWavMulti.h"
#include "RamPlayer.h"
#include "ConfigLoader.h"
#include "LedAnimator.h"
#include "UsbMaintenance.h"

// ── Audio graph ───────────────────────────────────────────────
// PCM5102A on I2S1 (no codec/I2C — pure I2S-in, analog-out).
// MAX98357A on I2S2 for haptics, replacing the old PWM output —
// both confirmed working, see audioTest/ in the project dir.
AudioPlaySdWavMulti   multiPlayer;
AudioMixer4           stemMixerL;
AudioMixer4           stemMixerR;
AudioMixer4           mainMixerL;
AudioMixer4           mainMixerR;
AudioMixer4           hapticMixer;
AudioAnalyzePeak      hapticPeak;
AudioEffectWaveshaper hapticShaper;   // soft limiter in front of the MAX98357A
AudioOutputI2S        i2sOut;      // PCM5102A — same pins/config as before
AudioOutputI2S2       i2s2Out;     // MAX98357A — replaces AudioOutputPWM
RamPlayer             ramFx;

AudioConnection  pBaseL  (multiPlayer, 0, stemMixerL, 0);
AudioConnection  pBaseR  (multiPlayer, 1, stemMixerR, 0);
AudioConnection  pNarrL  (multiPlayer, 2, stemMixerL, 1);
AudioConnection  pNarrR  (multiPlayer, 2, stemMixerR, 1);
AudioConnection  pOv1L   (multiPlayer, 4, stemMixerL, 2);
AudioConnection  pOv1R   (multiPlayer, 5, stemMixerR, 2);
AudioConnection  pOv2L   (multiPlayer, 6, stemMixerL, 3);
AudioConnection  pOv2R   (multiPlayer, 7, stemMixerR, 3);
AudioConnection  pStemL  (stemMixerL,  0, mainMixerL, 0);
AudioConnection  pStemR  (stemMixerR,  0, mainMixerR, 0);
AudioConnection  pFxL    (ramFx.player,0, mainMixerL, 1);
AudioConnection  pFxR    (ramFx.player,0, mainMixerR, 1);
AudioConnection  pOutL   (mainMixerL,  0, i2sOut,     0);
AudioConnection  pOutR   (mainMixerR,  0, i2sOut,     1);
AudioConnection  pHaptic (multiPlayer, 3, hapticMixer, 0);
AudioConnection  pHapShape(hapticMixer, 0, hapticShaper, 0);
AudioConnection  pHapOutL(hapticShaper, 0, i2s2Out,    0);  // duplicated
AudioConnection  pHapOutR(hapticShaper, 0, i2s2Out,    1);  // mono -> L+R
AudioConnection  pHapPeak(hapticMixer, 0, hapticPeak,  0);  // LED ring tap: BEFORE the limiter

// ── Bridge + LED ──────────────────────────────────────────────
LedAnimator leds;
EspBridge   bridge;

// ── Config ────────────────────────────────────────────────────
#define BOOT_LED_PIN     13   // Teensy onboard LED — SD-mount-failure indicator only
#define EXPERIENCE_FILE  "experience.wav"
#define GAIN_STEP        0.02f
#define GAIN_TICK_MS     20      // period of the gain ramp (overlays, seek fades, ducking)
#define DUCK_ATTACK_MS   40      // general audio drops this fast when an effect starts
#define DUCK_RELEASE_MS  400     // ... and comes back this slowly after it ends
#define HAPTIC_GAIN_DEFAULT   1.0f   // mixer gain in front of the limiter (>1.0 hard-clips)
#define HAPTIC_DRIVE_DEFAULT  0.5f   // soft-limiter drive k; 0 = off, see setHapticDrive()

ExperienceConfig     cfg;
const ChapterConfig* currentChapter = nullptr;

// ── Overlay state ─────────────────────────────────────────────
float narrCurrent = 0.0f, narrTarget = 0.0f;
float ov1Current  = 0.0f, ov1Target  = 0.0f;
float ov2Current  = 0.0f, ov2Target  = 0.0f;

// ── Seek crossfade ────────────────────────────────────────────
enum class SeekState : uint8_t { IDLE, FADE_OUT, SEEK, FADE_IN };
SeekState  seekState    = SeekState::IDLE;
uint32_t   seekTargetMs = 0;
float      stemGain     = 1.0f;
#define    SEEK_FADE_STEP 0.05f

bool experienceStarted = false;

// ── Timed ending ──────────────────────────────────────────────
// A START tag begins the clock. cfg.showEndMs later (config "end_after_min")
// the show wraps up: the chapter that is playing finishes first (a looping one
// finishes its current pass), then the end chapter plays, then sound and LEDs
// go off. Only the start tag (or a reboot) begins it again.
bool     showRunning  = false;   // a start tag was seen, the clock is running
bool     showEnding   = false;   // time is up: finish this chapter, then the end chapter
bool     showOver     = false;   // the end chapter finished: sound and LEDs are off
bool     loopReleased = false;   // a looping chapter was told to stop at its loop end
uint32_t showStartMs  = 0;

elapsedMillis gainRampTimer;
elapsedMillis statusTimer;
elapsedMillis tagCooldown[MAX_TAGS];  // per-tag retrigger cooldown
char    serialBuf[32] = {};
uint8_t serialPos = 0;

// ── Helpers ───────────────────────────────────────────────────
float stepGain(float cur, float tgt) {
    if (fabsf(cur - tgt) <= GAIN_STEP) return tgt;
    return cur + (tgt > cur ? GAIN_STEP : -GAIN_STEP);
}

// Ducking: while a RAM effect plays the general audio is lowered to 'level'
// (config "duck_level", 1.0 = off), quickly down and slowly back up. One step
// per GAIN_TICK_MS; the result multiplies the stem gain on mainMixer channel 0,
// so it works together with the seek fades. Pure function, kept separate so it
// can be tested.
float duckCurrent = 1.0f;

float duckNext(float cur, float level, bool fxPlaying) {
    float span = 1.0f - level;
    if (span <= 0.0f) return 1.0f;                       // ducking off
    float target = fxPlaying ? level : 1.0f;
    float step   = span * GAIN_TICK_MS / (target < cur ? DUCK_ATTACK_MS : DUCK_RELEASE_MS);
    if (fabsf(cur - target) <= step) return target;
    return cur + (target > cur ? step : -step);
}

void applyOverlayDefaults(const ChapterConfig& ch) {
    if (ch.overlayMode == OverlayMode::KEEP) {
        Serial.println("[Chapter] Keeping overlay state");
        return;
    }
    ov1Target  = ch.overlays.ov1  ? 1.0f : 0.0f;
    ov2Target  = ch.overlays.ov2  ? 1.0f : 0.0f;
    narrTarget = ch.overlays.narr ? 1.0f : 0.0f;
    Serial.printf("[Chapter] Overlays: ov1=%s ov2=%s narr=%s\n",
                  ch.overlays.ov1  ? "ON":"OFF",
                  ch.overlays.ov2  ? "ON":"OFF",
                  ch.overlays.narr ? "ON":"OFF");
}

void goToChapter(const char* id) {
    const ChapterConfig* ch = ConfigLoader::findChapter(id, cfg);
    if (!ch) { Serial.printf("[Chapter] '%s' not found\n", id); return; }
    currentChapter = ch;
    loopReleased   = false;
    seekTargetMs   = ch->startMs;
    seekState      = SeekState::FADE_OUT;
    if (ch->onEnterFx >= 0) ramFx.play(ch->onEnterFx);
    applyOverlayDefaults(*ch);
    if (ch->looping) {
        multiPlayer.setLoop(ch->startMs, ch->loopEndMs);
        Serial.printf("[Chapter] -> '%s' LOOP %lu-%lu ms\n", ch->id, ch->startMs, ch->loopEndMs);
    } else {
        multiPlayer.setPlayOnce(ch->startMs, ch->loopEndMs);
        Serial.printf("[Chapter] -> '%s' ONCE %lu-%lu ms\n", ch->id, ch->startMs, ch->loopEndMs);
    }
    leds.setBackgroundFromParams(ch->ledBackground);
    leds.triggerForegroundFromParams(ch->ledEnter);
}

void applyOverlayAction(const char* target, OverlayValue val) {
    float* tgt = nullptr;
    if      (strcmp(target, "ov1")  == 0) tgt = &ov1Target;
    else if (strcmp(target, "ov2")  == 0) tgt = &ov2Target;
    else if (strcmp(target, "narr") == 0) tgt = &narrTarget;
    else { Serial.printf("[Overlay] Unknown: %s\n", target); return; }
    switch (val) {
        case OverlayValue::ON:     *tgt = 1.0f; break;
        case OverlayValue::OFF:    *tgt = 0.0f; break;
        case OverlayValue::TOGGLE: *tgt = (*tgt > 0.5f) ? 0.0f : 1.0f; break;
    }
    Serial.printf("[Overlay] %s -> %.0f\n", target, *tgt);
}

void returnToIdle() {
    experienceStarted = false;
    currentChapter    = nullptr;
    ov1Target = 0.0f; ov2Target = 0.0f; narrTarget = 0.0f;
    multiPlayer.stop();
    leds.setBackgroundFromParams(cfg.idleLed);
    Serial.println("[Idle] Experience ended — waiting for tag tap");
}

void startExperience() {
    if (experienceStarted) return;
    experienceStarted = true;
    if (!multiPlayer.play(EXPERIENCE_FILE)) {
        Serial.println("[Audio] ERROR: experience.wav not found");
        experienceStarted = false;
        return;
    }
    Serial.println("[Audio] Experience started");
}

// ── Feedback sounds + person-tag lock ─────────────────────────
// Three short effects, played from RAM (slots come from config.json "sounds"):
//   connect - a person tag was accepted      denied - a person tag was refused
//   ready   - a chapter ended, back at base
bool encounterLockOn = false;      // from config "encounter_lock"; 'lock on|off' changes it live

void playSound(int8_t slot) { if (slot >= 0) ramFx.play(slot); }

enum class TagVerdict : uint8_t { RUN, DENIED };

// Person tags start a chapter. While the show is ending they are refused (no
// new encounters). With the lock on they are only accepted while the base
// chapter is playing; with it off (testing) they work at any time.
TagVerdict judgeTag(const TagConfig& tag, bool lockOn,
                    const ChapterConfig* current, const char* baseId, bool ending) {
    if (tag.type != TagType::PERSON) return TagVerdict::RUN;
    if (ending)  return TagVerdict::DENIED;
    if (!lockOn) return TagVerdict::RUN;
    return (current && strcmp(current->id, baseId) == 0) ? TagVerdict::RUN : TagVerdict::DENIED;
}

void dispatchTag(const TagConfig& tag, const char* tappedUid = nullptr) {
    Serial.printf("[Tag] '%s' (%s)\n", tag.label, tappedUid ? tappedUid : tag.uid);
    for (uint8_t i = 0; i < tag.actionCount; i++) {
        const Action& a = tag.actions[i];
        switch (a.type) {
            case ActionType::CHAPTER: goToChapter(a.target); break;
            case ActionType::OVERLAY: applyOverlayAction(a.target, a.overlayValue); break;
            case ActionType::FX:      if (a.fxSlot >= 0) ramFx.play(a.fxSlot); break;
            case ActionType::LED:     leds.triggerForegroundFromParams(a.ledParams); break;
        }
    }
}

const char* tagTypeName(TagType t) {
    return t == TagType::PERSON ? "person" : t == TagType::START ? "start"
         : t == TagType::DEVICE ? "device" : "location";
}

// ── Timed ending: the functions ───────────────────────────────
void beginShow() {                       // the start tag was seen (or 'show start')
    showStartMs  = millis();
    showRunning  = true;
    showEnding   = false;
    showOver     = false;
    loopReleased = false;
    if (cfg.showEndMs > 0)
        Serial.printf("[Show] started - '%s' follows after %.1f min\n", cfg.endChapter, cfg.showEndMs / 60000.0f);
    else
        Serial.println("[Show] started (no end time set)");
}

// Time is up (or 'show end'): let the current chapter finish, then the end chapter.
void triggerShowEnd() {
    if (showEnding || showOver) return;
    showEnding = true;
    Serial.printf("[Show] time is up - '%s' follows when the current chapter has finished\n", cfg.endChapter);
    // A looping chapter has no end of its own: let this pass run out.
    if (currentChapter && currentChapter->looping && strcmp(currentChapter->id, cfg.endChapter) != 0) {
        multiPlayer.setPlayOnce(currentChapter->startMs, currentChapter->loopEndMs);
        loopReleased = true;
    }
}

void showTick() {                        // call every loop()
    if (showRunning && !showEnding && !showOver && cfg.showEndMs > 0 &&
        millis() - showStartMs >= cfg.showEndMs)
        triggerShowEnd();
}

// The end chapter has finished: everything off.
void endShow() {
    showRunning = false; showEnding = false; showOver = true; loopReleased = false;
    experienceStarted = false;
    currentChapter    = nullptr;
    ov1Target = 0.0f; ov2Target = 0.0f; narrTarget = 0.0f;
    multiPlayer.stop();                                  // silence (the haptics too)
    leds.setBackground("off", 0x000000, 0.0f, 0.0f);     // ring dark
    Serial.println("[Show] over - sound and LEDs off. Tap the start tag (or reboot) to begin again");
}

void printShow() {
    if (showOver) { Serial.println("[Show] over - sound and LEDs off; tap the start tag or reboot"); return; }
    if (showEnding) {
        Serial.printf("[Show] time is up - '%s' follows when '%s' has finished\n",
                      cfg.endChapter, currentChapter ? currentChapter->id : "-");
    } else if (showRunning && cfg.showEndMs > 0) {
        float el = (millis() - showStartMs) / 60000.0f, tot = cfg.showEndMs / 60000.0f;
        Serial.printf("[Show] running %.1f of %.1f min - the end starts in %.1f min (the chapter then playing finishes first)\n",
                      el, tot, tot > el ? tot - el : 0.0f);
    } else if (showRunning) {
        Serial.println("[Show] running, no end time set");
    } else if (cfg.showEndMs > 0) {
        Serial.printf("[Show] waiting for the start tag (the end follows %.1f min after it)\n", cfg.showEndMs / 60000.0f);
    } else {
        Serial.println("[Show] waiting for the start tag; no end time set");
    }
}

// ── Haptic soft limiter ───────────────────────────────────────
// hapticMixer -> hapticShaper -> I2S2 (MAX98357A). The shaper pushes every
// sample through y = tanh(k*x) / tanh(k): full scale in is still full scale
// out, but quieter parts get louder (small-signal gain k/tanh(k)) and peaks
// round off instead of hard-clipping. k = 0 is a straight line (bypass).
//
// An AudioEffectWaveshaper with no table outputs SILENCE, so setup() must
// install one before any audio is expected.
#define HAPTIC_SHAPE_POINTS 1025          // library requires 2^n + 1
float hapticGain    = HAPTIC_GAIN_DEFAULT;
float hapticDrive   = HAPTIC_DRIVE_DEFAULT;
float hapticPeakMax = 0.0f;               // loudest source peak seen (pre-limiter)

// Pure maths, kept separate so it can be tested: fills n points over -1..+1.
void buildHapticTable(float* table, int n, float k) {
    const bool  bypass = (k < 0.01f);
    const float norm   = bypass ? 1.0f : tanhf(k);
    for (int i = 0; i < n; i++) {
        float x = -1.0f + 2.0f * (float)i / (float)(n - 1);
        table[i] = bypass ? x : tanhf(k * x) / norm;
    }
}

void setHapticDrive(float k) {
    static float table[HAPTIC_SHAPE_POINTS];
    if (k < 0.0f) k = 0.0f;
    if (k > 8.0f) k = 8.0f;
    buildHapticTable(table, HAPTIC_SHAPE_POINTS, k);
    // shape() frees and reallocates the table the audio interrupt reads,
    // so the audio update must not run while it swaps.
    AudioNoInterrupts();
    hapticShaper.shape(table, HAPTIC_SHAPE_POINTS);
    AudioInterrupts();
    hapticDrive = k;
}

void printHaptic() {
    float smallSignal = (hapticDrive < 0.01f) ? 1.0f : hapticDrive / tanhf(hapticDrive);
    Serial.printf("[Haptic] gain %.2f  drive %.2f (%+.1f dB small-signal, peaks capped at full scale)\n",
                  hapticGain, hapticDrive, 20.0f * log10f(smallSignal));
    if (hapticPeakMax > 0.0f)
        Serial.printf("[Haptic] loudest source peak since boot/reset: %.2f (%.1f dBFS)\n",
                      hapticPeakMax, 20.0f * log10f(hapticPeakMax));
    else
        Serial.println("[Haptic] no source signal seen yet since boot/reset");
}

// ── USB maintenance mode ──────────────────────────────────────
// Stops playback (which closes experience.wav) so the PC can safely read
// and write the SD card over MTP. Leave with 'reboot' — that also reloads
// config.json.
void enterUsbMaintenance() {
    if (usbMaintActive()) { Serial.println("[USB] already in maintenance mode"); return; }
    Serial.println("[USB] Entering maintenance mode — stopping playback");
    multiPlayer.stop();                 // closes the experience file
    experienceStarted = false;
    currentChapter    = nullptr;
    seekState         = SeekState::IDLE;
    stemGain          = 1.0f;
    ov1Target = 0.0f; ov2Target = 0.0f; narrTarget = 0.0f;
    leds.setBackground("spin", 0x00CCFF, 0.8f, 0.5f);   // cyan spinner = maintenance
    usbMaintStart();
    Serial.println("[USB] SD card is shared over MTP as 'SD Card'. Type 'reboot' to leave.");
}
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
void loop() {

    if (usbMaintActive()) usbMaintUpdate();   // keep MTP responsive

    // Drive the ring from live haptic level — fast attack, slow decay
    if (hapticPeak.available()) {
        float p = hapticPeak.read();
        leds.setBeatLevel(p);
        if (p > hapticPeakMax) hapticPeakMax = p;
    }
    leds.update();

    if (gainRampTimer >= GAIN_TICK_MS) {
        gainRampTimer = 0;

        narrCurrent = stepGain(narrCurrent, narrTarget);
        ov1Current  = stepGain(ov1Current,  ov1Target);
        ov2Current  = stepGain(ov2Current,  ov2Target);
        duckCurrent = duckNext(duckCurrent, cfg.duckLevel, ramFx.isPlaying());
        stemMixerL.gain(1, narrCurrent); stemMixerR.gain(1, narrCurrent);
        stemMixerL.gain(2, ov1Current);  stemMixerR.gain(2, ov1Current);
        stemMixerL.gain(3, ov2Current);  stemMixerR.gain(3, ov2Current);

        switch (seekState) {
            case SeekState::FADE_OUT:
                stemGain -= SEEK_FADE_STEP;
                if (stemGain <= 0.0f) { stemGain = 0.0f; seekState = SeekState::SEEK; }
                break;
            case SeekState::SEEK:
                multiPlayer.seekMs(seekTargetMs);
                seekState = SeekState::FADE_IN;
                break;
            case SeekState::FADE_IN:
                stemGain += SEEK_FADE_STEP;
                if (stemGain >= 1.0f) { stemGain=1.0f; seekState=SeekState::IDLE; }
                break;
            default: break;
        }
        // stems x seek fade x ducking
        mainMixerL.gain(0, stemGain * duckCurrent); mainMixerR.gain(0, stemGain * duckCurrent);
    }

    showTick();   // timed ending: has the show run long enough?

    // Detect end of a chapter that plays once (a non-looping one, or a loop
    // released for the end of the show) → end chapter, returns_to, or idle
    if (experienceStarted &&
        currentChapter && (!currentChapter->looping || loopReleased) &&
        seekState == SeekState::IDLE &&
        !multiPlayer.isPlaying()) {
        if (strcmp(currentChapter->id, cfg.endChapter) == 0) {
            endShow();                                  // the end chapter is done: sound + LEDs off
        } else if (showEnding) {
            if (ConfigLoader::findChapter(cfg.endChapter, cfg)) {
                Serial.printf("[Chapter] '%s' finished -> '%s' (time is up)\n",
                              currentChapter->id, cfg.endChapter);
                goToChapter(cfg.endChapter);            // no 'ready' sound: nothing follows
            } else {
                Serial.printf("[Show] end chapter '%s' not found - ending without it\n", cfg.endChapter);
                endShow();
            }
        } else if (strlen(currentChapter->returnsTo) > 0) {
            Serial.printf("[Chapter] '%s' finished -> '%s'\n",
                          currentChapter->id, currentChapter->returnsTo);
            if (strcmp(currentChapter->returnsTo, cfg.baseChapter) == 0) playSound(cfg.soundReady);
            goToChapter(currentChapter->returnsTo);
        } else {
            returnToIdle();
        }
    }

    // ── ESP32 body bridge — confirmed tag connection events ───
    // Non-blocking line reader; near-instant, no polling interval needed.
    char uid[20] = {};
    if (bridge.poll(uid) && !usbMaintActive()) {
        int8_t idx = ConfigLoader::findTagIndex(uid, cfg);
        if (idx < 0) {
            Serial.printf("[Bridge] Unknown tag: %s -- add to config.json\n", uid);
        } else {
            const TagConfig& tag = cfg.tags[idx];
            if (tag.cooldownMs > 0 && tagCooldown[idx] < tag.cooldownMs) {
                uint32_t remaining = tag.cooldownMs - tagCooldown[idx];
                Serial.printf("[Tag] '%s' cooling down (%lums left)\n",
                              tag.label, remaining);
            } else {
                tagCooldown[idx] = 0;  // reset cooldown
                if (showOver && tag.type != TagType::START) {
                    Serial.printf("[Tag] '%s' ignored - the show is over (tap the start tag to begin again)\n", tag.label);
                } else if (judgeTag(tag, encounterLockOn, currentChapter, cfg.baseChapter, showEnding) == TagVerdict::DENIED) {
                    if (showEnding)
                        Serial.printf("[Tag] '%s' ignored - the show is ending\n", tag.label);
                    else
                        Serial.printf("[Tag] '%s' refused - only accepted in '%s' (now in '%s')\n",
                                      tag.label, cfg.baseChapter, currentChapter ? currentChapter->id : "-");
                    playSound(cfg.soundDenied);
                } else {
                    if (!experienceStarted) startExperience();
                    dispatchTag(tag, uid);
                    if (tag.type == TagType::PERSON) playSound(cfg.soundConnect);
                    if (tag.type == TagType::START)  beginShow();
                }
            }
        }
    }

    while (Serial.available()) {
        char c = Serial.read();
        if (c == '\n' || c == '\r') {
            if (serialPos > 0) {
                serialBuf[serialPos] = '\0';
                serialPos = 0;
                handleSerialCommand(serialBuf);
            }
        } else if (serialPos < sizeof(serialBuf) - 1) {
            serialBuf[serialPos++] = c;
        }
    }

    if (statusTimer >= 3000) {
        statusTimer = 0;
        if (!usbMaintActive()) Serial.printf("[%6lu ms] ch:%s pos:%lu/%lu narr:%.2f ov1:%.2f ov2:%.2f  bridge:%s  CPU:%.1f%%  mem:%u/%u\n",
                      millis(),
                      currentChapter ? currentChapter->id : "none",
                      multiPlayer.positionMs(), multiPlayer.lengthMs(),
                      narrCurrent, ov1Current, ov2Current,
                      bridge.isAlive() ? "ok" : "DOWN",
                      AudioProcessorUsage(),
                      AudioMemoryUsage(), AudioMemoryUsageMax());
    }
}

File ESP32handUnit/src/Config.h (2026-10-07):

#pragma once

// ── NeoPixel ring ─────────────────────────────────────────────
#define LED_PIN          4
#define LED_COUNT        16
#define LED_TYPE         WS2812B
#define LED_COLOR_ORDER  GRB

// ── Vibration motor ───────────────────────────────────────────
#define MOTOR_PIN   2
#define MOTOR_FREQ  20000   // 20kHz — inaudible
#define MOTOR_RES   8       // 8-bit = 0-255
#define MOTOR_CH    0
#define MOTOR_MAX   200

// ── I2C bus — VL53L0X on Wire (GPIO7/8) ──────────────────────
#define TOF_SDA     7
#define TOF_SCL     8
#define TOF_FREQ    400000
#define TOF_XSHUT   1

// ── NFC interface selection ───────────────────────────────────
// 0 = I2C  (DIP: SEL0=HIGH SEL1=LOW  — Wire1 on GPIO5/6)
// 1 = UART (DIP: SEL0=LOW  SEL1=LOW  — Serial1 on GPIO16/17)
#define NFC_UART    1

#if NFC_UART
  #define NFC_TX_PIN    6      // ESP TX → PN532 RX
  #define NFC_RX_PIN    5      // ESP RX ← PN532 TX
  #define NFC_BAUD     115200
  #define NFC_RST_PIN  10      // GPIO10 → PN532 RST — required to recover stuck TX line
#else
  #define NFC_SDA      5
  #define NFC_SCL      6
  #define NFC_FREQ     400000
  #define NFC_RST_PIN  10      // GPIO10 → PN532 RST — required to recover stuck TX line
#endif

// ── NFC power management ─────────────────────────────────────
// Time PN532 spends in PowerDown between polls (ms).
// 0 = always on (max responsiveness, ~80mA continuous)
// 200 = good balance — tag detected within 220ms, ~8mA average
// 500 = max savings — tag detected within 520ms, ~3mA average
#define NFC_SLEEP_MS   0      // 0 = always on — eliminates powerdown as a variable

// ── Proximity ─────────────────────────────────────────────────
#define PROX_FAR_MM   300
#define PROX_NEAR_MM  20

// ── Status LED (onboard WS2812B) ──────────────────────────────
#define STATUS_LED_PIN  48

// ── Power management master switch ───────────────────────────
// 0 = always on, no sleep, no battery monitor, no button sleep
// 1 = full power management (deep sleep, button, battery)
#define POWER_MANAGEMENT 1

// ── Power management ──────────────────────────────────────────
#define BUTTON_PIN      9    // button to GND, internal pull-up
#define VBAT_ADC_PIN    3    // 100k+100k voltage divider from VBAT

// Sleep trigger: 1 = long press, 0 = double press
#define USE_LONG_PRESS    1
#define POWER_HOLD_MS  2000  // hold 2s → sleep
#define DOUBLE_PRESS_MS 500  // two taps within 500ms → sleep

// Battery thresholds in millivolts (1S LiPo: 3.0–4.2V)
#define VBAT_LOW_MV    3200  // rapid blink warning
#define VBAT_CRIT_MV   2000  // auto shutdown
#define VBAT_CHECK_MS  10000 // check interval

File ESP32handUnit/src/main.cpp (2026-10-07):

#include <Arduino.h>
#include "Config.h"
#include "Motor.h"
#include "Proximity.h"
#include "TouchManager.h"
#include "LedRing.h"
#include "NfcTask.h"
#include "EspNow.h"
#include "StatusLed.h"
#include "PowerManager.h"
#include "Cli.h"

void setup() {
    setCpuFrequencyMhz(80);   // 80MHz is plenty — 240MHz default runs hot
    Serial.begin(115200);
    delay(300);
    Serial.println("\n=== Hand Unit ===");

#if POWER_MANAGEMENT
    buttonSetup();
    esp_sleep_wakeup_cause_t wakeReason = esp_sleep_get_wakeup_cause();
    if (wakeReason != ESP_SLEEP_WAKEUP_EXT1) {
        Serial.println("[PWR] Fresh boot → sleep. Press button to start.");
        delay(50);
        while (digitalRead(BUTTON_PIN) == LOW) delay(10);
        delay(100);
        powerSleepNow();
    }
    Serial.println("[PWR] Woke from button — release to continue...");
    while (digitalRead(BUTTON_PIN) == LOW) delay(10);
    delay(200);
#else
    powerPrintWakeReason();
#endif

    motorSetup();
    proximitySetup();
    ledSetup(40);
    statusLedSetup();
    batterySetup();
    nfcSetup();      // RST sequence + 50ms delay built in
    espNowSetup();

    ledSolid(nfcReady && tofReady ? CRGB(0,40,0) : CRGB(40,20,0));
    motorBurstStart(2, 160, 60, 40);
    delay(300);
    ledOff();

    printHelp();
}

uint32_t ledTimer      = 0;
uint32_t streamTimer   = 0;
uint32_t proxSendTimer = 0;

void loop() {
    uint32_t now = millis();

    powerUpdate(now);
    if (shortPressEvent) {
        shortPressEvent = false;
        espNowConfirmPairing();
    }
    bool pairingPending = pendingPairMs != 0 &&
                          (now - pendingPairMs) < PAIR_REQUEST_WINDOW_MS;
    statusLedUpdate(now, peerPaired, batLow, pairingPending);

    cliPoll();
    proximityRead();
    touchUpdate(now);

    if (touchState == TouchState::RELEASED) {
        motorProxSet(0);
    } else if (tofReady && distValid(lastDist) && lastDist < PROX_FAR_MM
               && ledMode == LedMode::IDLE) {
        float t = 1.0f - (float)(lastDist - PROX_NEAR_MM)
                         / (float)(PROX_FAR_MM - PROX_NEAR_MM);
        motorProxSet((uint8_t)(constrain(t,0.0f,1.0f)*t*MOTOR_MAX));
    } else {
        motorProxSet(0);
    }

    char uid[20] = {};
    if (nfcQueue && xQueueReceive(nfcQueue, uid, 0) == pdTRUE) {
        Serial.printf("[NFC] Tag: %s\n", uid);
        statusOnNfc();
        espNowSendNfc(uid);
        if (touchState == TouchState::IDLE) {
            motorBurstStart(2, 230, 40, 30);
            touchConnect(now);
            statusOnTouch();
            espNowSendTouch(uid);
            ledSolid(CRGB(200,200,200));
            delay(80);
        } else {
            Serial.println("[Touch] Ignored — still in silence");
        }
    }

    if (now - proxSendTimer >= 100) {
        proxSendTimer = now;
        espNowSendProximity();
    }

    if (now - ledTimer >= 40) {
        ledTimer = now;
        ledUpdate(now);
    }

    if (streaming && tofReady && (now - streamTimer >= 100)) {
        streamTimer = now;
        uint8_t bars = (uint8_t)map(constrain(lastDist,0,500),0,500,30,0);
        char bar[32]={}; memset(bar,'#',bars);
        Serial.printf("%4u mm  %s\n", lastDist, bar);
    }

    // Yield 1ms — lets idle task run, allows CPU light sleep between iterations
    vTaskDelay(pdMS_TO_TICKS(1));
}

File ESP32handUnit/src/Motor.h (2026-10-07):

#pragma once
#include <Arduino.h>
#include "Config.h"

// ── LEDC API version switch ────────────────────────────────────
// 0 = old channel-based API — Arduino-ESP32 core 2.x
//     (official platformio/espressif32 6.x).
//     ledcSetup() + ledcAttachPin(), ledcWrite(CHANNEL, duty)
// 1 = new pin-based API — Arduino-ESP32 core 3.x (pioarduino).
//     ledcAttach(pin, freq, res), ledcWrite(PIN, duty); MOTOR_CH unused.
//
// Espressif's 2.x -> 3.0 migration guide puts this break at the 3.0
// boundary, so the default is picked from the core's own version macro.
// Force it either way with -DMOTOR_LEDC_NEW_API=0/1 in build_flags, or
// by defining it above this include.
#ifndef MOTOR_LEDC_NEW_API
  #if defined(ESP_ARDUINO_VERSION_MAJOR) && ESP_ARDUINO_VERSION_MAJOR >= 3
    #define MOTOR_LEDC_NEW_API 1
  #else
    #define MOTOR_LEDC_NEW_API 0
  #endif
#endif

#if MOTOR_LEDC_NEW_API
  #define MOTOR_LEDC_ATTACH()  ledcAttach(MOTOR_PIN, MOTOR_FREQ, MOTOR_RES)
  #define MOTOR_LEDC_WRITE(d)  ledcWrite(MOTOR_PIN, (d))
#else
  #define MOTOR_LEDC_ATTACH()  do { ledcSetup(MOTOR_CH, MOTOR_FREQ, MOTOR_RES); \
                                    ledcAttachPin(MOTOR_PIN, MOTOR_CH); } while (0)
  #define MOTOR_LEDC_WRITE(d)  ledcWrite(MOTOR_CH, (d))
#endif

// ── Motor burst — esp_timer ISR ───────────────────────────────
// Fires independently of loop() timing.
// motorProxSet() is ignored while a burst is active.

struct MotorBurst {
    volatile bool     active  = false;
    volatile uint8_t  pulses  = 0;
    volatile uint8_t  done    = 0;
    volatile uint8_t  duty    = 0;
    volatile uint16_t onMs    = 0;
    volatile uint16_t offMs   = 0;
    volatile bool     motorOn = false;
} motorBurst;

esp_timer_handle_t motorTimer;

void IRAM_ATTR motorTimerCb(void*) {
    if (!motorBurst.active) return;
    if (motorBurst.motorOn) {
        MOTOR_LEDC_WRITE(0);
        motorBurst.motorOn = false;
        esp_timer_start_once(motorTimer, motorBurst.offMs * 1000ULL);
    } else {
        if (++motorBurst.done >= motorBurst.pulses) {
            motorBurst.active = false; return;
        }
        MOTOR_LEDC_WRITE(motorBurst.duty);
        motorBurst.motorOn = true;
        esp_timer_start_once(motorTimer, motorBurst.onMs * 1000ULL);
    }
}

void motorSetup() {
    MOTOR_LEDC_ATTACH();
    MOTOR_LEDC_WRITE(0);
    esp_timer_create_args_t args = {};
    args.callback = motorTimerCb;
    args.name     = "motor";
    esp_timer_create(&args, &motorTimer);
}

void motorBurstStart(uint8_t pulses = 3, uint8_t duty = 200,
                     uint16_t onMs = 55, uint16_t offMs = 35) {
    esp_timer_stop(motorTimer);
    motorBurst.active  = true;  motorBurst.pulses  = pulses;
    motorBurst.done    = 0;     motorBurst.duty    = duty;
    motorBurst.onMs    = onMs;  motorBurst.offMs   = offMs;
    motorBurst.motorOn = true;
    MOTOR_LEDC_WRITE(duty);
    esp_timer_start_once(motorTimer, onMs * 1000ULL);
}

// Continuous intensity — ignored while burst is active
void motorProxSet(uint8_t duty) {
    if (!motorBurst.active) MOTOR_LEDC_WRITE(duty);
}
